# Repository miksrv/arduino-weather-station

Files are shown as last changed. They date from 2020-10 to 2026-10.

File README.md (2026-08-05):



<!-- PROJECT TITLE -->
Arduino Weather Station is a complete DIY weather-monitoring project powered by Arduino or ESP32. It collects real environmental data and provides a full backend API (PHP + MySQL + CodeIgniter) and a modern web interface (Next.js + Redux RTK) for real-time and historical weather analysis.
You can use this repository to build your own fully-featured weather station - and if you like it, please give the project a star :)

<div align="center">
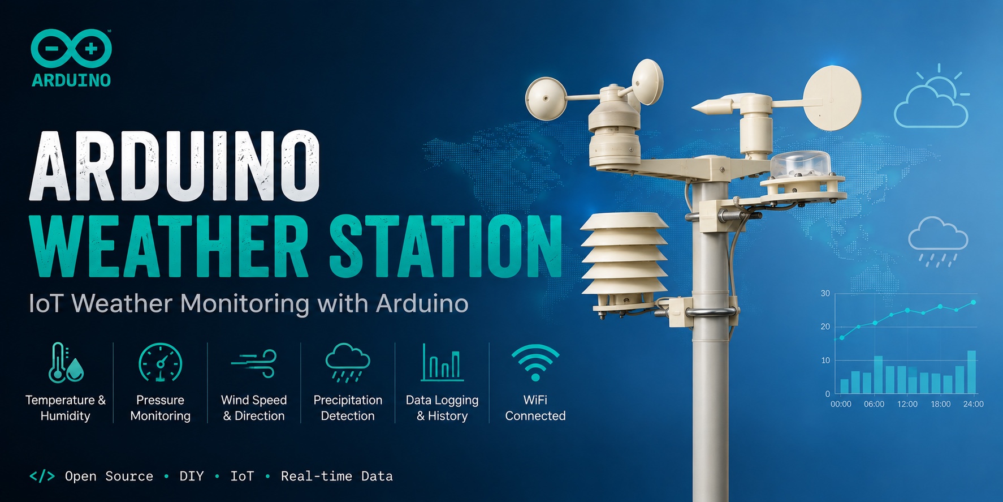
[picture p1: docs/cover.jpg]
  

<h3>Arduino Weather Station</h3>

<a href="https://meteo.miksoft.pro" target="_blank">Demo</a>
·
<a href="https://github.com/miksrv/arduino-weather-station/issues/new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">Report Bug</a>
·
<a href="https://github.com/miksrv/arduino-weather-station/issues/new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">Request Feature</a>
·
<a href="#contact">Contact</a>
</div>

<br />

<!-- PROJECT BADGES -->
<div align="center">

[][contributors-url]
[][forks-url]
[][stars-url]
[][issues-url]
[][license-url]







</div>

---

<!-- TABLE OF CONTENTS -->
### Table of Contents

- [About of Project](#about-of-project)
    - [Key Features](#key-features)
    - [Measured Parameters](#measured-parameters)
    - [Built With](#built-with)
- [Build Guide](#build-guide)
- [Installation](#installation)
- [Usage](#usage)
- [Screenshots and Demos](#screenshots-and-demos)
- [Contributing](#contributing)
- [License](#license)
- [Acknowledgments](#acknowledgments)
- [Contact](#contact)

## Documentation

Detailed documentation lives in the [`/docs`](./docs) directory:

- [Architecture](./docs/architecture.md) — system design, data flow, external services
- [Backend](./docs/backend.md) — PHP/CodeIgniter API reference and setup
- [Frontend](./docs/frontend.md) — Next.js app structure and development
- [Development Guide](./docs/development.md) — local setup, commands, conventions
- [Testing Guide](./docs/testing.md) — running tests, coverage, CI pipeline
- [Anomaly Monitor](./docs/anomaly-monitor.md) — meteorological anomaly detection, flood risk scoring, and visualization
- [Precipitation Calendar](./docs/precipitation-calendar.md) — annual rainfall calendar, daily totals, wet/dry streaks, and monthly breakdown

<!-- ABOUT OF PROJECT -->
## About of Project

Arduino Weather Station is a modular DIY platform for collecting and analyzing weather data. It supports Arduino or ESP32, works with a wide range of sensors, and sends real-time measurements to a backend server. Data is processed, stored, and exposed through a clean REST API and a modern Next.js dashboard.

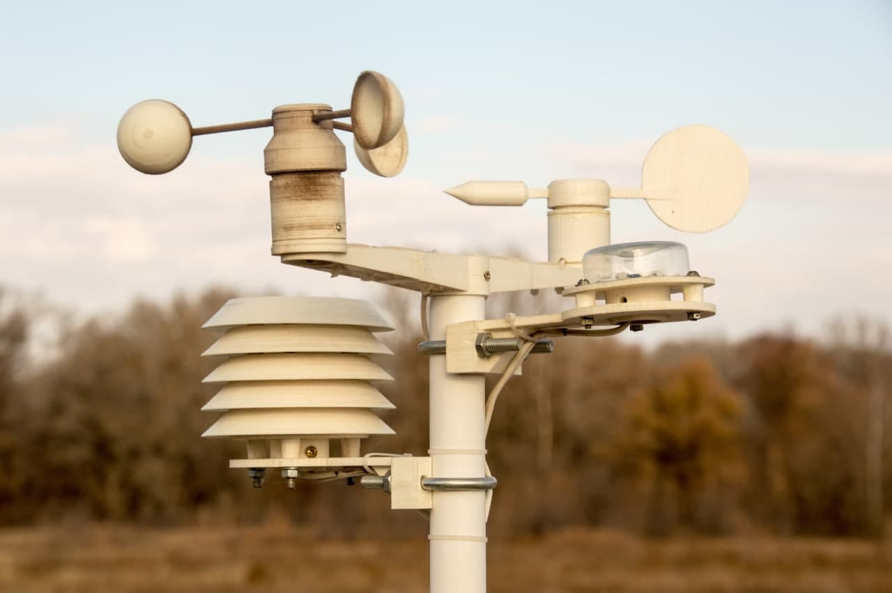
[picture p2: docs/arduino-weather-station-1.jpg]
Arduino Weather Station


### Key Features:
- **Live data**: continuous sensor monitoring.
- **Historical logging**: long-term storage in MySQL with detailed analytics.
- **Web dashboard**: access your station from anywhere — charts, stats, trends.
- **REST API**: integrate weather data into external apps or services.
- **Modular design**: easily add new sensors or expand the system.

### Measured Parameters:
- Temperature
- Feels like temperature
- Humidity
- Dew point
- UV intensity
- Solar energy
- Solar radiation
- Wind speed and direction
- Atmospheric pressure
- Precipitation levels
- Cloud cover

The system is highly customizable - from a small indoor sensor hub to a full outdoor weather station with complete data logging and visualization.

<p align="right">
  (<a href="#top">Back to top</a>)
</p>

### Built With

The Arduino Weather Station project leverages a wide range of technologies across various layers of the system:

- [][c++-url] Programming language used for the Arduino firmware.
- [][php-url] Server-side scripting language for the backend API.
- [][mysql-url] Database system for storing weather data.
- [][js-url] Core languages used in frontend development.
- [][ts-url] TypeScript extends JavaScript by adding types to the language.
- [][nextjs-url] React-based frontend framework for building the user interface.
- [][redux-url] State management for the frontend, providing predictable and centralized state.
- [][nodejs-url] JavaScript runtime used for frontend development and package management.
- [][sass-url] Styling the user interface.
- [][githubactions-url] Continuous integration and deployment pipeline for automating tests and deployment processes.
- [][sonarcloud-url] Code quality and security analysis.

This project also includes custom-designed components for measuring airflow, voltage, and light, making use of 3D printing for hardware integration.

<p align="right">
  (<a href="#top">Back to top</a>)
</p>

<!-- BUILD GUIDE -->
## Build Guide
This project is fairly extensive and includes hardware, firmware, backend, and frontend components. You can choose to build the entire weather station from start to finish, or you can use only the parts you need - whether it's the Arduino/ESP32 firmware, the server API, the 3D-printed enclosure, or the web dashboard.

The guide below walks you through each stage step by step: printing the enclosure, assembling the hardware, setting up the server, and configuring the client application.

### 3D Printing the Enclosure
All 3D-printable parts for the weather station are located in the [models](https://github.com/miksrv/arduino-weather-station/tree/main/models)
directory, which includes a detailed guide on recommended print settings, assembly notes, and an overview of each component.

The enclosure is fully modular and allows you to print only the parts needed for your specific sensor configuration. Most models are optimized for FDM 3D printers and require no supports unless otherwise noted.

Before printing, review the [Models README](./models/README.md) to choose the correct components and verify recommended materials and orientation.

<!-- INSTALLATION -->
## Installation

Follow these steps to install and run the Arduino Weather Station project on your local machine.

### Prerequisites

Make sure you have the following installed on your system:
- **Node.js** (v20 or higher)
- **NPM** or **Yarn** (for frontend dependencies)
- **PHP** (v8.2 or higher)
- **Composer** (for backend dependencies)
- **MySQL** (or any compatible database) — or **Docker** to run the bundled local database (see step 2 below)
- **Arduino IDE** (for programming the Arduino microcontroller)

### 1. Clone the repository

```bash
git clone https://github.com/miksrv/arduino-weather-station.git
cd arduino-weather-station
```

### 2. Backend Setup (PHP + CodeIgniter)

1. Navigate to the `server` folder:

   ```bash
   cd server
   ```

2. Install PHP dependencies using Composer:

   ```bash
   composer install
   ```

3. Start the local MySQL database using Docker (skip this if you already have a MySQL-compatible database running):

   ```bash
   docker-compose -f ../config/docker-compose.yml up -d
   ```

4. Create a `.env` file and configure your environment variables, such as database connection settings:

   ```bash
   cp env .env
   ```

    The default `database.development.*` values already match the docker-compose database from step 3, so no changes are needed if you used Docker. Don't forget to set the parameter `app.arduino.token` = '' in the .env file. This token will be used for proper authentication of the Arduino weather station when transmitting data to the server. The same token will need to be set in the Arduino sketch, which will be described in step 4.

5. Migrate the database:

   ```bash
   php spark migrate
   ```

6. Start the backend server (built-in PHP server or any web server of your choice):

   ```bash
   php spark serve
   ```

### 3. Frontend Setup (Next.js + Redux)

1. Navigate to the `client` folder:

   ```bash
   cd ../client
   ```
   
2. Copy file `env` to `.env.local` and set the following environment variables:

   ```bash
   cp env .env.local
   ```
   
    ```bash
    NEXT_PUBLIC_API_HOST = 'http://localhost:8080/'
    NEXT_PUBLIC_SITE_LINK = 'http://localhost:3000/'
    NEXT_PUBLIC_STORAGE_KEY = 'meteo'
    ```

3. Install frontend dependencies:

   ```bash
   yarn install
   ```

4. Run the frontend in development mode:

   ```bash
   yarn run dev
   ```

5. To build the project for production:

   ```bash
   yarn run build
   ```

6. Optionally, start the production build:

   ```bash
   yarn start
   ```

### 4. Arduino Setup

1. Open the [Arduino Readme](./arduino/README.md) — it includes the full wiring diagram (which pin/wire connects to which component).
2. Open the Arduino sketch from the `arduino/main` folder in the Arduino IDE.
3. Configure the following parameters in the `main.ino` file for Arduino:
   - `API_SERVER` - the server address for sending data from the weather station.
   - `API_METHOD` - the correct method (if you haven't changed anything in the server settings in this repository, you don't need to change it).
   - `API_SECRET` - your secret for server authentication, the same secret key set in step 2 during server setup.
   - Make sure the Arduino sensors are connected to the correct pins, or simply reassign them: `PIN_ANEMOMETR`, `PIN_DHT22`, `PIN_UV_OUT`, `PIN_UV_REF`
3. Before compiling, make sure to install the required libraries:
    - Extract the **BMP085_Library.zip** and **PCF8574_Library.zip** archives from the `/arduino` directory into the `libraries` folder of your Arduino IDE.
4. Connect your Arduino microcontroller and upload the sketch.
5. Ensure the Arduino is correctly wired with the sensors for proper functionality.

#### Arduino Components:

- **BMP085**: Barometric pressure sensor
- **BH1750**: Light sensor
- **DHT22**: Temperature and humidity sensor
- **PCF8574**: I2C expander for wind direction
- **GUML8511**: UV sensor
- **Anemometer**: Measures wind speed
- **Wind Vane**: Measures wind direction

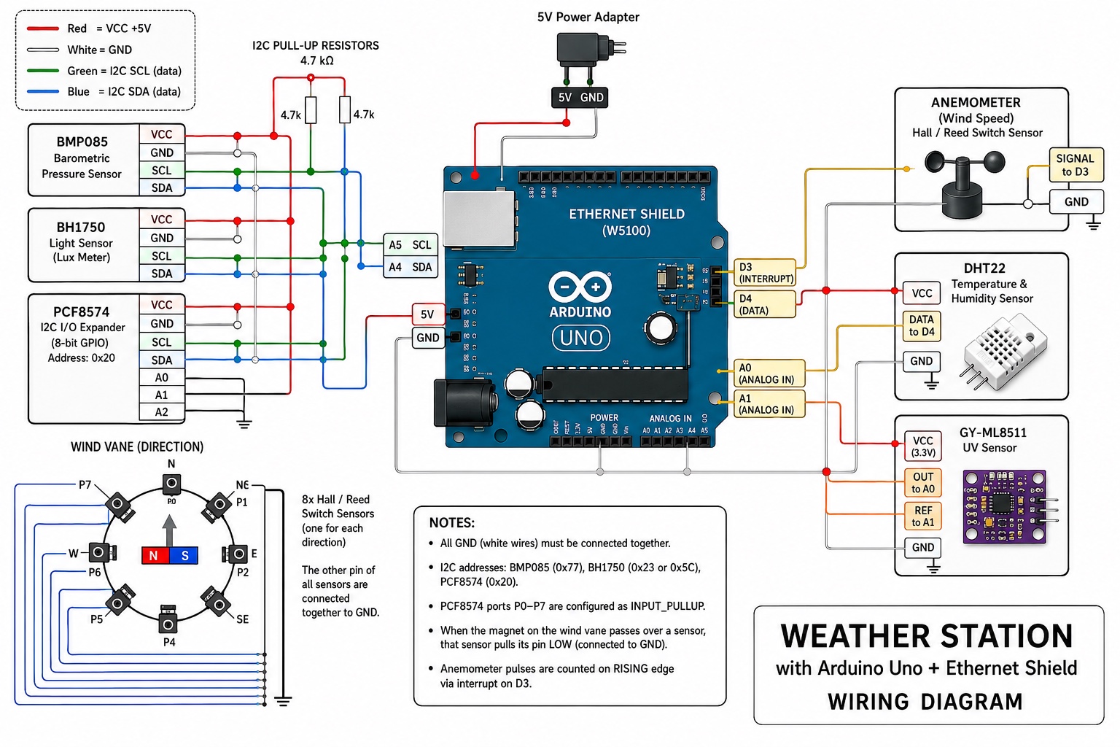
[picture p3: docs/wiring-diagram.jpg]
Weather Station Wiring Diagram


All models for 3D printing can be found in the `models` directory.

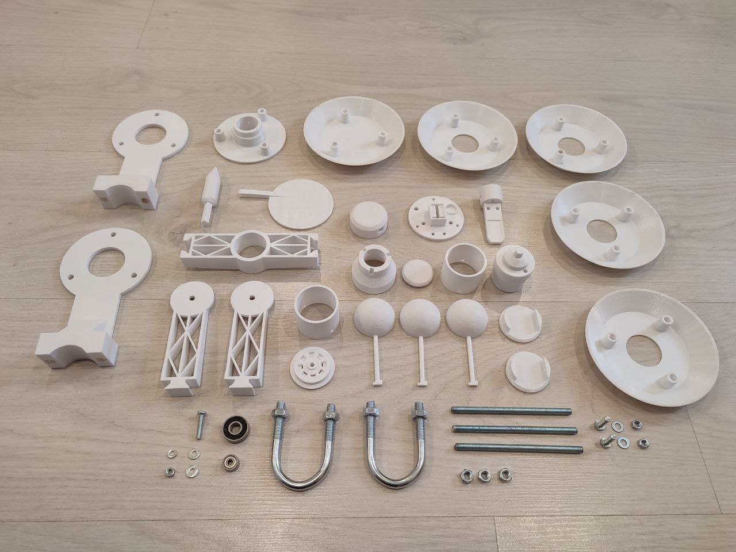
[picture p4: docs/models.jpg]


**Which filament / print settings should I use?** Don't overthink it - any
filament with default slicer settings works fine, and none of the parts need
supports. My own enclosure has been printed in plain **ABS** with default
settings, and it's been mounted outdoors since 2021, through everything from
+44°C summer sun to -37°C winter frost - nothing has cracked, warped, or
fallen apart.

### 5. Accessing the Application

Once the backend and frontend servers are running, access the weather station UI by visiting:

```
http://localhost:3000
```

You can now monitor real-time and historical weather data from the Arduino Weather Station!

<p align="right">
  (<a href="#top">Back to top</a>)
</p>

<!-- USAGE -->
## Usage

After successfully installing and setting up the Arduino Weather Station project, follow these steps to start using the application and monitor weather data.

### 1. Access the Web Interface

- Open your browser and navigate to the frontend running at `http://localhost:3000` (or the production URL if deployed).
- You will see a dashboard displaying current weather conditions as well as the option to view historical data.

### 2. Real-Time Weather Data

- The dashboard updates weather data in real-time, pulling data from the Arduino sensors connected to your weather station.
- Key metrics displayed include:
    - **Temperature**
    - **Humidity**
    - **Dew Point**
    - **UV Index**
    - **Wind Speed & Direction**
    - **Pressure**
    - **Precipitation**
    - **Solar Radiation**

### 3. Historical Data

- Navigate to the **History** page from the main menu.
- Choose a date range to view weather trends and archived data, including charts for various metrics like temperature, wind, and humidity.

<div align="center">

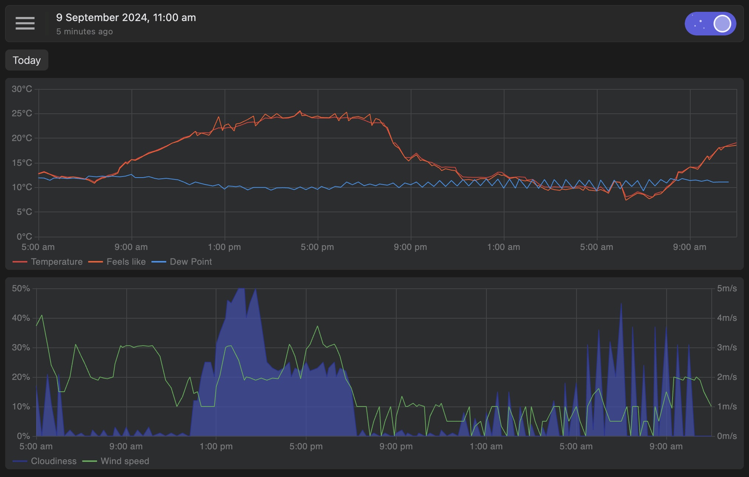
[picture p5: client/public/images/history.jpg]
Weather Station User Interface - History Page
    

</div>

### 4. Customize Data Display

- You can customize the data display to show or hide specific sensors on the dashboard.
- For example, toggle between temperature readings, feels-like temperature, and dew point, or switch between solar energy and solar radiation.

### 5. Arduino Sensor Calibration

- For accurate readings, you may need to calibrate some sensors depending on your specific environment. Refer to the Arduino sketch in the `arduino/` folder to adjust the calibration values for sensors such as temperature or pressure.

### 6. Data Export

- Weather data can be exported from the **History** page in various formats (e.g., CSV) to analyze trends further.

### 7. System Maintenance

- The backend server running on PHP + CodeIgniter is responsible for handling incoming data from the Arduino sensors and storing it in a MySQL database. Ensure the backend is running to avoid data loss.
- The frontend is built with Next.js and provides a smooth interface to view, interact with, and analyze weather data.

### 8. Arduino Weather Station Features

- **Real-time Monitoring**: Monitor real-time weather conditions using connected sensors.
- **Historical Data**: Review weather history with customizable date ranges.
- **Graphical Visualizations**: View weather trends and patterns using interactive charts.
- **Sensor Readings**: Monitor multiple environmental factors, such as UV Index, wind speed, and solar radiation.

## CLI Commands & Cron Jobs

The backend exposes several `php spark` commands for pulling external weather data, computing aggregates, and maintaining the anomaly log. These are intended to be scheduled via cron on the server running the PHP backend.

### Available Commands

| Command | Description |
|---|---|
| `php spark system:getCurrentWeather` | Fetches current weather observations from all configured external APIs (VisualCrossing, WeatherAPI, OpenWeatherMap, Open-Meteo), saves new records to `raw_weather_data`, and recalculates hourly and daily averages. |
| `php spark system:getForecastWeather` | Fetches forecast data from all configured external APIs and bulk-upserts records into `forecast_weather_data`. |
| `php spark system:sendNarodmonData` | Retrieves the latest sensor reading from the database and pushes it to the [narodmon.ru](https://narodmon.ru) monitoring service. |
| `php spark system:detectAnomalies` | Runs all meteorological anomaly checks against today's daily and hourly data and updates the `anomaly_log` table. Must run after daily averages are available. |
| `php spark system:backfillAnomalyLog` | Iterates all historical daily records and populates `anomaly_log` from scratch. Intended for initial bootstrapping. Accepts `--force` to bypass the non-empty table guard. |

### Recommended Schedule

| Command | Frequency | Rationale |
|---|---|---|
| `system:getCurrentWeather` | Every hour | Keeps raw observations and hourly/daily averages up to date. |
| `system:getForecastWeather` | Every 3–6 hours | Forecast data changes slowly; 4-hour intervals balance freshness against API quota. |
| `system:sendNarodmonData` | Every 15 minutes | Near-real-time push to the public monitoring network. |
| `system:detectAnomalies` | Once daily (e.g. 01:30) | Runs after midnight when the previous day's daily averages are fully computed. |
| `system:backfillAnomalyLog` | One-time / manual | Run once on a fresh deployment to seed historical anomaly records. |

### Example Crontab

Add the entries below to your server's crontab (`crontab -e`). Adjust `/var/www/project/server` to match your actual deployment path.

```cron
# Fetch current weather from external APIs and recalculate averages — every hour
0 * * * * cd /var/www/project/server && php spark system:getCurrentWeather >> /var/log/weather.log 2>&1

# Fetch forecast data — every 4 hours
0 */4 * * * cd /var/www/project/server && php spark system:getForecastWeather >> /var/log/weather.log 2>&1

# Push latest reading to narodmon.ru — every 15 minutes
*/15 * * * * cd /var/www/project/server && php spark system:sendNarodmonData >> /var/log/weather.log 2>&1

# Run anomaly detection — daily at 01:30 (after daily averages are ready)
30 1 * * * cd /var/www/project/server && php spark system:detectAnomalies >> /var/log/weather.log 2>&1
```

> **Note:** `system:backfillAnomalyLog` is a one-time maintenance command and should not be added to cron. Run it manually once after a fresh deployment:
> ```bash
> cd /var/www/project/server && php spark system:backfillAnomalyLog
> ```

<p align="right">
  (<a href="#top">Back to top</a>)
</p>

## Screenshots and Demos

#### 1. **Current Weather Overview**

The **Current** section provides real-time data on the current weather conditions, including temperature, humidity, UV index, and more. Users can quickly view all key environmental metrics at a glance.

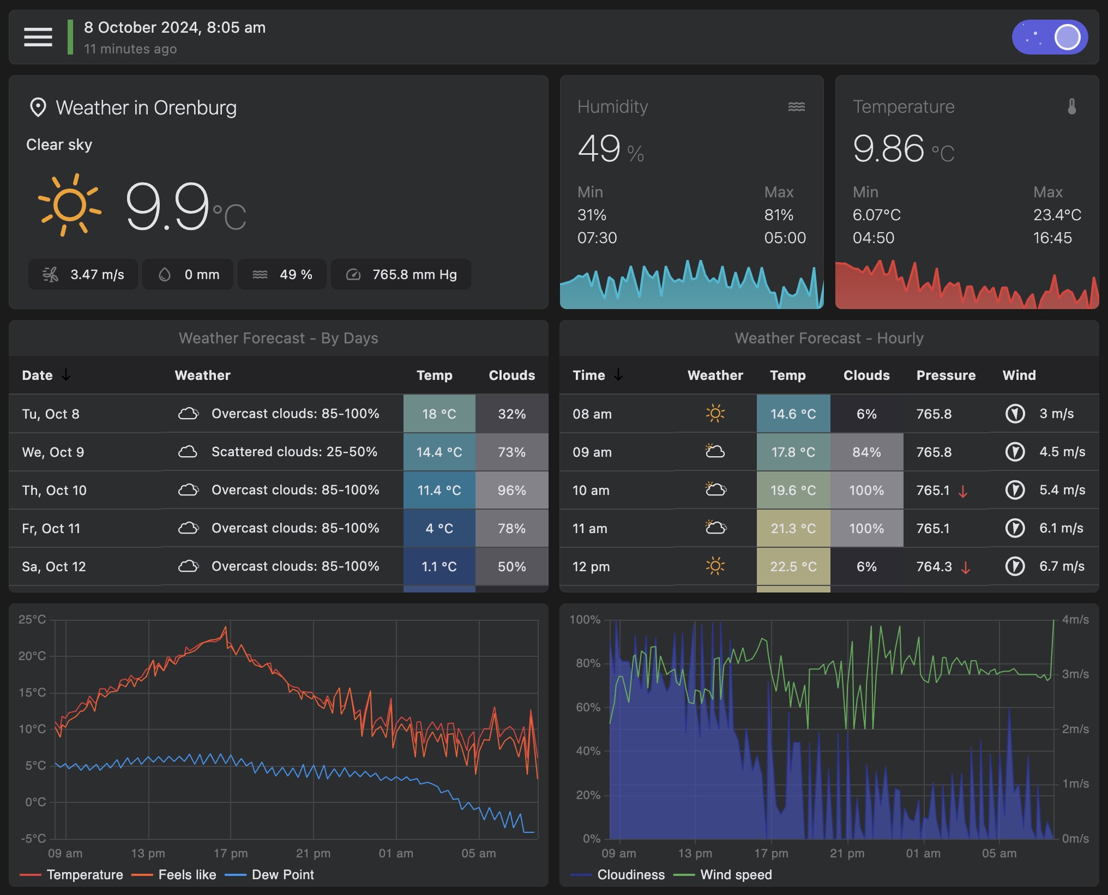
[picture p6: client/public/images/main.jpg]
Current Weather Interface


#### 2. **Sensors Dashboard**

The **Sensors** section displays a list of all connected weather sensors, including temperature, pressure, wind speed, and solar radiation. This section gives users an in-depth view of each sensor's status and real-time readings.

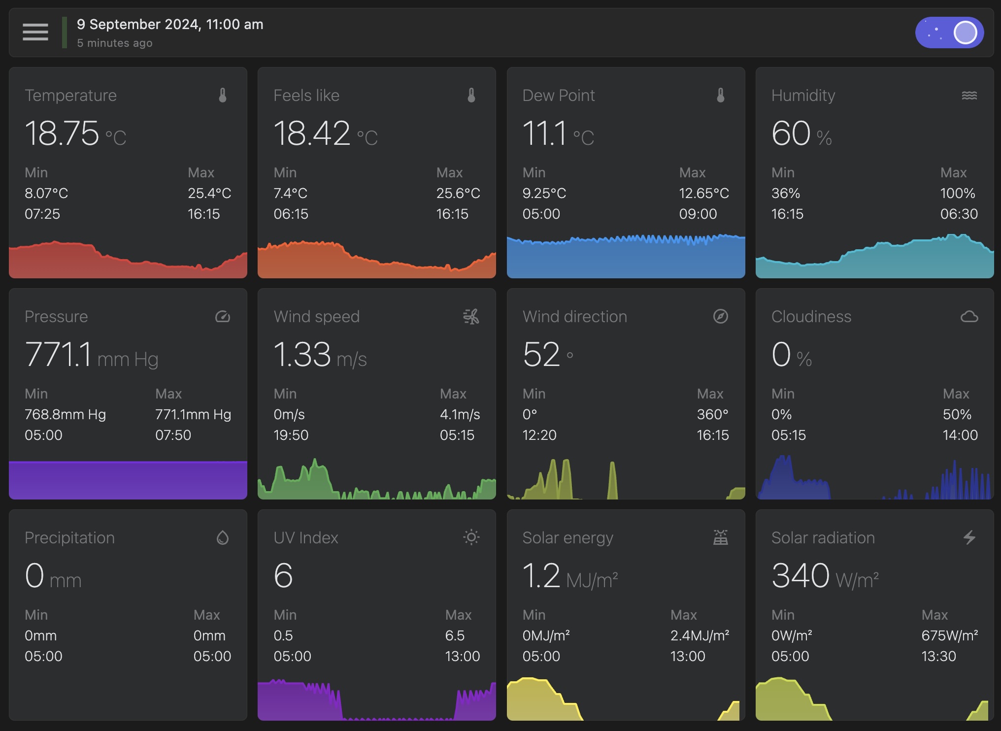
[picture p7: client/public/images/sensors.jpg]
Sensors Dashboard


#### 3. **Weather History and Trends**

The **History** section allows users to explore weather data over a specified time period. Interactive charts provide insights into trends for various weather metrics like temperature, wind speed, and humidity.

History Interface

#### 4. **Forecast**

The **Forecast** section offers a comprehensive weather outlook for the next five days, accompanied by a detailed breakdown for the current day. Users can access forecasts for temperature, precipitation, wind speed, humidity, and more, presented in an intuitive interface. This section is designed to help users plan their activities with precision by providing accurate, easy-to-read weather data for both short-term and extended periods.

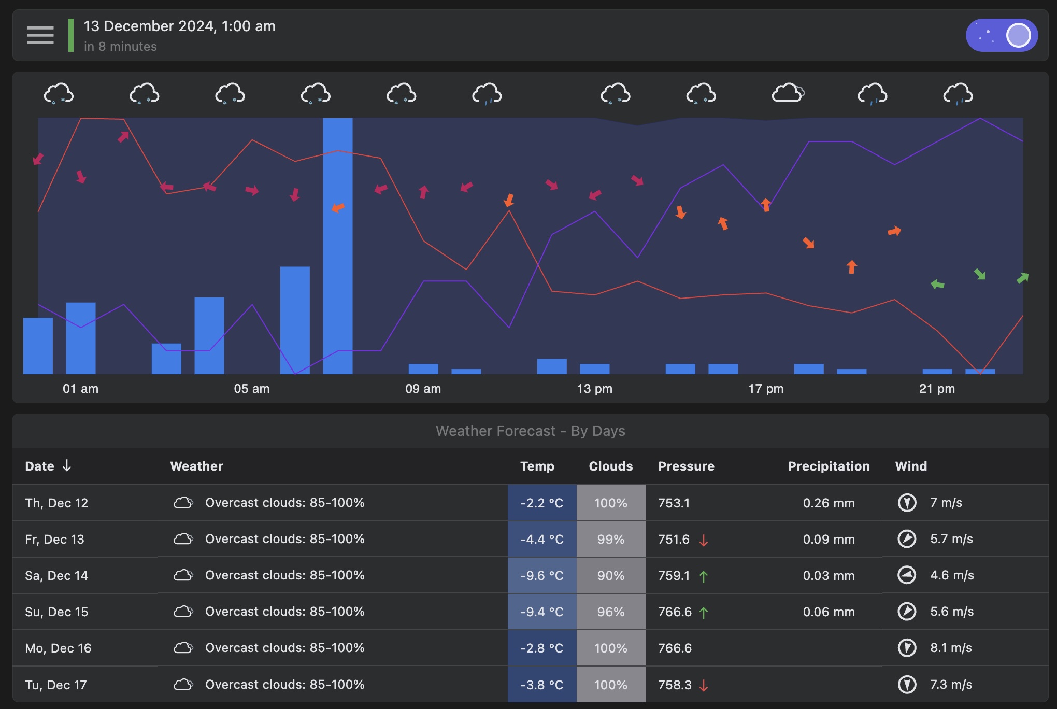
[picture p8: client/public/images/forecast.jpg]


#### 5. **Heatmap**

The **Heatmap** section provides a detailed visualization of weather metrics, including temperature, pressure, humidity, precipitation, and cloud coverage, displayed as a heatmap. Users can select any time period to view trends and patterns across multiple environmental factors at once. This powerful tool allows for quick comparison and in-depth analysis of weather conditions over time.

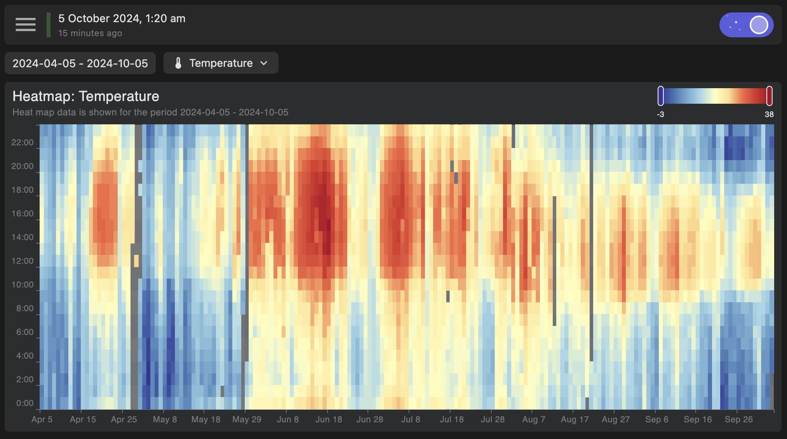
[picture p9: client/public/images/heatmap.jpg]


#### 6. **Climate Dashboard**

The **Climate** page is a multi-widget climate science dashboard that surfaces long-term environmental trends from the station's full historical record. Five visualizations make warming and precipitation shifts immediately legible:

| Widget | Description |
|---|---|
| **Warming Stripes** | One color-coded stripe per year — deep blue (cold years) through white (baseline) to deep red (warm years). Inspired by Ed Hawkins' iconic "Show Your Stripes" graphic. |
| **Temperature Anomaly** | Bar chart of annual deviation from the long-term mean. Red bars = warmer than average, blue = cooler. A linear trend line is overlaid automatically. |
| **Monthly Climate Normals** | Band chart showing the all-time min/max envelope and historical mean per calendar month, with the current year's actual values overlaid. |
| **Annual Precipitation** | Yearly total rainfall bars (blue = above average, amber = below average) plus a linear trend line and a plain-language trend label. |
| **Extreme Event Days** | Grouped bars counting frost days (< 0 °C), hot days (≥ 30 °C), and heavy-rain days (≥ 10 mm) per year. |

All five widgets are powered by the new `GET /climate` endpoint, which returns pre-aggregated statistics computed server-side from `daily_averages`. The response is cached indefinitely (TTL = 0) because the underlying data changes at most once per year.

#### Live Demo

Explore the fully functioning weather station web application at:  
🌐 [Live Demo](https://meteo.miksoft.pro/en)

<p align="right">
  (<a href="#top">Back to top</a>)
</p>

<!-- CONTRIBUTING -->
## Contributing

Contributions are what make the open-source community an incredible environment for learning, inspiration, and innovation. Your contributions are highly valued and greatly appreciated, whether it’s reporting bugs, suggesting improvements, or creating new features.

**To contribute:**

1. Fork the project by clicking the "Fork" button at the top of this page.
2. Clone your fork locally:
   ```bash
   git clone https://github.com/miksrv/arduino-weather-station.git
   ```
3. Create a new feature branch:
   ```bash
   git checkout -b feature/AmazingFeature
   ```
4. Make your changes, then commit them:
   ```bash
   git commit -m "Add AmazingFeature"
   ```
5. Push your changes to your forked repository:
   ```bash
   git push origin feature/AmazingFeature
   ```
6. Open a pull request from your feature branch to the main repository.

We encourage contributions of all kinds, whether big or small. Your efforts help improve the project for everyone!

## License

<!-- LICENSE -->
Distributed under the MIT License. See [LICENSE](LICENSE) for more information.

<p align="right">
  (<a href="#top">Back to top</a>)
</p>

<!-- ACKNOWLEDGEMENTS -->
## Acknowledgments

This section is dedicated to recognizing the resources and individuals that have been invaluable to this project. I’d like to highlight a few key tools and contributions that made a significant impact on its development. Feel free to explore them as they may be useful for your own projects!

1. [CodeIgniter](https://codeigniter.com/user_guide/helpers/date_helper.html)
2. [Simple React UI](https://github.com/miksrv/simple-react-ui-kit)
3. [Weather Icons](https://erikflowers.github.io/weather-icons/)
4. [Meteocons](https://bas.dev/work/meteocons)

<p align="right">
  (<a href="#top">Back to top</a>)
</p>

## Contact

Misha - [miksoft.pro](https://miksoft.pro)

<p align="right">
  (<a href="#top">Back to top</a>)
</p>

<!-- MARKDOWN VARIABLES (LINKS, IMAGES) -->
[contributors-badge]: https://img.shields.io/github/contributors/miksrv/arduino-weather-station.svg?style=for-the-badge
[contributors-url]: https://github.com/miksrv/arduino-weather-station/graphs/contributors
[forks-badge]: https://img.shields.io/github/forks/miksrv/arduino-weather-station.svg?style=for-the-badge
[forks-url]: https://github.com/miksrv/arduino-weather-station/network/members
[stars-badge]: https://img.shields.io/github/stars/miksrv/arduino-weather-station.svg?style=for-the-badge
[stars-url]: https://github.com/miksrv/arduino-weather-station/stargazers
[issues-badge]: https://img.shields.io/github/issues/miksrv/arduino-weather-station.svg?style=for-the-badge
[issues-url]: https://github.com/miksrv/arduino-weather-station/issues
[license-badge]: https://img.shields.io/github/license/miksrv/arduino-weather-station.svg?style=for-the-badge
[license-url]: https://github.com/miksrv/arduino-weather-station/blob/master/LICENSE.txt

<!-- Other ready-made icons can be seen for example here: https://github.com/inttter/md-badges -->
[js-badge]: https://img.shields.io/badge/JavaScript-F7DF1E?logo=javascript&logoColor=000
[js-url]: https://www.javascript.com/
[ts-badge]: https://img.shields.io/badge/TypeScript-3178C6?logo=typescript&logoColor=fff
[ts-url]: https://www.typescriptlang.org/
[nextjs-badge]: https://img.shields.io/badge/Next.js-black?logo=next.js&logoColor=white
[nextjs-url]: https://nextjs.org/
[nodejs-badge]: https://img.shields.io/badge/Node.js-6DA55F?logo=node.js&logoColor=white
[nodejs-url]: https://nodejs.org/
[redux-badge]: https://img.shields.io/badge/Redux-764ABC?logo=redux&logoColor=fff
[redux-url]: https://redux.js.org/
[sass-badge]: https://img.shields.io/badge/Sass-C69?logo=sass&logoColor=fff
[sass-url]: https://sass-lang.com/
[c++-badge]: https://img.shields.io/badge/C++-%2300599C.svg?logo=c%2B%2B&logoColor=white
[c++-url]: https://cplusplus.com/
[php-badge]: https://img.shields.io/badge/php-%23777BB4.svg?&logo=php&logoColor=white
[php-url]: https://www.php.net/
[mysql-badge]: https://img.shields.io/badge/MySQL-4479A1?logo=mysql&logoColor=fff
[mysql-url]: https://www.mysql.com/
[sonarcloud-badge]: https://img.shields.io/badge/SonarCloud-F3702A?logo=sonarcloud&logoColor=fff
[sonarcloud-url]: https://sonarcloud.io/
[githubactions-badge]: https://img.shields.io/badge/GitHub_Actions-2088FF?logo=github-actions&logoColor=white
[githubactions-url]: https://docs.github.com/en/actions

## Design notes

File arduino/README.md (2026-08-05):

# Weather Station

## Table of Contents

- [Overview](#overview)
- [Components](#components)
- [Wiring Diagram](#wiring-diagram)
- [Files](#files)
  - [`main.ino`](#mainino)
  - [`get_sensor_dht22.ino`](#get_sensor_dht22ino)
  - [`get_sensor_wind_direction.ino`](#get_sensor_wind_directionino)
  - [`get_sensor_luxmeter.ino`](#get_sensor_luxmeterino)
  - [`get_sensor_pressure.ino`](#get_sensor_pressureino)
  - [`get_sensor_uvindex.ino`](#get_sensor_uvindexino)
  - [`webclient_send_data.ino`](#webclient_send_dataino)
- [Setup](#setup)
- [Usage](#usage)
  - [Debugging](#debugging)
  - [`i2c_scanner.ino`](#i2c_scannerino)
  - [`test_gyml8511.ino`](#test_gyml8511ino)
  - [`test_interput.ino`](#test_interputino)
  - [`test_pcf8574.ino`](#test_pcf8574ino)
- [Notes](#notes)

## Overview

This project is a weather station built with an Arduino that collects and sends various environmental data, including temperature, humidity, wind speed, wind direction, barometric pressure, UV index, and light levels. The data is sent to a web server for remote monitoring.

Before running and compiling the code, ensure that the required libraries are installed in your Arduino IDE:

1. **Install BMP085_Library.zip and PCF8574_Library.zip**  
   Place the library archives in the `libraries` folder of your Arduino IDE and extract them. Alternatively, you can use the Arduino Library Manager to include these libraries if they are available.

2. **Optionally, use the latest version of the Adafruit BMP085 library**  
   If you prefer to use the updated Adafruit BMP085 library for the pressure sensor, install it via the Arduino Library Manager. Note that using the updated library may require slight modifications to the sketch `get_sensor_pressure.ino` to align with the updated library's API.

This ensures that all dependencies are correctly set up for the successful compilation and functionality of your weather station.

## Components

- **BMP085**: Barometric pressure sensor
- **BH1750**: Light sensor
- **DHT22**: Temperature and humidity sensor
- **PCF8574**: I2C expander for wind direction
- **GUML8511**: UV sensor
- **Anemometer**: Measures wind speed
- **Wind Vane**: Measures wind direction

## Wiring Diagram

Weather Station Wiring Diagram

Wire colors used throughout this section:

- **Red** — VCC (+5V, or +3.3V where noted)
- **White** — GND
- **Green** — Data / I2C SCL
- **Blue** — Data / I2C SDA

Sensors are connected to the Arduino as follows:

| Sensor | Power | Data / Signal |
|---|---|---|
| BMP085 | VCC -> 5V, GND -> GND | I2C (SCL, SDA) |
| BH1750 | VCC -> 5V, GND -> GND | I2C (SCL, SDA) |
| PCF8574 (Wind Vane expander) | VCC -> 5V, GND -> GND | I2C (SCL, SDA) |
| Anemometer | — (2-wire reed switch) | Digital PIN 3 (interrupt), other lead -> GND |
| DHT22 | VCC -> 5V, GND -> GND | Digital PIN 4 |
| UV Sensor (GY-ML8511) | VCC -> 3.3V, GND -> GND | Analog PIN A0 (UV OUT), Analog PIN A1 (UV REF) |

BMP085, BH1750, and the PCF8574 all share the same I2C bus (SDA/SCL), wired in
parallel (daisy-chained), with pull-up resistors on SDA and SCL if your
breakout boards don't already provide them.

### Wind Vane (via PCF8574)

The wind vane itself is not read directly by the Arduino — it goes through the
**PCF8574**, an 8-bit I2C I/O expander (address `0x20` in `main.ino`, set via
its `A0`/`A1`/`A2` address pins tied to GND). This is **not** a shift register;
it's a general-purpose I2C port expander used here to multiplex 8 digital
inputs onto the shared I2C bus.

- PCF8574 `VCC` -> 5V, `GND` -> GND, `SCL`/`SDA` -> shared I2C bus
- PCF8574 address pins `A0`, `A1`, `A2` -> GND (address `0x20`)
- The vane has **8 reed/hall-effect switches**, one per compass direction (N,
  NE, E, SE, S, SW, W, NW). Each switch is wired between one PCF8574 port
  (`P0`...`P7`) and a common GND
- Every port `P0`-`P7` is configured in firmware as `INPUT_PULLUP`, so a port
  reads `HIGH` when idle and is pulled `LOW` only when its switch closes
- As the vane rotates, its magnet passes over one sensor at a time, pulling
  the matching port `LOW`; `get_sensor_wind_direction()` scans all 8 ports and
  reports the index of the active one as the current wind direction

## Files

### `main.ino`

The main file that initializes the sensors, manages the main loop, and sends data to the web server. It includes:

- Initialization of sensors and network settings
- Main loop to periodically read sensor data and send it to the server

### `get_sensor_dht22.ino`

Contains functions to read data from the DHT22 temperature and humidity sensor. It includes:

- `get_sensor_dht22()`: Reads temperature and humidity values
- Data conversion and debugging output

### `get_sensor_wind_direction.ino`

Handles reading the wind direction using an I2C expander. It includes:

- `get_sensor_wind_direction()`: Reads wind direction from the wind vane
- Data processing and debugging output

### `get_sensor_luxmeter.ino`

Reads light levels from the BH1750 light sensor. It includes:

- `get_sensor_luxmeter()`: Reads and processes light level data
- Data conversion and debugging output

### `get_sensor_pressure.ino`

Manages data collection from the BMP085 barometric pressure sensor. It includes:

- `get_sensor_pressure()`: Reads and processes atmospheric pressure
- Data conversion and debugging output

### `get_sensor_uvindex.ino`

Handles UV index readings from the GUML8511 UV sensor. It includes:

- `get_sensor_uvindex()`: Reads and calculates UV index
- Data conversion and debugging output

### `webclient_send_data.ino`

Handles sending collected sensor data to the web server. It includes:

- `webclient_send_data()`: Formats and sends data to the specified API endpoint
- Network connection and data transmission

## Setup

1. **Hardware Connections**: Follow the wiring diagram to connect sensors to the Arduino.
2. **Libraries**: Ensure you have the following libraries installed:
   - `Wire.h`
   - `BMP085.h`
   - `TroykaDHT.h`
   - `BH1750.h`
   - `PCF8574.h`
   - `SPI.h`
   - `Ethernet.h`
3. **API Configuration**: Update `API_SERVER`, `API_METHOD`, and `API_SECRET` in `main.ino` with your API server address and credentials.
4. **Upload Code**: Upload all `.ino` files to your Arduino. The Arduino IDE will automatically handle file organization.

## Usage

The weather station will periodically collect data from all sensors and send it to the specified web server. The data is sent every 60 seconds, as defined by `SEND_DATA_INTERVAL` in `main.ino`.

## Debugging

- **Serial Monitor**: Enable the debug messages by uncommenting the `#define DEBUG` line in `main.ino`. This will print sensor readings and status messages to the Serial Monitor.

In additional directories you can find auxiliary files for debugging and testing electronic components:

### 1. `i2c_scanner.ino`

**Purpose:**  
This sketch scans the I2C bus for connected devices and prints their addresses to the Serial Monitor. It helps in identifying the addresses of I2C devices connected to the Arduino.

**Usage:**
1. Upload the sketch to your Arduino board.
2. Open the Serial Monitor (set to 9600 baud).
3. The sketch will start scanning and display the addresses of any detected I2C devices.
4. If no devices are found, it will indicate that no I2C devices are connected.

**Code Explanation:**
- `Wire.begin()`: Initializes the I2C bus.
- `Wire.beginTransmission(address)` and `Wire.endTransmission()`: Test each address for an I2C device.
- Addresses from `0x01` to `0x7F` are scanned.

### 2. `test_gyml8511.ino`

**Purpose:**  
This sketch reads data from an MP8511 UV sensor and calculates UV intensity. It prints the sensor's output voltage and UV intensity to the Serial Monitor.

**Usage:**
1. Connect the MP8511 sensor to the Arduino.
2. Upload the sketch to your Arduino board.
3. Open the Serial Monitor (set to 9600 baud).
4. The sketch will display the sensor's output and UV intensity in real-time.

**Code Explanation:**
- `averageAnalogRead(pinToRead)`: Averages multiple analog readings to improve accuracy.
- `mapfloat(x, in_min, in_max, out_min, out_max)`: Maps a float value from one range to another.
- UV intensity is calculated based on the sensor's output voltage.

### 3. `test_interput.ino`

**Purpose:**  
This sketch measures RPM (Revolutions Per Minute) using a Hall effect sensor and an interrupt. It prints the time elapsed and RPM to the Serial Monitor.

**Usage:**
1. Connect a Hall effect sensor to the interrupt pin (pin 2 on the Arduino UNO).
2. Upload the sketch to your Arduino board.
3. Open the Serial Monitor (set to 9600 baud).
4. The sketch will print the time elapsed and RPM values based on the number of sensor pulses.

**Code Explanation:**
- `attachInterrupt(digitalPinToInterrupt(sensorPin), addValue, RISING)`: Attaches an interrupt to count sensor pulses.
- `addValue()`: Increment the pulse count.
- RPM is calculated based on the time elapsed and number of pulses.

### 4. `test_pcf8574.ino`

**Purpose:**  
This sketch reads inputs from a PCF8574 I/O expander and displays the wind direction based on the digital input values.

**Usage:**
1. Connect the PCF8574 I/O expander to the Arduino via I2C.
2. Upload the sketch to your Arduino board.
3. Open the Serial Monitor (set to 9600 baud).
4. The sketch will display the wind direction as detected by the PCF8574 expander.

**Code Explanation:**
- `expander.pinMode(i, INPUT_PULLUP)`: Configures all pins of the PCF8574 as inputs with pull-up resistors.
- `expander.digitalRead(i)`: Reads the state of each pin.
- The wind direction is derived from the digital input values.

## Notes

- Ensure the correct board and port are selected in the Arduino IDE before uploading the sketches.
- Adjust pin numbers and I2C addresses in the sketches as needed for your specific hardware configuration.

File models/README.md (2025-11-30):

# **3D Models for the DIY Weather Station**

This directory contains all 3D-printable components used in the DIY Arduino/ESP32 Weather Station.  
Each model is designed to be simple, robust, and suitable for budget-level 3D printers.

All models were originally printed on a very basic **Anet A6** (one of the simplest consumer-grade printers) using **ABS filament**.  
Despite the low-end hardware, the enclosure has survived **4+ years outdoors** without deformation or degradation.

For best durability, it is recommended to print using:

- **PETG** (preferred for UV resistance and outdoor conditions)
- or **ABS** (tested and proven to work long-term)

Print the parts in **white filament only** - this significantly improves reflectivity, reduces solar heating, and minimizes UV exposure.

---

# **Contents**

1. [Radiation Shield](#radiation-shield)
2. [DHT22 + BMP085 Mount](#dht22--bmp085-mount)
3. [Anemometer](#anemometer)
4. [Sensors Holder](#sensors-holder)
5. [Wind Direction Sensor](#wind-direction-sensor)

---

## Radiation Shield
Weather station radiation shield for accurate air temperature and humidity measurement. Designed to protect sensors from direct sunlight, rain, and reflected heat while allowing free airflow. 

This directory also includes adapters for mounting different temperature and humidity sensors.

### **rad_shd.stl** - shield plate
One of the main plate elements of the radiation shield. Forms the layered structure that blocks direct sunlight.

**Quantity:** 4 pcs (minimum required to fit the sensor adapter).

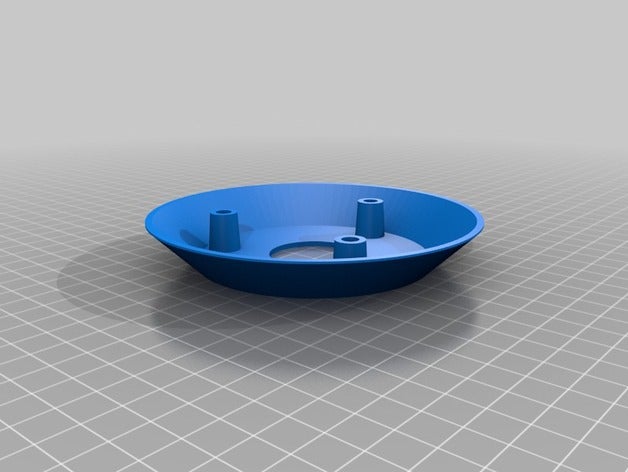
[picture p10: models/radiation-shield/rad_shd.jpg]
rad_shd


### **rad_shd_base.stl** - bottom base
The bottom foundation of the shield assembly. The first layer onto which the plates are stacked.

**Quantity:** 1 pc.

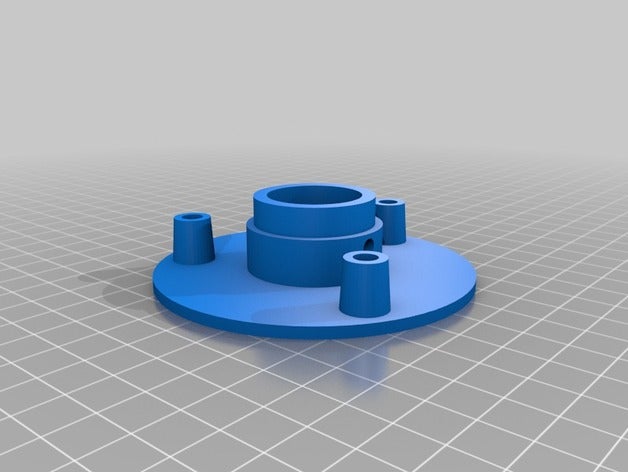
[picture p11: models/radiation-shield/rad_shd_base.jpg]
rad_shd_base


### **rad_shd_top.stl** - top cover
The uppermost element that closes the radiation shield. Protects from precipitation and locks the structure together.

**Quantity:** 1 pc.

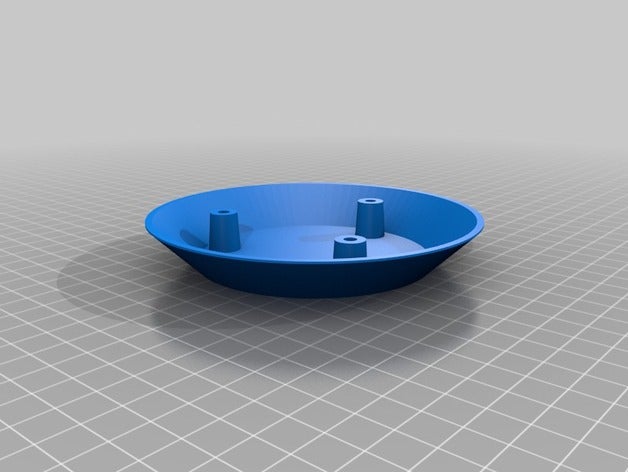
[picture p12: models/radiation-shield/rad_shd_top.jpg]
rad_shd_top


### **rad_shd_vert_mount.stl** - vertical mount
Mounting bracket for attaching the radiation shield to a pipe or vertical pole.

**Quantity:** 1 pc.

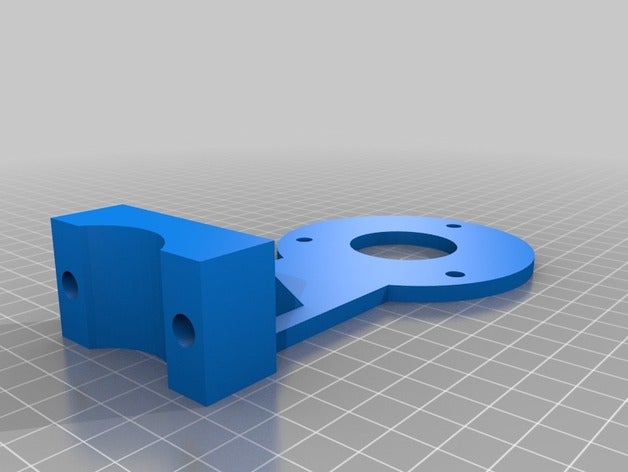
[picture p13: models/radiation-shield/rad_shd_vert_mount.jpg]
rad_shd_vert_mount


---

## DHT22 + BMP085 Mount
This is a combined sensor mount designed to hold both the **DHT22** (temperature and humidity) and **BMP085** (barometric pressure) sensors.  
The mount is sized to fit directly inside the **Radiation Shield**, ensuring proper airflow and protection from direct sunlight.

**Quantity:** 1 pc.

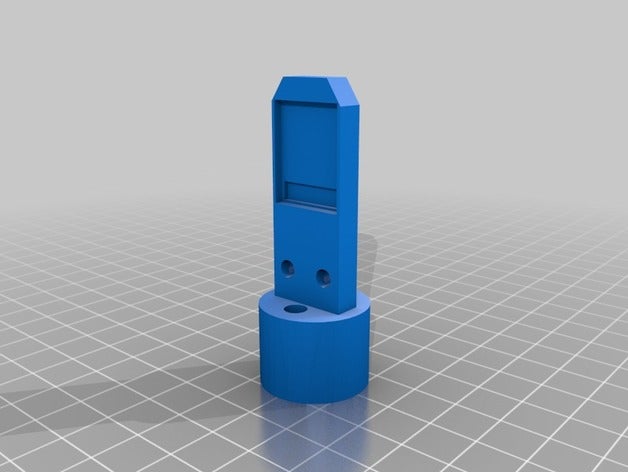
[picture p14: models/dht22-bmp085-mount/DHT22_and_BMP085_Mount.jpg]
DHT22_and_BMP085_Mount


---

## **Anemometer**

A rain-resistant, 3D-printed anemometer designed for measuring wind speed using an **A1120 Hall sensor** and two **2×2 mm neodymium magnets**.  

The perimeter of the rotating assembly is **50 cm**, meaning the anemometer completes **2 full rotations at a wind speed of 1 m/s**.

The design requires **no print supports** and uses a standard **608ZZ bearing** for smooth rotation. After installing the Hall sensor, it must be waterproofed (e.g., with epoxy resin or similar).

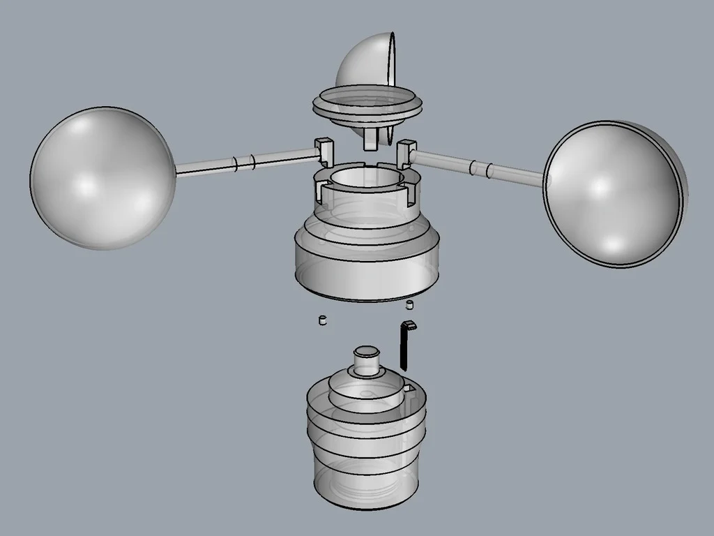
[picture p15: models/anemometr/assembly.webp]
anemometr-sep1


**Required materials:**
- 1× **608ZZ bearing**
- 2× **Neodymium magnets 2×2 mm**
- 1× **A1120 Hall sensor** (must be bent 90° as shown in the preview)
- Waterproofing compound (epoxy or similar)

#### **anemometr-sep1.stl - Upper rotating hub**

Holds the three blades and rotates around the 608ZZ bearing.  

**Quantity:** 1 pc.

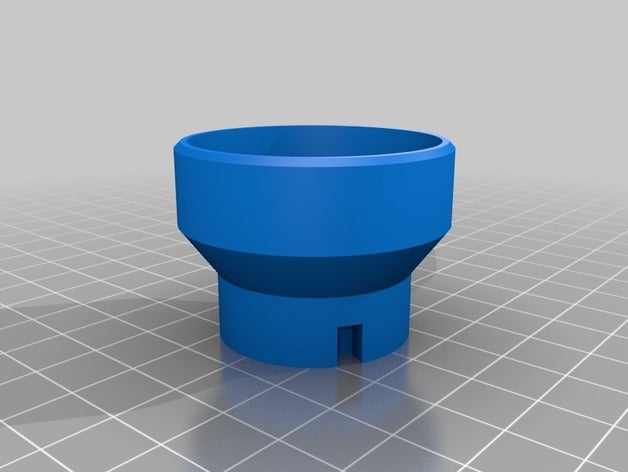
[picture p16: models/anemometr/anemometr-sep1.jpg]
anemometr-sep1


#### **anemometr-sep2.stl - Base mount**
The stationary lower part. Holds the 608ZZ bearing; the rotating hub is mounted on top of it.  

**Quantity:** 1 pc.

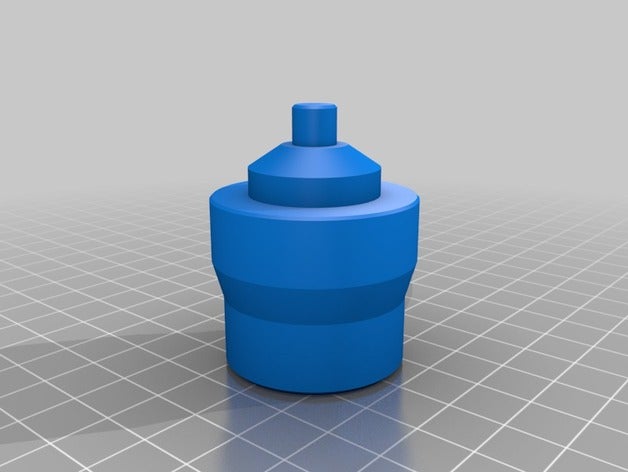
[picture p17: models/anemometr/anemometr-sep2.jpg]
anemometr-sep2


#### **anemometr-sep3.stl - Top cover**
Covers the rotating hub after the blades are inserted. Provides protection for the bearing against rain and snow.  

**Quantity:** 1 pc.

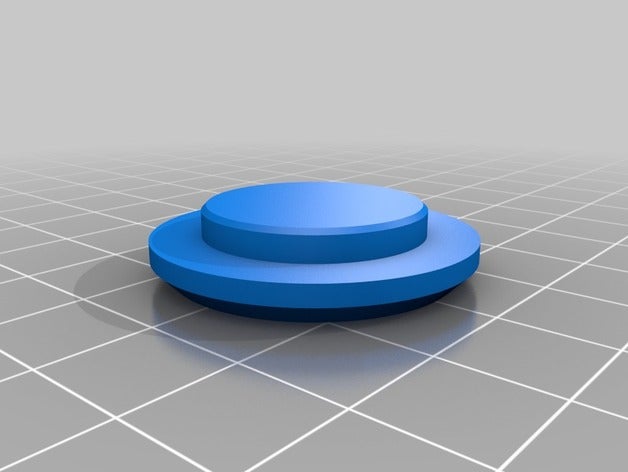
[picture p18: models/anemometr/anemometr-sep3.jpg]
anemometr-sep3


#### **anemometr-sep4.stl - Blade**

Aerodynamic blade for the spinning assembly. Three blades are required for stable and accurate rotation.  

**Quantity:** 3 pcs.

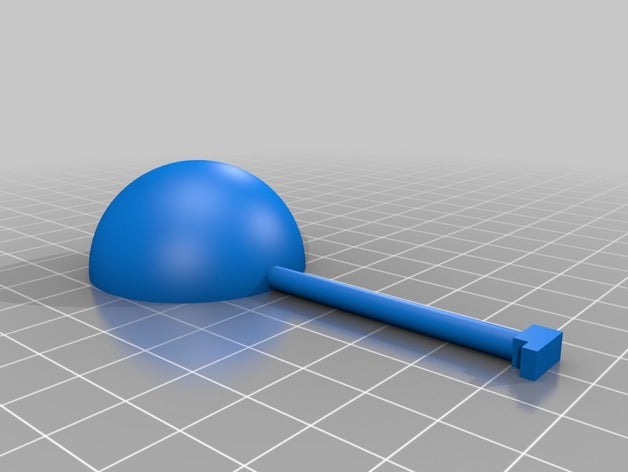
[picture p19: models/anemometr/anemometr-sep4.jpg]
anemometr-sep4


---

## Sensors Holder

A simple **sensor holder arm** used to mount both the **anemometer** and **wind direction vane** onto a vertical pole. This assembly provides a stable support structure and keeps both instruments aligned and properly spaced.

**Files to print:**
- **sensors_holder_arm_X2.stl** - 2 pcs
- **sensors_holder_center.stl** - 1 pc

**Quantity summary:** 3 printed parts total.

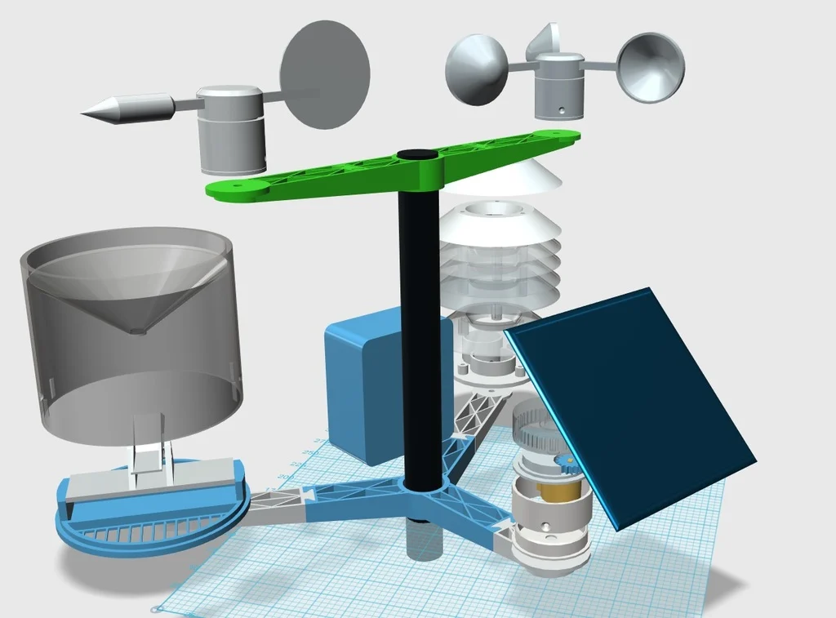
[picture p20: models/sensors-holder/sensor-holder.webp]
sensors_holder_preview


---

## Wind Direction Sensor

**Weather station wind direction sensor** - a 3D-printed wind vane capable of detecting **16 positions** using **8 magnetic sensors**. This component is part of the 3D-printed weather station project and provides accurate wind direction measurement when paired with a **PCF8574** I²C port expander.

The vane uses a **5×3 mm round magnet** mounted in the rotating part and eight Hall sensors placed around the base to detect the magnet’s position.

### Electronics Required
- **8× Hall sensors** (digital, e.g., A3144 or similar)
- **1× 5×3 mm round neodymium magnet**
- **1× PCF8574 port expander**

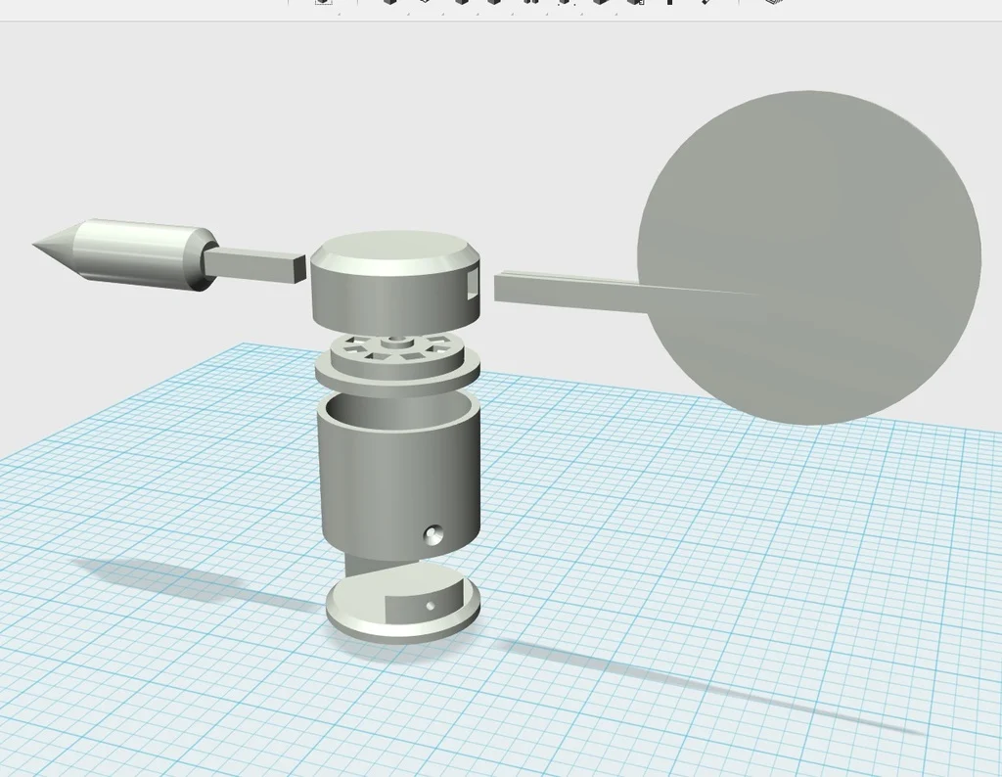
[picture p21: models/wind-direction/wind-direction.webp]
wind_direction_preview


---

# **Notes**

- All models are designed for easy printing even on low-cost printers.
- PETG provides the best balance of strength and UV resistance.
- ABS also works well - prototypes have survived **4+ years outdoors** with zero damage.
- Always print in white for thermal stability and UV protection.

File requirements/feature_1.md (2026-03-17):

# Feature 1: Weather Records & All-Time Extremes

## Overview

A dedicated **Records** page that surfaces all-time and monthly record values across every measured parameter. The station has been collecting data since 2022; this feature turns that history into a living trophy board — showing what the most extreme conditions ever recorded were, when they happened, and how close today's readings are to breaking those records.

This is a compelling "first stop" for visitors who want to understand the range and character of the local climate at a glance.

---

## Motivation

- The station accumulates years of high-resolution data that is currently accessible only through the History or Climate pages, which require the user to manually search.
- Record values (coldest night, highest wind gust, driest month, etc.) are inherently interesting and give context to current readings.
- "Records almost broken today" is a natural hook that encourages users to visit during notable weather events.

---

## Scope

### New API Endpoint

**`GET /records`**

Returns all-time and per-month records for each sensor parameter.

#### Query Parameters

| Parameter | Type | Default | Description |
|---|---|---|---|
| `period` | `all` \| `month` \| `year` | `all` | Scope of record lookup |
| `month` | integer (1–12) | current month | Used when `period=month` |
| `year` | integer | current year | Used when `period=year` |

#### Response Shape

```json
{
  "temperature": {
    "max": { "value": 41.3, "date": "2023-07-28T15:20:00Z" },
    "min": { "value": -31.7, "date": "2024-01-14T05:00:00Z" }
  },
  "pressure": {
    "max": { "value": 775, "date": "2022-12-03T09:00:00Z" },
    "min": { "value": 726, "date": "2023-03-15T18:30:00Z" }
  },
  "humidity": {
    "max": { "value": 100, "date": "2023-09-12T06:00:00Z" },
    "min": { "value": 8,   "date": "2024-06-20T14:00:00Z" }
  },
  "wind_speed": {
    "max": { "value": 22.5, "date": "2023-11-02T21:10:00Z" }
  },
  "wind_gust": {
    "max": { "value": 31.0, "date": "2023-11-02T21:10:00Z" }
  },
  "precipitation": {
    "max_daily":   { "value": 38.4, "date": "2023-05-19" },
    "max_monthly": { "value": 94.1, "month": "2023-05" }
  },
  "uv_index": {
    "max": { "value": 9, "date": "2024-07-04T12:00:00Z" }
  },
  "sol_radiation": {
    "max": { "value": 1140.2, "date": "2024-06-21T13:00:00Z" }
  },
  "dew_point": {
    "max": { "value": 24.1, "date": "2023-07-30T09:00:00Z" },
    "min": { "value": -38.0, "date": "2024-01-14T05:00:00Z" }
  }
}
```

---

## Backend Requirements

### Controller: `Records` (`server/app/Controllers/Records.php`)

- Extends `ResourceController`.
- Method `index()` — handles `GET /records`.
- Accepts and validates `period`, `month`, `year` query parameters.
- Delegates all DB work to `RecordsModel`.
- Returns JSON via `$this->respond()`.

### Model: `RecordsModel` (`server/app/Models/RecordsModel.php`)

Queries **`daily_averages`** for most parameters (fast, pre-aggregated).
For `precipitation.max_daily` use `daily_averages`; for `precipitation.max_monthly` group by month.
For temperature precision (e.g., absolute minimum) optionally fall back to `hourly_averages`.

Methods:
- `getAllTimeRecords(): array` — runs `SELECT MAX / MIN` over the entire table for each parameter.
- `getMonthlyRecords(int $month): array` — same but filtered by `MONTH(date) = ?`.
- `getYearlyRecords(int $year): array` — filtered by `YEAR(date) = ?`.

Each record row must include the `date` of occurrence via a correlated sub-query or `JOIN`.

### Route

Add to `server/app/Config/Routes.php`:

```php
$routes->get('records', 'Records::index');
```

### PHPUnit Tests (`server/tests/unit/RecordsModelTest.php`)

- Test that all-time records return the correct extreme values against fixture data.
- Test month filtering.
- Test that the response includes a `date` alongside every record value.

---

## Frontend Requirements

### New Page: `/records` (`client/pages/records.tsx`)

Layout and structure:

```
[Page Header: "Weather Records"]
[Period Selector: All Time | This Month | This Year | Custom Month]

[Grid of Record Cards — grouped by category]

Category: Temperature
  ┌─────────────────┐  ┌─────────────────┐
  │  ▲ Max ever     │  │  ▼ Min ever     │
  │  41.3 °C        │  │  −31.7 °C       │
  │  28 Jul 2023    │  │  14 Jan 2024    │
  └─────────────────┘  └─────────────────┘

Category: Wind
  ┌─────────────────┐  ┌─────────────────┐
  │  ▲ Max speed    │  │  ▲ Max gust     │
  │  22.5 m/s       │  │  31.0 m/s       │
  │  02 Nov 2023    │  │  02 Nov 2023    │
  └─────────────────┘  └─────────────────┘

... (Pressure, Humidity, Precipitation, UV, Solar)

[Footer note: "Records computed from data since January 2022"]
```

### New RTK Query Endpoint (`client/api/endpoints/Records.ts`)

```typescript
interface RecordValue {
  value: number
  date: string
}

interface Records {
  temperature: { max: RecordValue; min: RecordValue }
  pressure:    { max: RecordValue; min: RecordValue }
  humidity:    { max: RecordValue; min: RecordValue }
  windSpeed:   { max: RecordValue }
  windGust:    { max: RecordValue }
  uvIndex:     { max: RecordValue }
  solRadiation:{ max: RecordValue }
  dewPoint:    { max: RecordValue; min: RecordValue }
  precipitation: {
    maxDaily:   RecordValue
    maxMonthly: { value: number; month: string }
  }
}

// Query params
interface RecordsRequest {
  period?: 'all' | 'month' | 'year'
  month?: number
  year?: number
}
```

### New Component: `WidgetRecord` (`client/components/widget-record/`)

Props:
- `label: string` — translated label (e.g., "Maximum temperature")
- `value: number`
- `unit: string`
- `date: string`
- `type: 'max' | 'min'` — controls arrow icon color (red for max, blue for min)

Displays:
- Icon (▲ red or ▼ blue)
- Value + unit (large, bold)
- Date (small, formatted per locale)

### Navigation

Add "Records" to the main navigation menu (`client/components/app-bar/` and locale files).

---

## i18n Requirements

Add to both `client/public/locales/en/common.json` and `client/public/locales/ru/common.json`:

```json
"records": "Records",
"weather-records": "Weather Records",
"all-time-records": "All-time Records",
"records-since": "Records compiled from data since {{year}}",
"record-max-temperature": "Maximum temperature",
"record-min-temperature": "Minimum temperature",
"record-max-pressure": "Maximum pressure",
"record-min-pressure": "Minimum pressure",
"record-max-humidity": "Maximum humidity",
"record-min-humidity": "Minimum humidity",
"record-max-wind-speed": "Maximum wind speed",
"record-max-wind-gust": "Maximum wind gust",
"record-max-uv": "Maximum UV index",
"record-max-solar": "Maximum solar radiation",
"record-max-dew-point": "Maximum dew point",
"record-min-dew-point": "Minimum dew point",
"record-max-daily-precip": "Maximum daily precipitation",
"record-max-monthly-precip": "Maximum monthly precipitation",
"period-all-time": "All time",
"period-this-month": "This month",
"period-this-year": "This year",
"records-page-description": "All-time weather records for {{location}} — extremes in temperature, wind, precipitation, and more"
```

---

## Acceptance Criteria

1. The `/records` page loads and displays all-time records for all parameters.
2. Switching period to "This Month" narrows records to the current calendar month.
3. Each record card shows the value, unit, and the exact date it was recorded.
4. All strings are translated in both `en` and `ru` locales.
5. The new RTK Query endpoint is covered by at least one integration test.
6. The `RecordsModel` has PHPUnit tests for correctness of extreme-value queries.

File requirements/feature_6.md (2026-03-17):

# Feature 6: Weather Streaks & "Today in History"

## Overview

Two complementary features on a single **Statistics** page:

1. **Live Streaks Dashboard** — a set of counters showing the current run of any notable condition: consecutive days without rain, consecutive days of frost, consecutive hot days (≥30°C), consecutive windy days, etc. Each counter ticks up in real time as the station's daily data comes in.

2. **Today in History** — a sidebar panel that, for today's calendar date, shows what the weather was on this exact day in every previous year the station has been running. Users can see at a glance "was today historically dry? hot? normal?" without navigating the History page.

Together they transform raw archives into an engaging, daily-visit reason that is genuinely different every day.

---

## Motivation

- Streaks are the single most relatable weather statistic for non-meteorologists ("it's been 27 days without rain — is that a record?").
- "Today in history" is a universally engaging daily feature used by major weather services and newspapers.
- Neither feature requires any new sensor data; both are 100% computable from the existing `daily_averages` table.
- The streak counters also double as anomaly detection: a "28 days without rain" banner signals a drought even to a casual visitor.

---

## Streak Definitions

| Streak ID | Condition | Unit |
|---|---|---|
| `no_rain` | `precipitation < 0.1 mm` | consecutive days |
| `rainy` | `precipitation >= 0.1 mm` | consecutive days |
| `frost` | `temperature_min < 0°C` (approx. `temperature < 2°C` from daily avg) | consecutive days |
| `hot` | `temperature_max >= 30°C` (approx. `temperature >= 28°C`) | consecutive days |
| `windy` | `wind_speed >= 7 m/s` | consecutive days |
| `overcast` | `clouds >= 80%` | consecutive days |
| `clear` | `clouds <= 20%` | consecutive days |

Streaks are computed backward from today (or the last available data date). A streak of 0 means the condition is not currently active.

---

## Scope

### New API Endpoint

**`GET /statistics`**

Returns current streaks, streak records (all-time), and today-in-history data.

#### Query Parameters

None required. The endpoint always uses today's date as the reference point.

#### Response Shape

```json
{
  "streaks": {
    "current": {
      "no_rain":   { "days": 27, "since": "2026-02-17" },
      "rainy":     { "days": 0,  "since": null },
      "frost":     { "days": 0,  "since": null },
      "hot":       { "days": 0,  "since": null },
      "windy":     { "days": 3,  "since": "2026-03-13" },
      "overcast":  { "days": 0,  "since": null },
      "clear":     { "days": 2,  "since": "2026-03-14" }
    },
    "records": {
      "no_rain":   { "days": 41, "start": "2024-07-01", "end": "2024-08-10" },
      "rainy":     { "days": 9,  "start": "2023-09-04", "end": "2023-09-12" },
      "frost":     { "days": 68, "start": "2024-11-20", "end": "2025-01-26" },
      "hot":       { "days": 14, "start": "2023-07-15", "end": "2023-07-28" },
      "windy":     { "days": 5,  "start": "2023-11-01", "end": "2023-11-05" },
      "overcast":  { "days": 11, "start": "2022-11-10", "end": "2022-11-20" },
      "clear":     { "days": 18, "start": "2024-07-04", "end": "2024-07-21" }
    }
  },
  "todayInHistory": [
    {
      "year": 2022,
      "date": "2022-03-16",
      "temperature": 3.4,
      "precipitation": 0.0,
      "clouds": 45,
      "windSpeed": 4.2,
      "weatherId": 801
    },
    {
      "year": 2023,
      "date": "2023-03-16",
      "temperature": 7.1,
      "precipitation": 2.3,
      "clouds": 88,
      "windSpeed": 6.8,
      "weatherId": 500
    },
    {
      "year": 2024,
      "date": "2024-03-16",
      "temperature": 1.2,
      "precipitation": 0.0,
      "clouds": 12,
      "windSpeed": 2.1,
      "weatherId": 800
    }
  ],
  "todayHistoricalAvg": {
    "temperature": 3.9,
    "precipitation": 0.77,
    "clouds": 48.3,
    "windSpeed": 4.4
  }
}
```

---

## Backend Requirements

### Controller: `Statistics` (`server/app/Controllers/Statistics.php`)

- Extends `ResourceController`.
- `index()` → `GET /statistics`.
- Delegates to `StatisticsModel`.

### Model: `StatisticsModel` (`server/app/Models/StatisticsModel.php`)

All queries run against `daily_averages`.

**Current streak computation:**

```php
private function _computeCurrentStreak(string $condition): array {
    // Fetch rows ordered DESC from today
    // Walk rows while condition holds, count days
    // Return ['days' => N, 'since' => date_string | null]
}
```

Fetches only as many rows as needed (stop at first miss, max 365 rows).

**Record streak computation:**

```php
private function _computeRecordStreak(string $condition): array {
    // Fetch all rows ORDER BY date ASC
    // Walk entire history, track max run and its start/end dates
}
```

**Today in history:**

```sql
SELECT DATE(date) as day, temperature, precipitation, clouds, wind_speed, weather_id
FROM daily_averages
WHERE MONTH(date) = MONTH(NOW()) AND DAY(date) = DAY(NOW()) AND YEAR(date) < YEAR(NOW())
ORDER BY date ASC;
```

**Historical average for today's calendar date:**

```sql
SELECT AVG(temperature), AVG(precipitation), AVG(clouds), AVG(wind_speed)
FROM daily_averages
WHERE MONTH(date) = MONTH(NOW()) AND DAY(date) = DAY(NOW());
```

Methods:
- `getCurrentStreaks(): array`
- `getRecordStreaks(): array`
- `getTodayInHistory(): array`
- `getTodayHistoricalAvg(): array`

### Route

```php
$routes->get('statistics', 'Statistics::index');
```

### PHPUnit Tests (`server/tests/unit/StatisticsModelTest.php`)

- Streak of 0 when today's reading does not meet the condition.
- Streak count across month boundary (e.g., 27 days spanning Feb–Mar).
- Record streak finds the correct historical maximum.
- Today-in-history returns only past years, not the current year.

---

## Frontend Requirements

### New Page: `/statistics` (`client/pages/statistics.tsx`)

Layout:

```
[Page Header: "Weather Statistics"]

[Section: Current Streaks]

  Active streaks (days > 0):
  ┌─────────────────────────────────────────────────────┐
  │  ☀️ 27 days without rain · since 17 Feb 2026        │
  │     All-time record: 41 days (Jul–Aug 2024)         │
  ├─────────────────────────────────────────────────────┤
  │  💨 3 consecutive windy days · since 13 Mar 2026    │
  │     All-time record: 5 days (Nov 2023)              │
  └─────────────────────────────────────────────────────┘

  Inactive (all other streak types shown as grey/dormant):
  ┌──────────────────┐  ┌──────────────────┐  ┌──────────────────┐
  │ 🌧 Rainy         │  │ 🌡 Frost         │  │ 🔥 Hot days      │
  │ 0 days           │  │ 0 days           │  │ 0 days           │
  │ Record: 9 days   │  │ Record: 68 days  │  │ Record: 14 days  │
  └──────────────────┘  └──────────────────┘  └──────────────────┘

[Section: Today in History — March 16]

  ┌────────────┬────────────┬────────────┐
  │ 2022       │ 2023       │ 2024       │
  │ +3.4 °C   │ +7.1 °C   │ +1.2 °C   │
  │ 0 mm rain  │ 2.3 mm    │ 0 mm rain  │
  │ ⛅ 45%    │ 🌧 88%    │ ☀️ 12%    │
  │ 4.2 m/s   │ 6.8 m/s   │ 2.1 m/s   │
  └────────────┴────────────┴────────────┘

  Historical average for March 16: +3.9 °C · 0.77 mm · 48% clouds
```

### New Component: `WidgetStreak` (`client/components/widget-streak/`)

Props:
- `streakId: string` — used to look up label and icon
- `current: { days: number; since: string | null }`
- `record: { days: number; start: string; end: string }`
- `active: boolean`

Displays:
- Emoji/icon for the streak type
- Current counter (large, bold if `active`)
- "Since" date when active
- Record days in a smaller, subdued style
- Inactive state: greyed out with record shown

### New Component: `WidgetTodayInHistory` (`client/components/widget-today-in-history/`)

- Card grid — one card per historical year.
- Each card: temperature (large), precipitation, clouds (with WeatherIcon), wind speed.
- Footer row: "Historical average for this day".

### New RTK Query Endpoint (`client/api/endpoints/Statistics.ts`)

```typescript
interface StreakEntry {
  days: number
  since: string | null
}

interface RecordEntry {
  days: number
  start: string
  end: string
}

interface HistoryDayEntry {
  year: number
  date: string
  temperature: number
  precipitation: number
  clouds: number
  windSpeed: number
  weatherId: number
}

interface StatisticsResponse {
  streaks: {
    current: Record<string, StreakEntry>
    records: Record<string, RecordEntry>
  }
  todayInHistory: HistoryDayEntry[]
  todayHistoricalAvg: {
    temperature: number
    precipitation: number
    clouds: number
    windSpeed: number
  }
}
```

Polling interval: `600_000` ms (10 minutes — daily data changes infrequently).

### Navigation

Add "Statistics" to the main navigation menu.

---

## i18n Requirements

```json
"statistics": "Statistics",
"weather-statistics": "Weather Statistics",
"current-streaks": "Current Streaks",
"streak-no-rain": "Days without rain",
"streak-rainy": "Consecutive rainy days",
"streak-frost": "Consecutive frost days",
"streak-hot": "Consecutive hot days",
"streak-windy": "Consecutive windy days",
"streak-overcast": "Consecutive overcast days",
"streak-clear": "Consecutive clear days",
"streak-since": "Since {{date}}",
"streak-record": "Record: {{days}} days",
"streak-record-period": "Record: {{days}} days ({{start}} – {{end}})",
"no-active-streak": "Not active",
"today-in-history": "Today in History",
"today-in-history-date": "{{month}} {{day}} in previous years",
"historical-average": "Historical average for this day",
"statistics-page-description": "Weather streaks and historical comparison for {{location}} — current dry/wet/frost runs and past years on this date"
```

---

## Acceptance Criteria

1. Active streaks (days > 0) are visually prominent; inactive ones are subdued.
2. Each streak correctly reflects the current calendar day's data.
3. Record streaks are computed from all available years of history.
4. "Today in history" shows one card per available past year.
5. The historical average reflects only past years (not the current year).
6. PHPUnit tests cover streak boundary conditions (month crossings, year crossings).
7. Both `en` and `ru` translations present.
8. The page polls every 10 minutes.

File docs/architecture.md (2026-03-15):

# Architecture

## High-Level System Overview

```
┌─────────────────────────────────────────────────────────────────┐
│                        ARDUINO HARDWARE                         │
│  BMP085 · BH1750 · DHT22 · PCF8574 · GY-ML8511 · Anemometer   │
└──────────────────────────────┬──────────────────────────────────┘
                               │  HTTP POST /sensors (every 60 s)
                               ▼
┌─────────────────────────────────────────────────────────────────┐
│                      PHP / CODEIGNITER API                      │
│  server/  ·  PHP 8.2  ·  CodeIgniter 4.6  ·  MySQL             │
│                                                                 │
│  ┌──────────────┐  ┌──────────────┐  ┌──────────────────────┐  │
│  │  Controllers │  │    Models    │  │      Libraries       │  │
│  │  Current     │  │  RawWeather  │  │  OpenWeatherMap      │  │
│  │  Forecast    │  │  Forecast    │  │  WeatherAPI          │  │
│  │  History     │  │  Hourly      │  │  VisualCrossing      │  │
│  │  Heatmap     │  │  Daily       │  │  NarodMon (push)     │  │
│  │  Sensors     │  └──────────────┘  └──────────────────────┘  │
│  │  System      │                                               │
│  └──────────────┘                                               │
└────────┬────────────────────────────────────┬───────────────────┘
         │  REST JSON                         │  CLI cron jobs
         ▼                                    ▼
┌──────────────────────┐         ┌────────────────────────────────┐
│   NEXT.JS DASHBOARD  │         │       EXTERNAL SERVICES        │
│  client/             │         │  OpenWeatherMap  (forecast)    │
│  Next.js 16 · React  │         │  WeatherAPI.com  (forecast)    │
│  RTK Query · ECharts │         │  VisualCrossing  (forecast)    │
│  i18next (ru / en)   │         │  NarodMon        (data push)   │
└──────────────────────┘         └────────────────────────────────┘
```

## Three-Layer Architecture

### Layer 1 — Firmware (arduino/)

The Arduino firmware (C++) runs on an Arduino or ESP32 microcontroller. It reads sensor values every 60 seconds and sends a single HTTP POST request to `POST /sensors` on the backend API. Authentication uses a shared secret token (`API_SECRET`) configured in both the sketch and the server environment.

Sensors managed by the firmware:

| Sensor | Interface | Measurement |
|---|---|---|
| BMP085 | I2C | Atmospheric pressure |
| BH1750 | I2C | Ambient light / solar energy  |
| PCF8574 | I2C expander | Wind vane (direction) |
| DHT22 | Digital pin 4 | Temperature, humidity |
| Anemometer | Interrupt pin 3 | Wind speed |
| GY-ML8511  | Analog A0 / A1 | UV intensity |

### Layer 2 — Backend API (server/)

The PHP/CodeIgniter application exposes a REST API consumed by the frontend and receives POST data from the Arduino. It also runs scheduled CLI commands (via `php spark`) to pull forecast data from third-party weather services and push local readings to NarodMon.

Raw measurements are stored in `raw_weather_data`. Background cron jobs aggregate data into `hourly_averages` and `daily_averages`, and populate `forecast_weather_data` from external APIs.

### Layer 3 — Frontend Dashboard (client/)

A Next.js 16 application (Pages Router) fetches all data through RTK Query endpoints backed by the backend API. It presents real-time readings, historical charts (ECharts), a heatmap, and a multi-day forecast. The UI supports Russian and English (next-i18next) with light and dark themes (next-themes).

## Data Flow

```
Arduino sensors
    │
    │  POST /sensors  (every 60 s, bearer token auth)
    ▼
raw_weather_data table
    │
    ├─► hourly_averages  (aggregated by System controller / cron)
    └─► daily_averages   (aggregated by System controller / cron)

External APIs (OpenWeatherMap, WeatherAPI.com, VisualCrossing)
    │
    │  php spark system:forecast  (scheduled cron)
    ▼
forecast_weather_data table

NarodMon
    ▲
    │  php spark system:narodmon  (scheduled cron, outbound push)
    │
raw_weather_data table

Frontend (RTK Query)
    │  GET /current, /forecast/daily, /forecast/hourly,
    │      /history, /heatmap, /current/text
    ▼
ECharts visualisations, summary cards, forecast table
```

## External Services

| Service | Direction | Purpose |
|---|---|---|
| OpenWeatherMap | Inbound | Fetches forecast data on a schedule via `system:forecast`  |
| WeatherAPI.com | Inbound | Alternative forecast source, same cron command |
| VisualCrossing | Inbound | Additional forecast provider, same cron command |
| NarodMon | Outbound  | Receives local sensor readings pushed via `system:narodmon`|

Credentials and API keys for all four services are stored in the server `.env` file and accessed through CodeIgniter's environment-variable helpers.

## Database Tables

| Table | Purpose |
|---|---|
| `raw_weather_data` | Every individual reading posted by the Arduino (60-second cadence) |
| `hourly_averages` | Pre-aggregated averages per clock hour, computed from raw data  |
| `daily_averages` | Pre-aggregated averages per calendar day, computed from raw data|
| `forecast_weather_data`| Forecast records fetched from external APIs |

Migrations live in `server/app/Database/Migrations/`. Existing migration files must never be modified; new schema changes always go into new migration files.

## CI/CD Pipelines

All pipelines are defined in `.github/workflows/`.

| Workflow file | Trigger | What it does |
|---|---|---|
| `ui-checks.yml` | PR to main | Runs ESLint, Prettier, Jest, and `next build` on the client |
| `ui-deploy.yml` | Push to main | Builds the Next.js app and deploys via FTP to production |
| `api-deploy.yml` | Push to main | Deploys the PHP server files via FTP to production |
| `sonarcloud.yml` | Push / PR | Uploads LCOV coverage to SonarCloud quality gate |
| `arduino-code-check.yml`| Push / PR | Compiles the Arduino sketch to verify it builds without errors  |

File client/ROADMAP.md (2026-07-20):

# Frontend Roadmap — Arduino Weather Station Client

Generated: 2026-03-14
Updated: 2026-04-05
Scope: `/client` directory (Next.js 16, React 19, TypeScript 5.9, RTK Query, ECharts, i18next)

---

## Legend

| Priority | Meaning |
| --- | --- |
| **High** | Bug or convention violation that affects correctness, SEO, or user experience now |
| **Medium** | Quality issue, missing coverage, or UX gap with clear value |
| **Low** | Nice-to-have improvement or cleanup with low urgency |

---

## 1. Code Quality

### QC-03 · `showOverlay` state in Redux slice is never dispatched [Medium]

**File:** `api/applicationSlice.ts` — the `showOverlay?: boolean` field exists in `ApplicationStateProps` but there is no `setShowOverlay` action and nothing dispatches it. Either add the missing action or remove the dead field.

---

### QC-11 · `encodeQueryData` uses `for...in` loop which iterates inherited properties [Low]

**File:** `tools/helpers.ts` — lines 15–19

```ts
for (const key in data) {
```

`for...in` iterates all enumerable properties, including prototype-inherited ones. For plain objects this is safe, but it is an anti-pattern. Replace with `Object.keys(data)` or `Object.entries(data)`.

---

### QC-13 · Switch `case` order in `colors.ts` — `undefined` case appears after `default` [Medium]

**File:** `tools/colors.ts` — lines 68–72

```ts
default:
    return 'grey'
case undefined: {
    throw new Error('Not implemented yet: undefined case')
}
```

The `undefined` case is unreachable because `default` matches first. Either move `case undefined` above `default`, or handle it with a runtime guard before the switch.

---

## 2. Performance

### PERF-03 · `currentDate` and `yesterdayDate` are module-level constants evaluated once at import time [Medium]

**File:** `tools/date.ts` — lines 10–12

```ts
export const currentDate = dayjs().utc(false).tz(TIME_ZONE)
export const yesterdayDate = currentDate.subtract(1, 'day').toDate()
```

These are computed when the module is first imported and never update. On long-running sessions or after midnight, the dates become stale. Query args using these values do not change, so no re-fetch occurs after midnight.

Fix: convert to functions (`getCurrentDate()`, `getYesterdayDate()`) and call them at query-arg computation time, or store a derived value that includes the current date in component state so it refreshes.

---

### PERF-06 · No RTK Query `keepUnusedDataFor` tuning [Low]

**File:** `api/api.ts`

The default RTK Query `keepUnusedDataFor` is 60 seconds. For a weather station where data changes every 10 minutes, cached data can be served stale for longer. Consider setting `keepUnusedDataFor: 600` (10 minutes) on the endpoints to match the polling interval and avoid unnecessary refetches when navigating between pages.

---

## 3. Testing

### TEST-05 · `encodeQueryData` edge case: falsy non-null values (`0`, `false`) [Low]

**File:** `tools/helpers.test.ts`

The current test suite does not cover numeric `0` or boolean `false` values. Both are valid query parameters and are currently included (correctly) — however there is no regression test to guard against accidentally changing the check to a truthiness test. Add tests like:

```ts
it('includes numeric 0 as valid value', () => {
    expect(encodeQueryData({ count: 0 })).toBe('?count=0')
})

it('includes boolean false as valid value', () => {
    expect(encodeQueryData({ active: false })).toBe('?active=false')
})
```

---

## 4. Features / Enhancements

### FEAT-02 · History page has no chart for humidity, wind, or UV index [Low]

**File:** `pages/history.tsx`

Only `temperature`, `clouds`, and `pressure` charts are shown. The `WidgetChart` component supports only these three types (`ChartTypes = 'temperature' | 'clouds' | 'pressure'`). Extending `ChartTypes` and adding chart configs for `humidity` and `windSpeed` would make the history page more useful.

---

### FEAT-03 · No error state handling for any RTK Query endpoint [High]

**Files:** All pages using `API.useGetCurrentQuery`, `useGetHistoryQuery`, `useGetForecastQuery`, `useGetHeatmapQuery`

None of the pages or widgets check `isError` from RTK Query. If the API is unreachable, the component silently shows the loading skeleton forever. Add an error UI (e.g. a banner or empty state with retry) for at least the main page and history page.

---

### FEAT-06 · `heatmap.tsx` `isMobile` uses synchronous `window.innerWidth` without resize listener [Medium]

**File:** `components/widget-heatmap/Heatmap.tsx` — line 33

```ts
const isMobile = isClient && !!(window?.innerWidth && window?.innerWidth < 500)
```

`isMobile` is computed once when `isClient` becomes `true` and never updates on window resize. The heatmap title visibility (`show: !isMobile`) therefore becomes stale after orientation changes. Add a resize listener or use a CSS media query approach.

---

## 5. Security

> All items below were identified during a security audit. Severity levels: **CRITICAL** · **HIGH** · **MEDIUM** · **LOW**

---

### SEC-01 · Missing HTTP security headers — no CSP, X-Frame-Options, HSTS, or X-Content-Type-Options [HIGH]

**File:** `next.config.js`

The `next.config.js` exports no `headers()` function, so every page is served without any protective HTTP headers:

- **Content-Security-Policy** — no restriction on which scripts, styles, or frames may load.
- **X-Frame-Options / CSP `frame-ancestors`** — the application can be embedded in a third-party `<iframe>`, enabling clickjacking attacks.
- **X-Content-Type-Options: nosniff** — browsers may sniff response MIME types.
- **Strict-Transport-Security** — no HSTS; downgrade attacks are possible.
- **Referrer-Policy** — referrer data leaks to third-party domains.
- **Permissions-Policy** — no restrictions on camera, microphone, or geolocation access.

Add a `headers()` export to `next.config.js` setting at minimum `X-Frame-Options: SAMEORIGIN`, `X-Content-Type-Options: nosniff`, `Referrer-Policy: strict-origin-when-cross-origin`, and a restrictive `Content-Security-Policy`.

---

### SEC-03 · ECharts tooltip formatters render unescaped API data as raw HTML [MEDIUM]

**Files:** `components/widget-chart/Chart.tsx`, `components/widget-heatmap/Heatmap.tsx`, `components/widget-meteogram/Meteogram.tsx`, `components/widget-precip-chart/WidgetPrecipChart.tsx`, `components/widget-climate/Chart.tsx`

All chart tooltip formatters build HTML strings by concatenating values received directly from the API, then pass the resulting string to ECharts which renders it as `innerHTML` without escaping. If the backend were to return a malicious string, it would execute as JavaScript.

Sanitize or numeric-coerce all values before inserting them into formatter strings (e.g., `Number(value).toFixed(1)` for numeric fields).

---

### SEC-05 · `NEXT_LOCALE` cookie set without `Secure` or `SameSite` flags [LOW]

**File:** `components/language-switcher/LanguageSwitcher.tsx`, line 31

```ts
void setCookie('NEXT_LOCALE', locale)
```

The `setCookie` call passes no options, so the cookie is written without `Secure`, without `SameSite`, and without `HttpOnly`. Pass `{ secure: true, sameSite: 'lax' }` to all `setCookie` calls.

---

### SEC-06 · Application version number exposed in the footer [LOW]

**File:** `components/footer/Footer.tsx`, lines 31–32

The exact `package.json` version string is rendered on every page. This gives any visitor instant visibility into the precise software version. Consider removing the version from the rendered HTML or showing it only in dev mode.

---

### SEC-07 · `ecosystem.config.js` exposes production hostname and internal service port [LOW]

**File:** `client/ecosystem.config.js`

The PM2 deployment config commits the production service name (`meteo.miksoft.pro`) and internal port (`3007`) to the repository. Move deployment-specific config out of the repository or into a secrets-management system.

---

### SEC-08 · `sessionStorage` and `localStorage` data deserialised without runtime schema validation [LOW]

**Files:** `pages/climate.tsx`, `hooks/useLocalStorage.ts`

Both files parse JSON from browser storage and immediately cast the result to a typed interface with no runtime field validation. Add a lightweight runtime validator (e.g., a shape-check function) before casting.

---

## 6. Summary by Priority

### High (fix first)

| ID | Summary |
| --- | --- |
| SEC-01  | Missing HTTP security headers (CSP, X-Frame-Options, HSTS) |
| FEAT-03 | No error state handling for any RTK Query endpoint |

### Medium (address in regular sprints)

| ID | Summary |
| --- | --- |
| SEC-03  | ECharts tooltip renders unescaped API data as HTML |
| QC-03 | `showOverlay` redux field is never dispatched |
| QC-13 | `undefined` case after `default` in switch is unreachable |
| PERF-03 | `currentDate` / `yesterdayDate` never refresh |
| FEAT-06 | Heatmap `isMobile` stale after window resize |

### Low (backlog)

| ID | Summary |
| --- | --- |
| SEC-05  | `NEXT_LOCALE` cookie missing `Secure`/`SameSite` |
| SEC-06  | App version number exposed in footer |
| SEC-07  | `ecosystem.config.js` exposes production port |
| SEC-08  | Storage deserialisation without schema validation |
| QC-11 | `for...in` in `encodeQueryData` — use `Object.keys` |
| PERF-06 | No `keepUnusedDataFor` tuning on RTK Query |
| TEST-05 | `encodeQueryData` missing falsy-value edge case |
| FEAT-02 | History page missing humidity / wind charts |

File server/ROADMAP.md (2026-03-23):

# Backend Roadmap — Arduino Weather Station Server

Generated: 2026-03-22
Scope: `/server` directory (PHP 8.2+, CodeIgniter 4.6, MySQL)

---

## Legend

| Priority | Meaning |
| --- | --- |
| **Critical** | Active exploit risk; requires immediate remediation |
| **High** | Significant security weakness; address in the next sprint |
| **Medium** | Defence-in-depth gap; address in regular sprints |
| **Low** | Hardening improvement or low-probability risk; backlog |

---

## 1. Security

> All items below were identified during a security audit on 2026-03-22.

### SEC-03 · Wildcard CORS — `Access-Control-Allow-Origin: *` on all endpoints [HIGH]

**File:** `server/app/Filters/CorsFilter.php`, line 24

```php
header("Access-Control-Allow-Origin: *");
```

The CORS filter is registered as a global `before` filter and allows any origin to issue cross-origin requests with any HTTP method (`GET, POST, OPTIONS, PATCH, PUT, DELETE`). Any malicious web page visited by a user can silently call `POST /sensors` or `GET /history/export` using the user's browser. It also nullifies any future cookie-based or token-based access control at the browser layer.

Restrict `Access-Control-Allow-Origin` to the known frontend origin(s) (e.g., `https://meteo.miksoft.pro`). Use an allowlist for multiple origins if needed.

---

### SEC-05 · Arduino authentication token transmitted as a URL query string parameter [HIGH]

**File:** `server/app/Controllers/Sensors.php`, line 39

```php
$token = $this->request->getGet('token', FILTER_SANITIZE_SPECIAL_CHARS);
```

The token is passed as `?token=TOKEN` in the URL. Query strings are written to web server access logs, reverse-proxy logs, CDN logs, and browser history. Any party with access to any of these log sources can silently extract the token without any indication of compromise.

Move the token to an HTTP header (e.g., `Authorization: Bearer <token>`) and update the Arduino firmware to send it as a request header instead of a query parameter.

---

### SEC-13 · HTTPS not enforced at the application level [MEDIUM]

**File:** `server/app/Config/App.php`, line 136

```php
public bool $forceGlobalSecureRequests = false;
```

The application does not enforce HTTPS internally. If a reverse proxy misconfiguration causes HTTP requests to reach the application, the Arduino token (SEC-05) and sensor payloads are transmitted in cleartext. Enforcement should be layered: both at the reverse proxy and at the application level.

Set `$forceGlobalSecureRequests = true` in production.

---

### SEC-18 · Physical station GPS coordinates committed to a public repository [LOW]

**File:** `server/.env.production`

```
app.lat = 51.70952
app.lon = 55.26690
```

The exact GPS coordinates of the physical hardware are committed to the public repository. While publicly exposing a weather station's location may be intentional, it should be a documented decision, not an accidental disclosure via a committed secrets file. Remove from `.env.production` (see SEC-01) and store in the runtime environment instead.

---

### SEC-19 · `CorsFilter` uses `die()` for OPTIONS preflight, bypassing the response pipeline [LOW]

**File:** `server/app/Filters/CorsFilter.php`, lines 28–31

```php
if ($method === "OPTIONS") {
    die();
}
```

Using `die()` exits PHP immediately, bypassing all CodeIgniter `after` filters. Any future after-filters (security headers, audit logging) will never execute for OPTIONS preflight requests. Additionally, `$_SERVER['REQUEST_METHOD']` is accessed directly instead of `$request->getMethod()`, bypassing framework abstraction.

Replace with a proper `$response->setStatusCode(204)->send(); exit;` pattern, or return a response object from the filter method and let the framework terminate the request cleanly.

---

### SEC-20 · No sensitive data redaction in debug traces [LOW]

**File:** `server/app/Config/Exceptions.php`, line 52

No keys are registered for redaction in debug stack traces. If an API key, database password, or Arduino token is passed as a function argument and an exception is thrown during that call, the value appears in the trace output. Register all sensitive key names (e.g., `password`, `token`, `api_key`, `key`, `mac`) in `$sensitiveDataInTrace`.

---

### SEC-21 · Log files use `.log` extension without a PHP guard [LOW]

**File:** `server/app/Config/Logger.php`, line 104

```php
'fileExtension' => '',
```

The `fileExtension` defaults to `.log`. The CodeIgniter documentation notes that using a `.php` extension allows protecting log files via a PHP guard when stored under a publicly accessible directory. If `writable/logs/` were ever accidentally served by the web server, `.log` files would be delivered as plain text, potentially exposing application internals. Keep `writable/logs/` outside the web root and consider setting `'fileExtension' => 'php'` as an additional safeguard.

---

## 2. Summary by Severity

### High

| ID | Summary | File |
| --- | --- | ---- |
| SEC-03 | Wildcard CORS `*` allows any origin to call all endpoints  | `Filters/CorsFilter.php:24` |
| SEC-05 | Arduino token sent as a URL query parameter (logged) | `Controllers/Sensors.php:39` |

### Medium

| ID | Summary | File |
| --- | --- | ---- |
| SEC-13 | HTTPS not enforced at application level | `Config/App.php:136` |

### Low

| ID | Summary | File |
| --- | --- | ---- |
| SEC-18 | Physical GPS coordinates in a public repository | `server/.env.production` |
| SEC-19 | `die()` in CorsFilter bypasses the response pipeline | `Filters/CorsFilter.php:30` |
| SEC-20 | No sensitive data redaction in debug stack traces | `Config/Exceptions.php:52` |
| SEC-21 | Log files use `.log` extension without PHP guard | `Config/Logger.php:104` |

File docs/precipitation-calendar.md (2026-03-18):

# Precipitation Calendar

## Overview

The **Precipitation Calendar** (`/precipitation`) is a full-year rainfall visualisation page. It displays daily precipitation totals in a compact GitHub-style contribution grid — one cell per day, coloured by rainfall intensity — so you can see seasonal patterns, dry spells, and wet periods at a glance across any recorded year.

The page also surfaces three key statistics and a monthly bar chart, giving a complete picture of the year's precipitation without any need to hunt through raw data tables.

---

## Navigating the Page

### Year Selector

At the top of the page, a row of buttons shows every year for which the station has data. Click any year to reload the calendar and all statistics for that year. The current year is selected by default.

### Calendar Grid

```
      1  2  3  4  5  6  7  8 … 31
Jan  [■][■][□][□][░][■][■][□]…
Feb  [□][□][□][□][□][□][░][□]…
…
Dec  [■][▒][▒][□][□][□][□][□]…
```

- **Rows** — one per month (January at the top, December at the bottom).
- **Columns** — one per calendar day (1–31). Days that don't exist in a given month (e.g. 30 and 31 in February) are shown as empty placeholders.
- **Day-of-month numbers** are displayed as column headers on desktop; they are hidden on mobile to save space.

#### Cell Colour Scale

| Colour | Meaning |
|---|---|
| Grey (neutral) | No data recorded for this day |
| Lightest blue | Trace — more than 0 mm and up to 1 mm |
| Light blue | Light rain — more than 1 mm and up to 5 mm |
| Medium blue | Moderate rain — more than 5 mm and up to 20 mm |
| Dark blue | Heavy rain — more than 20 mm |

A **legend** below the grid labels each colour level.

#### Tooltip

Hover over any cell to see the exact date and the daily total in millimetres.

---

## Statistics Cards

Three summary cards appear below the calendar.

| Card | What it shows |
|---|---|
| **Total precipitation** | Accumulated rainfall for the selected year in mm |
| **Rainy days** | Number of days with more than 0.1 mm of rain, plus the percentage of the year |
| **Longest dry stretch** | The longest unbroken sequence of days with no measurable rain — shown with the start and end dates |

> **Note:** A "rainy day" is defined as any day with a recorded total **greater than 0.1 mm**. Days with trace amounts of 0.1 mm or less count as dry for reporting purposes but do break the dry streak (see below).

---

## Monthly Totals Chart

A vertical bar chart at the bottom of the page shows precipitation totals for each of the 12 calendar months. Month labels automatically follow the active display language (English or Russian). Hovering a bar shows the month name and the total in mm.

---

## How Streaks Are Calculated

Both the wet streak and the dry streak scan every calendar day of the selected year — including days with no station data, which are treated as 0 mm.

- **Wet streak** — the longest consecutive run of days where the daily total is **greater than 0 mm** (any measurable precipitation).
- **Dry streak** — the longest consecutive run of days where the daily total is **exactly 0 mm**. Even a trace of 0.1 mm resets the dry streak counter.

Streaks cross month boundaries naturally. The station reports only the longest streak found; shorter streaks during the year are not listed separately.

> For the current year, only days up to and including today are considered — future dates are not counted as dry days.

---

## Interpreting the Data

**Seasonal patterns are immediately visible.** In the Orenburg region, winters typically show sparse blue cells (frozen precipitation is not always captured by the rain gauge), spring brings a cluster of moderate rainfall, and summer is characterised by alternating wet and dry periods.

**Long dry stretches in summer** (July–August) are normal for the continental climate of the southern Urals and typically span 3–5 weeks. Stretches exceeding 40 days are historically unusual and may indicate drought conditions.

**Heavy rainfall events** (dark blue cells, > 20 mm) are most common in May–June when convective thunderstorms are most frequent.

---

## Frequently Asked Questions

**Why does the total precipitation differ from official meteorological reports?**

The station's rain gauge measures precipitation at the installation point only, while official totals are station-averaged over a wider area. Micro-topographic effects, wind, and evaporation from the gauge funnel can all introduce differences of 10–20 % compared with regional averages.

**Why are some winter days shown as grey (no data)?**

Snow and ice can block the rain gauge funnel. The station records 0 mm during blockage periods, which are omitted from the grid to distinguish "no data" from "confirmed dry day." Snow water equivalent is tracked separately on the [Anomaly Monitor](./anomaly-monitor.md) page using a temperature-index model.

**Why does the calendar show fewer rainy days than I remember?**

Only days with a recorded total **above 0.1 mm** count as rainy. Very light drizzle or dew condensation may register below this threshold.

---

---

## Developer Reference

### API Endpoint

**`GET /precipitation`**

| Parameter | Type | Default | Constraint |
|---|---|---|---|
| `year` | integer | current year | 2020 – current year |

#### Response shape

```json
{
  "year": 2025,
  "days": [
    { "date": "2025-01-01", "total": 0.0 },
    { "date": "2025-01-14", "total": 3.2 }
  ],
  "stats": {
    "totalYear": 312.4,
    "rainyDays": 74,
    "dryDays": 291,
    "maxDailyTotal": { "value": 22.1, "date": "2025-05-18" },
    "longestWetStreak":  { "days": 7,  "start": "2025-04-03", "end": "2025-04-09" },
    "longestDryStreak":  { "days": 38, "start": "2025-07-04", "end": "2025-08-10" },
    "monthlyTotals": [
      { "month": 1, "total": 14.2 },
      { "month": 2, "total": 8.7 }
    ]
  },
  "availableYears": [2022, 2023, 2024, 2025]
}
```

`days` contains **only days with recorded precipitation** (`total > 0`). Days absent from the array had no measurable rain. The frontend fills in the full calendar grid by treating absent dates as 0 mm.

`stats` is computed entirely in PHP from the `days` array — no extra database queries are made.

### Precipitation Aggregation

Daily totals are computed from `raw_weather_data` using a two-level query to avoid inflating values when multiple external API sources report data for the same time period:

```sql
-- Step 1: average all source readings within each calendar hour
SELECT DATE(date) AS day,
       DATE_FORMAT(date, '%Y-%m-%d %H:00:00') AS hour_slot,
       AVG(precipitation) AS hour_avg
FROM raw_weather_data
WHERE YEAR(date) = ?
  AND precipitation IS NOT NULL AND precipitation > 0
GROUP BY day, hour_slot

-- Step 2: sum hourly averages to get the daily total
SELECT day, ROUND(SUM(hour_avg), 1) AS total
FROM ( … ) AS hourly
GROUP BY day ORDER BY day
```

The inner `AVG` collapses multiple sources (OpenWeatherMap, WeatherAPI, VisualCrossing, CustomStation) that each report the same physical rain event. The outer `SUM` then accumulates those hourly values into a correct daily total.

### Streak Algorithm

`PrecipitationModel::getStats()` expands the sparse `days` array into a **complete calendar** (every day from `{year}-01-01` to `min({year}-12-31, today)`) before running streak detection. Missing days are inserted with `total = 0.0`. This ensures that long dry periods with no recorded measurements are counted correctly.

`_computeStreaks()` then performs a single linear pass over the sorted calendar:
- **Wet threshold:** `total > 0.0` — any measurable precipitation.
- **Dry threshold:** `total === 0.0` — trace amounts (≤ 0.1 mm) also count as wet for streak purposes, so they break a dry streak.
- The `rainyDays` / `dryDays` counters in `getStats()` use the stricter `> 0.1 mm` threshold, matching the user-facing definition of a "rainy day."

### Frontend Components

| Component | Path | Purpose |
|---|---|---|
| `WidgetPrecipCalendar` | `client/components/widget-precip-calendar/` | 12 × 31 CSS Grid calendar with colour-coded cells and hover tooltip |
| `WidgetPrecipChart` | `client/components/widget-precip-chart/` | ECharts bar chart for 12 monthly totals; reads locale from `i18n.language` |
| `WidgetPrecipStatCard` | `client/components/widget-precip-stat-card/` | Generic stat display card (title + value + optional sub-label) |
| `WidgetStreakCard` | `client/components/widget-streak-card/` | Wet or dry streak card with icon, day count, and date range |

The page (`client/pages/precipitation.tsx`) fetches data via RTK Query (`API.useGetPrecipitationQuery({ year })`). All widgets receive a `loading` prop and render a `Skeleton` placeholder while the request is in flight, so the page layout never collapses during navigation.

Month labels in both the calendar grid and the bar chart are generated at runtime using `toLocaleString(i18n.language, { month: 'short' })`, so they automatically switch between English and Russian without any i18n key lookups.

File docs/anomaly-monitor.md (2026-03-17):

# Meteorological Anomaly Monitor

## Overview

The **Anomaly Monitor** (`/anomaly`) is a dedicated page that analyses historical weather data collected by the station and flags statistically unusual conditions in real time. It was designed in response to the April 2024 Ural River flood — the most severe on record in the Orenburg region — whose meteorological preconditions (exceptional snowpack, rapid spring warming, rain-on-snow events, frozen ground) were fully observable from the station's own sensor data weeks in advance.

The page provides four sections:

| Section | Purpose |
|---|---|
| Spring Flood Risk | Composite flood-risk score with snowpack chart and season comparison |
| Parameter Anomaly Dashboard | Z-score cards for all six key parameters |
| Active Anomalies | Live status of all 12 monitored anomaly types |
| Anomaly History | 12-month calendar heatmap and tabular log |

> **Important disclaimer:** This feature is a meteorological anomaly indicator, not a flood forecast. Reservoir and dam operations are not modelled and can account for a significant portion of actual flood magnitude.

The page polls the API every **5 minutes**.

---

## Detection Methods

### Z-Score (Statistical Anomaly Detection)

The primary method used for temperature, pressure, wind, humidity, UV index, and precipitation anomalies.

For any parameter `P` on calendar date `D`:

```
Z = (P_today − mean(P for date D ± 7 days across all historical years))
    / std(P for date D ± 7 days across all historical years)
```

A reading is flagged as anomalous when `|Z| > 2.0` (outside the 95th percentile of the historical distribution for that calendar period). Z-scores are computed with a minimum of 10 historical data points; the result is `null` when insufficient history exists.

### Snow Water Equivalent (SWE) — Temperature-Index Model

SWE is estimated from `daily_averages` using a simplified degree-day approach calibrated to the Ural River basin (Roshydromet standard DDF = 3.5 mm/°C/day).

**Accumulation rules (per day, Oct 1 → May 31):**

| Condition | Effect |
|---|---|
| Temperature < −1 °C | All precipitation added to snowpack |
| −1 °C ≤ Temperature < +2 °C | 50 % of precipitation added (mixed phase) |
| Temperature ≥ +2 °C | No accumulation |

**Melt rules (applied on the same day, after accumulation):**

| Condition | Effect |
|---|---|
| Temperature > 0 °C and SWE > 0 | Melt = DDF × (Temperature − 0) |
| Rain-on-snow event (precipitation > 1 mm while Temperature > 0 °C and SWE > 0) | Additional melt = precipitation × 0.8 |

SWE is clamped at 0 — it never goes negative.

### Composite Flood Risk Score

Five components are combined into a single 0–100 score:

| Component | Raw metric | Normalisation | Weight |
|---|---|---|---|
| Snowpack anomaly | SWE Z-score | clamp(Z / 4.0, 0, 1) | 35 % |
| Melt rate | Degree-days (last 14 days) | clamp(value / 30.0, 0, 1) | 25 % |
| Rain-on-snow events | Count (last 21 days) | clamp(count / 7.0, 0, 1) | 20 % |
| Precipitation anomaly | Rolling 30-day precipitation Z-score | clamp(Z / 3.0, 0, 1) | 10 % |
| Temperature trend | 14-day linear slope (°C/day) | clamp(slope / 3.0, 0, 1) | 10 % |

**Risk levels:**

| Score | Level | Colour |
|---|---|---|
| < 20 | Low | Green |
| 20–45 | Elevated | Yellow |
| 46–70 | High | Orange |
| > 70 | Critical | Red |

The score is set to 0 and level to "Low" during the off-season (June 1 – September 30).

### Standardised Precipitation Index (SPI)

Used for drought detection. The SPI-30 variant uses a rolling 30-day precipitation window:

```
SPI = (accumulated_precip − historical_mean) / historical_std
```

where `historical_mean` and `historical_std` are computed from the same 30-day windows in all past years. Drought is flagged when `SPI < −1.5`. Returns `null` when fewer than 3 years of historical data exist.

---

## Monitored Anomaly Types

| Anomaly | Detection trigger |
|---|---|
| Heat wave | Temperature Z-score > 2.0 for ≥ 3 consecutive days |
| Cold snap | Temperature Z-score < −2.0 for ≥ 3 consecutive days |
| Rapid pressure drop | Pressure falls ≥ 5 hPa in any 3-hour window (from hourly data) |
| Freezing rain | Precipitation > 0 and temperature between −5 °C and +1 °C |
| Fog conditions | (Temperature − dew point) ≤ 2 °C, wind speed < 1.5 m/s, cloud cover < 30 % |
| Drought (SPI-30) | SPI < −1.5 |
| Extreme UV | UV index Z-score > 2.0 and raw UV index ≥ 7 |
| Abnormal pressure high | Pressure Z-score > 2.5 |
| Strong wind event | Wind speed > 10 m/s and wind speed Z-score > 2.0 |
| Fire risk conditions | Humidity < 20 %, wind speed > 5 m/s, 7-day precipitation < 2 mm |
| Late spring frost | Temperature < −2 °C after ≥ 5 consecutive days with mean > +5 °C |
| Heat stress | Steadman apparent temperature (heat index) > 38 °C |

Anomaly state is persisted in the `anomaly_log` database table. A daily cron command (`php spark system:detectAnomalies`) opens new anomaly records and closes resolved ones.

---

## Visualization

### Section 1 — Spring Flood Risk

- **Risk badge:** large colour-coded label (green / yellow / orange / red) showing the current risk level and score out of 100.
- **Score gauge:** ECharts arc gauge, 0–100, fill colour driven by risk level.
- **Component breakdown:** one horizontal bar per component; fill width proportional to contribution; labels from i18n keys.
- **Disclaimer:** always visible, cannot be hidden — "This indicator reflects meteorological conditions only. Reservoir and dam operations are not modelled."
- **Off-season state** (June–September): the gauge is hidden and replaced by a neutral informational message.

Below the risk widget, a **Snowpack Chart** shows:
- Current-season SWE as a thick line coloured by risk level.
- Each previous season as a thin, faded reference line.
- The 2023–2024 flood season rendered in red at full opacity with a peak marker.
- A dashed horizontal line at the historical average SWE for the current date.

A **winter comparison table** beneath the chart lists each recorded season with its peak SWE and flood outcome.

### Section 2 — Parameter Anomaly Dashboard

Six cards in a responsive 3-column grid, one per parameter (temperature, pressure, precipitation, wind speed, humidity, UV index):

- **Z-score value** colour-coded: green (`|Z| < 1.5`), yellow (`1.5–2.0`), red (`> 2.0`).
- **Five-dot severity indicator:** filled dots scaled to `min(|Z| / 2, 1) × 5`.
- **Mini sparkline:** last 30 days of Z-score evolution (ECharts line, no axes).

### Section 3 — Active Anomalies

- Anomalies with `active = true` are rendered first as full-width banners with a red left border, showing the activation date and a description.
- All other anomaly types appear in a compact 3-column grid as grey "monitoring" cards showing the current Z-score or relevant metric and the last-triggered date if available.

### Section 4 — Anomaly History

- **12-month calendar heatmap** (GitHub-style 52 × 7 grid). Cell intensity is driven by the number of simultaneously active anomalies on each day: 0 = neutral, 1 = light, 2 = medium, ≥ 3 = full intensity. Hover tooltip shows the date and count.
- **History table** below the calendar: Type, Start date, End date (or "ongoing"), Duration (days), Peak value.

---

## Known Limitations

| Limitation | Impact |
|---|---|
| No snow depth sensor | SWE is estimated from precipitation + temperature; wind redistribution is not captured |
| Daily temperature averages only | Sub-zero overnight readings that arrest melt are invisible |
| No soil moisture or freeze-depth sensor | Soil absorption capacity cannot be directly measured |
| Reservoir discharge is unobservable | A significant fraction of flood magnitude lies outside the model |
| Single-point measurement | Upstream catchment conditions may differ from the station location |

Despite these constraints, the winter of 2023–2024 would have triggered "Critical" risk indicators 3–4 weeks before the April flood.

---

## Developer Reference

### API Endpoints

| Method | Route | Description |
|---|---|---|
| GET | `/anomaly` | Current anomaly monitor state (polls every 5 minutes from the UI) |
| GET | `/anomaly/history?season=YYYY-YYYY` | SWE series for a specific hydrological season (min year: 2022) |

### `GET /anomaly` — Response Shape

```json
{
  "floodRisk": {
    "score": 72,
    "level": "critical",
    "components": {
      "sweAnomaly":       { "value": 2.8,  "weight": 0.35, "contribution": 35 },
      "meltRate":         { "value": 18.4, "weight": 0.25, "contribution": 22 },
      "rainOnSnowDays":   { "value": 3,    "weight": 0.20, "contribution": 15 },
      "precipAnomaly":    { "value": 1.4,  "weight": 0.10, "contribution": 8  },
      "temperatureTrend": { "value": 1.2,  "weight": 0.10, "contribution": 7  }
    },
    "disclaimer": "This is a meteorological indicator only. Reservoir operations are not modelled.",
    "season": "active",
    "dataQuality": "good"
  },
  "snowpack": {
    "estimatedSWE": 184.3,
    "historicalAvgSWE": 98.2,
    "historicalStdSWE": 31.4,
    "sweZScore": 2.75,
    "series": [
      { "date": "2025-11-01", "swe": 0.0 },
      { "date": "2026-03-16", "swe": 184.3 }
    ],
    "comparisonYears": [
      { "year": "2022-2023", "maxSWE": 71.2,  "floodOccurred": false },
      { "year": "2023-2024", "maxSWE": 198.7, "floodOccurred": true  },
      { "year": "2024-2025", "maxSWE": 112.1, "floodOccurred": false },
      { "year": "2025-2026", "maxSWE": 184.3, "floodOccurred": null  }
    ]
  },
  "parameterZScores": {
    "temperature": 2.3,
    "pressure": -0.4,
    "precipitation": 1.8,
    "windSpeed": 0.7,
    "humidity": -1.2,
    "uvIndex": 0.3
  },
  "anomalies": [
    {
      "id": "freezing_rain",
      "active": true,
      "triggeredAt": "2026-03-14",
      "currentZScore": null
    },
    {
      "id": "cold_snap",
      "active": false,
      "lastTriggered": "2025-12-18",
      "currentZScore": -0.8
    }
  ],
  "anomalyHistory": [
    {
      "id": "uuid",
      "type": "freezing_rain",
      "startDate": "2026-03-14",
      "endDate": null,
      "peakValue": null,
      "description": "Precipitation during near-freezing temperatures"
    }
  ],
  "anomalyCalendar": [
    { "date": "2026-03-14", "activeCount": 1 },
    { "date": "2026-03-15", "activeCount": 1 }
  ]
}
```

**Error shape** (consistent with all other endpoints):
```json
{ "messages": { "error": "Descriptive error string" } }
```

### `GET /anomaly/history` — Response Shape

```json
{
  "season": "2023-2024",
  "series": [
    { "date": "2023-10-01", "swe": 0.0 },
    { "date": "2024-04-15", "swe": 198.7 }
  ]
}
```

### Backend Components

| Component | File | Role |
|---|---|---|
| `Anomaly` controller | `server/app/Controllers/Anomaly.php` | Handles `GET /anomaly` and `GET /anomaly/history`; assembles the full response from models and libraries |
| `SnowpackCalculator` library | `server/app/Libraries/SnowpackCalculator.php` | Temperature-index SWE accumulation and melt; melt rate and rain-on-snow counts |
| `AnomalyDetector` library | `server/app/Libraries/AnomalyDetector.php` | Z-score computation, SPI, and all individual anomaly condition checks |
| `AnomalyModel` | `server/app/Models/AnomalyModel.php` | Orchestrates flood risk score assembly, snowpack comparison, and parameter Z-scores |
| `AnomalyLogModel` | `server/app/Models/AnomalyLogModel.php` | CRUD on `anomaly_log`; calendar data aggregation |
| `DetectAnomalies` CLI command | `server/app/Commands/DetectAnomalies.php` | Daily cron job that opens/closes anomaly records in `anomaly_log` |

### Database Table: `anomaly_log`

| Column | Type | Notes |
|---|---|---|
| `id` | INT UNSIGNED | Primary key, auto-increment |
| `type` | VARCHAR(50) | Anomaly type key (e.g. `freezing_rain`) |
| `start_date` | DATE | Date the anomaly was first detected |
| `end_date` | DATE | Date the anomaly resolved; NULL if ongoing |
| `peak_value` | FLOAT | Peak Z-score or raw value during the event |
| `description` | TEXT | Human-readable summary |
| `created_at` | DATETIME | Row creation timestamp |
| `updated_at` | DATETIME | Last modification timestamp |

Migration file: `server/app/Database/Migrations/2026-03-17-000000_CreateAnomalyLogTable.php`

### Cron Schedule

Add alongside the existing daily average computation in the server crontab:

```
# Daily anomaly detection — runs after daily averages are calculated
0 6 * * *  cd /path/to/server && php spark system:calculateDailyAverages
5 6 * * *  cd /path/to/server && php spark system:detectAnomalies
```

### Frontend Components

| Component | Location | Purpose |
|---|---|---|
| `WidgetFloodRisk` | `client/components/widget-flood-risk/` | Risk gauge, component bars, disclaimer |
| `WidgetSnowpackChart` | `client/components/widget-snowpack-chart/` | Multi-season SWE line chart + comparison table |
| `WidgetParameterZScore` | `client/components/widget-parameter-z-score/` | Per-parameter Z-score card with sparkline |
| `WidgetAnomalyCard` | `client/components/widget-anomaly-card/` | Single anomaly status card (active / monitoring) |
| `WidgetAnomalyCalendar` | `client/components/widget-anomaly-calendar/` | 52-week contribution-calendar heatmap |

RTK Query endpoints: `useGetAnomalyQuery` and `useGetAnomalyHistoryQuery` (defined in `client/api/api.ts`).
TypeScript types: `client/api/types/anomaly.ts`, re-exported as `ApiType.Anomaly.*`.

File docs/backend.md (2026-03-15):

# Backend

## Stack

| Component | Version / Details |
|---|---|
| PHP | 8.2 |
| CodeIgniter | 4.6 |
| MySQL | Any version compatible with CI4 driver |
| GuzzleHTTP | 7 |
| firebase/php-jwt | JWT authentication for Arduino token |
| PHPUnit | 11.5 (testing) |
| Composer | Dependency management |

## Directory Structure

```
server/
├── app/
│   ├── Controllers/          # HTTP and CLI request handlers
│   ├── Models/               # Database query classes
│   ├── Entities/             # Data entity classes
│   ├── Libraries/            # External API integration clients
│   └── Database/
│       └── Migrations/       # Versioned schema migration files
├── tests/
│   ├── unit/                 # Unit tests (no DB)
│   └── database/             # Integration tests (DB required)
├── env                       # Environment template (copy to .env)
├── phpunit.xml.dist          # PHPUnit configuration
└── composer.json
```

## Controllers

| Controller  | Type | Purpose |
|---|---|---|
| `Current` | HTTP | Returns the latest sensor reading; also serves a plain-text summary via `/current/text`|
| `Forecast`  | HTTP | Returns daily and hourly forecast records from `forecast_weather_data` |
| `History` | HTTP | Queries `hourly_averages` / `daily_averages` for a date range; exports CSV |
| `Heatmap` | HTTP | Aggregates data for heatmap visualisation across a selected time period |
| `Sensors` | HTTP | Receives POST data from the Arduino, validates the token, writes to `raw_weather_data` |
| `System` | CLI  | Cron entry-points: fetch current aggregates, pull forecast data, push to NarodMon |

## Models

| Model | Table | Purpose |
|---|---|---|
| `RawWeatherDataModel` | `raw_weather_data` | Insert and query individual Arduino readings |
| `ForecastWeatherDataModel`| `forecast_weather_data`| Insert and query forecast records from external APIs |
| `HourlyAveragesModel` | `hourly_averages` | Query pre-aggregated hourly summaries |
| `DailyAveragesModel` | `daily_averages` | Query pre-aggregated daily summaries |

## External API Libraries

| Library | Role |
|---|---|
| `OpenWeatherMapAPILibrary` | Fetches forecast JSON from OpenWeatherMap and normalises it for storage |
| `WeatherAPILibrary` | Fetches forecast JSON from WeatherAPI.com and normalises it for storage |
| `VisualCrossingAPILibrary` | Fetches forecast JSON from VisualCrossing and normalises it for storage |
| `NarodMonAPILibrary` | Pushes current sensor readings outbound to the NarodMon monitoring network |

All libraries live in `server/app/Libraries/` and are injected into the `System` controller.

## API Route Table

| Method | Route | Controller action | Description |
|---|---|---|---|
| GET | `/current` | `Current::index` | Latest weather reading as JSON |
| GET | `/current/text` | `Current::text` | Latest weather reading as plain text |
| GET | `/forecast/daily` | `Forecast::daily` | Multi-day forecast records |
| GET | `/forecast/hourly`  | `Forecast::hourly` | Hourly forecast records |
| GET | `/history` | `History::index` | Historical averages for a date range |
| GET | `/history/export` | `History::export` | Download historical data as CSV |
| GET | `/heatmap` | `Heatmap::index` | Aggregated data for heatmap visualisation |
| POST | `/sensors` | `Sensors::create` | Receive and store an Arduino sensor reading |

## CLI Spark Commands

These commands are intended to be called by the server's cron daemon, not through HTTP.

```bash
# Aggregate raw sensor data into hourly/daily averages
php spark system:current

# Pull forecast data from all configured external APIs
php spark system:forecast

# Push the latest reading to NarodMon
php spark system:narodmon
```

Schedule example (run in `server/`):

```
*/5  * * * *  php spark system:current
0    */1 * * *  php spark system:forecast
*/10 * * * *  php spark system:narodmon
```

## Database Migrations

Migrations live in `server/app/Database/Migrations/`. The naming follows CodeIgniter's timestamp convention.

**Rules:**
- Never modify an existing migration file. Once a migration has been applied to any environment it is immutable.
- All new schema changes must be added as new migration files.
- Run migrations with `php spark migrate`.
- Roll back with `php spark migrate:rollback`.

## Validation Rules

The `Sensors` controller validates the incoming POST payload before writing to the database.

| Field | Rule | Notes |
|---|---|---|
| date | required, valid_date | Must be a parseable date string |
| source | required, in_list | Allowed values: `OpenWeatherMap`, `WeatherAPI`, `VisualCrossing`, `CustomStation`, `OtherSource` |
| All other sensor fields | permit_empty | Readings may be absent if a sensor is not connected or returns no value |

## Setup

```bash
# 1. Navigate to the server directory
cd server

# 2. Install PHP dependencies
composer install

# 3. Copy environment template and configure
cp env .env
# Edit .env — set database credentials, API keys, and app.arduino.token

# 4. Apply database migrations
php spark migrate

# 5. Start the built-in development server
php spark serve
# API available at http://localhost:8080
```

Key `.env` settings:

```ini
database.default.hostname = localhost
database.default.database = weather_station
database.default.username = your_db_user
database.default.password = your_db_password

app.arduino.token = your_secret_token

# External API keys
app.openWeatherMap.apiKey = ...
app.weatherApi.apiKey = ...
app.visualCrossing.apiKey = ...
app.narodmon.deviceId = ...
```

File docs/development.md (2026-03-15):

# Development Guide

## Prerequisites

| Tool | Minimum version | Purpose |
|---|---|---|
| Node.js | 20 | Frontend runtime and build tooling |
| Yarn | 4 | Frontend package manager |
| PHP | 8.2 | Backend runtime |
| Composer | Latest stable | PHP dependency manager |
| MySQL | Any CI4-compatible version | Backend database |
| Arduino IDE | 2.x recommended | Compile and upload the Arduino firmware |

## Complete Setup Walkthrough

### 1. Clone the Repository

```bash
git clone https://github.com/miksrv/arduino-weather-station.git
cd arduino-weather-station
```

### 2. Server Setup (PHP + CodeIgniter)

```bash
cd server

# Install PHP dependencies
composer install

# Copy environment template
cp env .env

# Edit .env — minimum required settings:
#   database.default.hostname
#   database.default.database
#   database.default.username
#   database.default.password
#   app.arduino.token          (shared secret with the Arduino sketch)
#   app.openWeatherMap.apiKey  (if using forecast)
#   app.weatherApi.apiKey      (if using forecast)
#   app.visualCrossing.apiKey  (if using forecast)
#   app.narodmon.deviceId      (if pushing to NarodMon)

# Apply database migrations
php spark migrate

# Start the development server
php spark serve
# API available at http://localhost:8080
```

### 3. Client Setup (Next.js)

```bash
cd client

# Install frontend dependencies
yarn install

# Copy environment template
cp env .env.local

# Edit .env.local:
#   NEXT_PUBLIC_API_HOST    = 'http://localhost:8080/'
#   NEXT_PUBLIC_SITE_LINK   = 'http://localhost:3000/'
#   NEXT_PUBLIC_STORAGE_KEY = 'meteo'

# Start the development server
yarn dev
# Dashboard available at http://localhost:3000
```

### 4. Arduino Setup

```bash
# Open the sketch in the Arduino IDE:
arduino/main/main.ino
```

Configure these constants inside `main.ino`:

| Constant | Description |
|---|---|
| `API_SERVER` | URL of your backend, e.g. `http://192.168.1.100:8080` |
| `API_METHOD` | Endpoint path — default `/sensors`, change only if modified  |
| `API_SECRET` | Must match `app.arduino.token` in the server `.env` |
| `PIN_ANEMOMETR` | Arduino pin connected to the anemometer (default: 3, interrupt) |
| `PIN_DHT22` | Arduino pin connected to the DHT22 (default: 4) |
| `PIN_UV_OUT` | Analog pin for GY-ML8511 output (default: A0) |
| `PIN_UV_REF` | Analog pin for GY-ML8511 reference (default: A1) |

Before compiling, extract the bundled libraries into the Arduino IDE `libraries/` folder:

- `arduino/BMP085_Library.zip`
- `arduino/PCF8574_Library.zip`

Then connect your Arduino and upload the sketch.

## Development Commands

### Client

```bash
# Start development server with hot reload
yarn dev

# Type-check and build for production
yarn build

# Serve the production build
yarn start

# Run all tests
yarn test

# Run tests with coverage
yarn test:coverage

# Lint source files
yarn lint

# Format source files
yarn format
```

### Server

```bash
# Start the built-in PHP development server
php spark serve

# Apply pending migrations
php spark migrate

# Roll back the last migration batch
php spark migrate:rollback

# Aggregate raw data into hourly/daily averages
php spark system:current

# Pull forecast from all configured external APIs
php spark system:forecast

# Push latest reading to NarodMon
php spark system:narodmon

# Run PHP unit tests
vendor/bin/phpunit
```

## PHP Code Conventions

| Convention | Rule |
|---|---|
| Namespaces | Follow PSR-4: `App\Controllers`, `App\Models`, `App\Libraries`, etc. |
| Type hints | Required on all method parameters and return types |
| DocBlocks | Required on all public methods; include `@param` and `@return` tags |
| Private methods | Prefix with underscore: `_myPrivateMethod()` |
| Constants | `UPPER_SNAKE_CASE` |
| SQL | No raw SQL strings in controllers — all queries go through Model methods |
| Environment values | Access via `env('key')` or `$this->request->env()`; never `$_ENV` directly |

## TypeScript Code Conventions

| Convention | Rule |
|---|---|
| Semicolons | No semicolons |
| Quotes | Single quotes |
| `any` type | Prohibited — use specific types or `unknown` |
| Import order | External packages first, then internal aliases, then relative paths |
| JSX nesting depth  | Maximum 4 levels — extract sub-components if deeper |
| `console.log` | Must not appear in committed code |
| Styling | CSS Modules only — no inline `style` props, no arbitrary class strings |
| API calls | RTK Query endpoints only — no raw `fetch` or Axios in components |
| State | Redux (RTK) for global state; `useState` only for component-local UI state |

## Branch and PR Workflow

1. Create a feature branch from `main`:
   ```bash
   git checkout -b feature/your-feature-name
   ```
2. Make changes and commit with a descriptive message.
3. Push and open a pull request targeting `main`.
4. The `ui-checks.yml` workflow runs automatically on every PR: ESLint, Prettier, Jest, and `next build` must all pass.
5. After review and approval, merge to `main`. The deploy workflows (`ui-deploy.yml`, `api-deploy.yml`) trigger on push to `main`.

## Environment Variable Reference

### Client (`client/.env.local`)

| Variable | Example value | Description |
|---|---|---|
| `NEXT_PUBLIC_API_HOST` | `http://localhost:8080/` | Backend API base URL |
| `NEXT_PUBLIC_SITE_LINK` | `http://localhost:3000/` | Public frontend URL (used for canonical links)  |
| `NEXT_PUBLIC_STORAGE_KEY` | `meteo` | localStorage key prefix |

### Server (`server/.env`)

| Variable | Description |
|---|---|
| `database.default.hostname` | MySQL host |
| `database.default.database` | Database name |
| `database.default.username` | Database user |
| `database.default.password` | Database password |
| `app.arduino.token` | Shared secret for Arduino authentication |
| `app.openWeatherMap.apiKey` | OpenWeatherMap API key |
| `app.openWeatherMap.latitude` | Station latitude for forecast requests |
| `app.openWeatherMap.longitude` | Station longitude for forecast requests |
| `app.weatherApi.apiKey` | WeatherAPI.com API key |
| `app.visualCrossing.apiKey` | VisualCrossing API key |
| `app.narodmon.deviceId` | NarodMon device identifier |

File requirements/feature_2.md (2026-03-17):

# Feature 2: Astronomical Observation Planner

## Overview

Since the weather station operates from a **DIY observatory**, this feature answers the most important question for any amateur astronomer: *"Is tonight good for observing?"*

The **Observation Planner** page combines the station's live sensor data with an astronomical index to produce a real-time and 48-hour outlook of sky conditions — clear sky percentage, atmospheric transparency, seeing estimate, and a composite "observability score." It also shows the current Moon phase (with age and illumination), and highlights the next predicted window of good observing conditions.

This feature is unique to this station's context and cannot be replicated from generic weather services.

---

## Motivation

- The station is physically located at an observatory — this is the single most relevant use case for its operator.
- Existing weather services provide cloud cover, but not an astronomer-friendly summary that integrates humidity, wind stability, and transparency into one actionable score.
- Moon phase data is a hard dependency for any observing plan — bright full moons wash out deep-sky targets.
- The station already collects all needed raw inputs: clouds, humidity, wind_speed, wind_gust, uv_index, sol_radiation, visibility.

---

## Astronomical Indices (Computed on Backend)

### 1. Transparency Index (0–5 scale)

Estimates how well light passes through the atmosphere. Derived from:
- `humidity` (lower = more transparent)
- `clouds` (%)
- `visibility` (km)
- `pressure` (stability proxy)

Formula (simplified example):
```
transparency = 5
  - (humidity / 100) * 1.5
  - (clouds / 100) * 2.5
  - max(0, (10 - visibility_km) / 10) * 1.0
```
Clamp to [0, 5].

### 2. Seeing Index (0–5 scale, Antoniadi scale analog)

Estimates atmospheric steadiness (important for planetary viewing). Derived from:
- `wind_speed` (lower = steadier)
- `wind_gust - wind_speed` differential (turbulence indicator)
- `temperature` stability (compare last 3 readings)

Formula (simplified):
```
seeing = 5
  - min(wind_speed / 5, 2.0)
  - min((wind_gust - wind_speed) / 5, 1.5)
  - temperature_variance_penalty (0–1.5 based on std dev of last 3 readings)
```
Clamp to [0, 5].

### 3. Observability Score (0–10 composite)

```
score = (transparency / 5) * 5 + (seeing / 5) * 3 + (clouds == 0 ? 2 : 0)
```
Labels:
- 0–2: Poor
- 3–4: Below Average
- 5–6: Average
- 7–8: Good
- 9–10: Excellent

### 4. Moon Phase

Calculated purely from the current date using the standard synodic cycle formula (no external API needed):

```
age_days = (julian_day - 2451550.1) mod 29.530588853
illumination = (1 - cos(2π * age_days / 29.53)) / 2 * 100  [%]
phase_name = new | waxing_crescent | first_quarter | waxing_gibbous |
             full | waning_gibbous | last_quarter | waning_crescent
```

---

## Backend Requirements

### Controller: `Astronomy` (`server/app/Controllers/Astronomy.php`)

- Extends `ResourceController`.
- `index()` → `GET /astronomy` — returns current conditions + 48-hour outlook.
- `moon()` → `GET /astronomy/moon` — returns moon phase for a given date (optional `date` query param, defaults to today).

### Library: `AstronomyCalculator` (`server/app/Libraries/AstronomyCalculator.php`)

Methods:
- `getMoonPhase(DateTime $date): array` — returns `age_days`, `illumination`, `phase_name`, `next_new_moon` (DateTime), `next_full_moon` (DateTime).
- `getTransparency(array $weatherData): float` — 0–5.
- `getSeeing(array $currentReading, array $recentReadings): float` — 0–5, uses last 3 raw readings for temperature variance.
- `getObservabilityScore(float $transparency, float $seeing, int $clouds): float` — 0–10.
- `getScoreLabel(float $score): string` — returns `'poor'|'below_average'|'average'|'good'|'excellent'`.

### Response Shape (`GET /astronomy`)

```json
{
  "current": {
    "transparency": 3.8,
    "seeing": 4.1,
    "score": 7.5,
    "scoreLabel": "good",
    "clouds": 12,
    "humidity": 45,
    "windSpeed": 2.3,
    "visibility": 18.0
  },
  "moon": {
    "ageDays": 5.3,
    "illumination": 28.4,
    "phaseName": "waxing_crescent",
    "nextNewMoon": "2026-04-01",
    "nextFullMoon": "2026-03-29"
  },
  "forecast": [
    {
      "time": "2026-03-16T21:00:00Z",
      "score": 7.5,
      "scoreLabel": "good",
      "clouds": 12,
      "transparency": 3.8,
      "seeing": 4.1
    },
    ...
  ],
  "bestWindowStart": "2026-03-16T22:00:00Z",
  "bestWindowEnd":   "2026-03-17T04:00:00Z"
}
```

The `forecast` array is derived by applying the index formulas to the existing `forecast_weather_data` rows for the next 48 hours. `bestWindow` is the longest contiguous stretch where `score >= 7`.

### Route

```php
$routes->get('astronomy',       'Astronomy::index');
$routes->get('astronomy/moon',  'Astronomy::moon');
```

### PHPUnit Tests (`server/tests/unit/AstronomyCalculatorTest.php`)

- Known moon phase test: verify illumination and phase name for a specific historical date.
- Transparency: verify score drops when humidity/clouds increase.
- Seeing: verify score drops when wind_gust significantly exceeds wind_speed.
- Score label thresholds.

---

## Frontend Requirements

### New Page: `/astronomy` (`client/pages/astronomy.tsx`)

Layout:

```
[Page Header: "Observation Planner"]
[Live refresh: every 5 minutes]

┌──────────────────────────────────────────────────────┐
│  TONIGHT'S FORECAST                                   │
│  Observability Score: 7.5 / 10   ★★★★☆  GOOD        │
│  Best window: 22:00 – 04:00                          │
└──────────────────────────────────────────────────────┘

┌──────────────────┐  ┌──────────────────┐
│  Transparency    │  │  Seeing          │
│  ████████░░ 3.8  │  │  ████████░░ 4.1  │
│  /5 Good         │  │  /5 Good         │
└──────────────────┘  └──────────────────┘

┌──────────────────────────────────────────────────────┐
│  MOON                                                 │
│  [Moon phase SVG diagram]                             │
│  Waxing Crescent · 5.3 days old · 28% illuminated    │
│  Next New Moon: 1 Apr 2026 · Next Full: 29 Mar 2026  │
└──────────────────┘

┌──────────────────────────────────────────────────────┐
│  48-HOUR OBSERVABILITY CHART                          │
│  [ECharts line chart: score over time, color bands]  │
│  [Color zones: red=poor, yellow=average, green=good] │
└──────────────────────────────────────────────────────┘

┌──────────────────────────────────────────────────────┐
│  CURRENT CONDITIONS (contributing factors)            │
│  Clouds: 12%  Humidity: 45%  Wind: 2.3 m/s  Vis: 18km│
└──────────────────────────────────────────────────────┘
```

### New Component: `WidgetObservabilityScore` (`client/components/widget-observability-score/`)

- Circular gauge (0–10) rendered in ECharts.
- Color: red (0–4), yellow (5–6), green (7–10).
- Shows score number and label ("Good", "Excellent", etc.).

### New Component: `WidgetMoonPhase` (`client/components/widget-moon-phase/`)

- Renders a CSS/SVG moon phase diagram based on `illumination` and `phaseName`.
- Shows age, illumination %, phase name.
- Shows next new moon and full moon dates.

### New Component: `WidgetObservabilityChart` (`client/components/widget-observability-chart/`)

- ECharts `line` chart of `score` over the 48-hour forecast array.
- Time axis with hour labels.
- Colored background bands (thresholds at 5 and 7).
- Tooltip shows all contributing values on hover.

### New RTK Query Endpoint (`client/api/endpoints/Astronomy.ts`)

```typescript
interface AstronomyForecastItem {
  time: string
  score: number
  scoreLabel: 'poor' | 'below_average' | 'average' | 'good' | 'excellent'
  clouds: number
  transparency: number
  seeing: number
}

interface MoonData {
  ageDays: number
  illumination: number
  phaseName: string
  nextNewMoon: string
  nextFullMoon: string
}

interface AstronomyResponse {
  current: {
    transparency: number
    seeing: number
    score: number
    scoreLabel: string
    clouds: number
    humidity: number
    windSpeed: number
    visibility: number
  }
  moon: MoonData
  forecast: AstronomyForecastItem[]
  bestWindowStart: string | null
  bestWindowEnd: string | null
}
```

Polling interval: `300_000` ms (5 minutes).

### Navigation

Add "Astronomy" (with a telescope icon) to the main navigation menu.

---

## i18n Requirements

```json
"astronomy": "Astronomy",
"observation-planner": "Observation Planner",
"observability-score": "Observability Score",
"transparency": "Transparency",
"seeing": "Seeing",
"moon-phase": "Moon Phase",
"moon-age": "Moon age",
"moon-illumination": "Illumination",
"next-new-moon": "Next new moon",
"next-full-moon": "Next full moon",
"best-observing-window": "Best observing window",
"no-good-window": "No good window forecast in next 48 hours",
"score-poor": "Poor",
"score-below-average": "Below average",
"score-average": "Average",
"score-good": "Good",
"score-excellent": "Excellent",
"48h-observability": "48-hour observability forecast",
"phase-new": "New Moon",
"phase-waxing_crescent": "Waxing Crescent",
"phase-first_quarter": "First Quarter",
"phase-waxing_gibbous": "Waxing Gibbous",
"phase-full": "Full Moon",
"phase-waning_gibbous": "Waning Gibbous",
"phase-last_quarter": "Last Quarter",
"phase-waning_crescent": "Waning Crescent",
"astronomy-page-description": "Real-time astronomical observing conditions from the station — sky transparency, atmospheric seeing, and moon phase"
```

---

## Acceptance Criteria

1. `/astronomy` page loads and displays current transparency, seeing, and composite score.
2. The moon phase widget correctly identifies phase and illumination for today's date.
3. The 48-hour chart renders with color-coded quality zones.
4. The "best window" banner shows the longest consecutive period with score ≥ 7, or a "no good window" message.
5. `AstronomyCalculator::getMoonPhase()` passes a known-date unit test.
6. Both `en` and `ru` translations are complete.
7. The page polls every 5 minutes for fresh data.

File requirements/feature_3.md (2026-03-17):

# Feature 3: Wind Rose & Wind Analysis

## Overview

A dedicated **Wind** page providing a full statistical breakdown of wind behavior at the station's location. The centrepiece is an interactive **wind rose diagram** — a polar chart showing the frequency and speed distribution of wind across 16 compass sectors. Alongside it, the page presents speed distribution histograms, calm-day statistics, and strongest recorded gusts — giving a complete picture of the local wind climate.

Wind data is one of the richest datasets the station records (`wind_speed`, `wind_deg`, `wind_gust`) and is currently under-represented: it only appears as a single value on the Sensors page.

---

## Motivation

- The station records wind direction and speed at every 10-minute interval, making multi-year directional analysis possible.
- Wind rose diagrams are standard in meteorology but absent from most DIY stations.
- Understanding prevailing wind direction is practically useful for the observatory (dome orientation, tube currents) and for local residents.
- Gust frequency analysis helps identify storm patterns.

---

## Scope

### New API Endpoint

**`GET /wind`**

Returns aggregated wind statistics for a configurable time range.

#### Query Parameters

| Parameter | Type | Default | Description |
|---|---|---|---|
| `start_date` | date string | 30 days ago | Range start (ISO date) |
| `end_date` | date string | today | Range end (ISO date) |
| `source` | `station` \| `all` | `all` | Filter by data source |
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

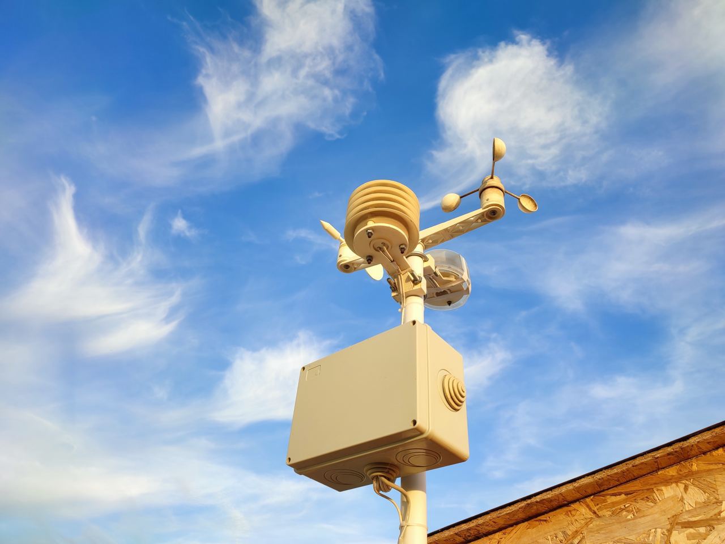
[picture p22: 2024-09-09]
docs/arduino-weather-station-2.jpg

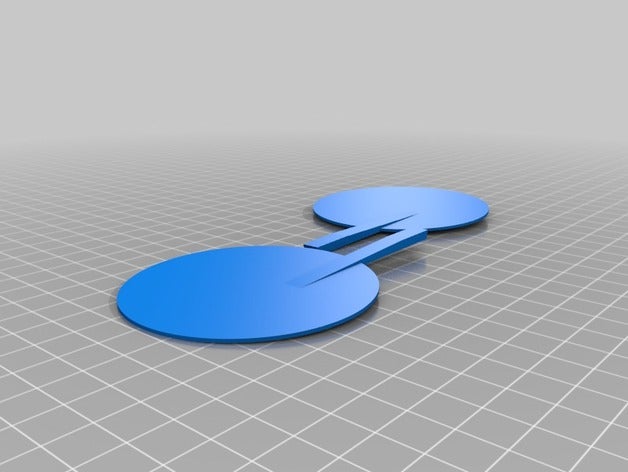
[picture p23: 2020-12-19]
models/wind-direction/tail.jpg

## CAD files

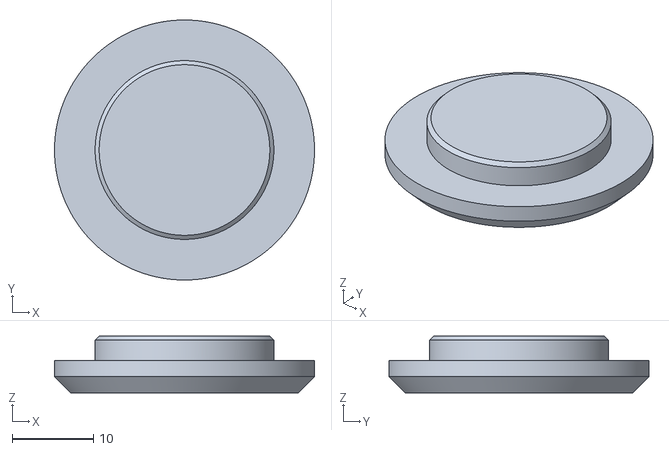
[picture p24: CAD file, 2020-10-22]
models/anemometr/anemometr-sep3.stl
32.0 x 32.0 x 7.00

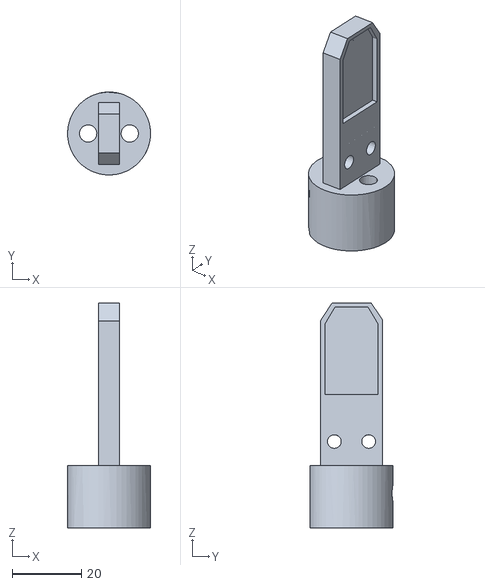
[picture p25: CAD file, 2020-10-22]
models/dht22-bmp085-mount/DHT22_and_BMP085_Mount.stl
24.0 x 24.0 x 65.0

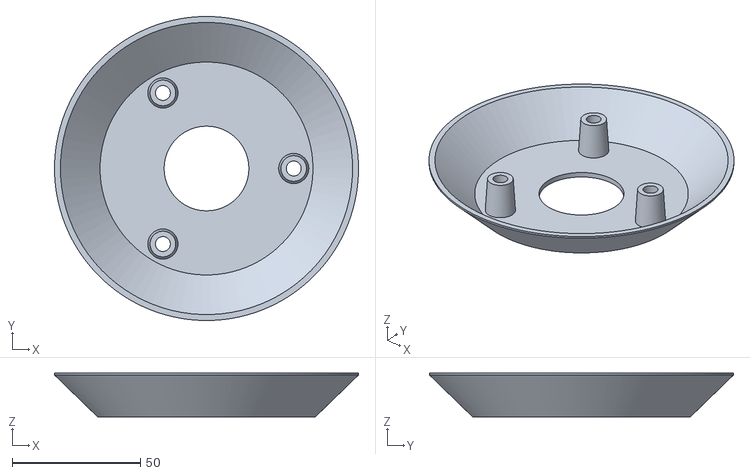
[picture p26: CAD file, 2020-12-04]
models/radiation-shield/rad_shd.stl
118.5 x 118.5 x 17.0

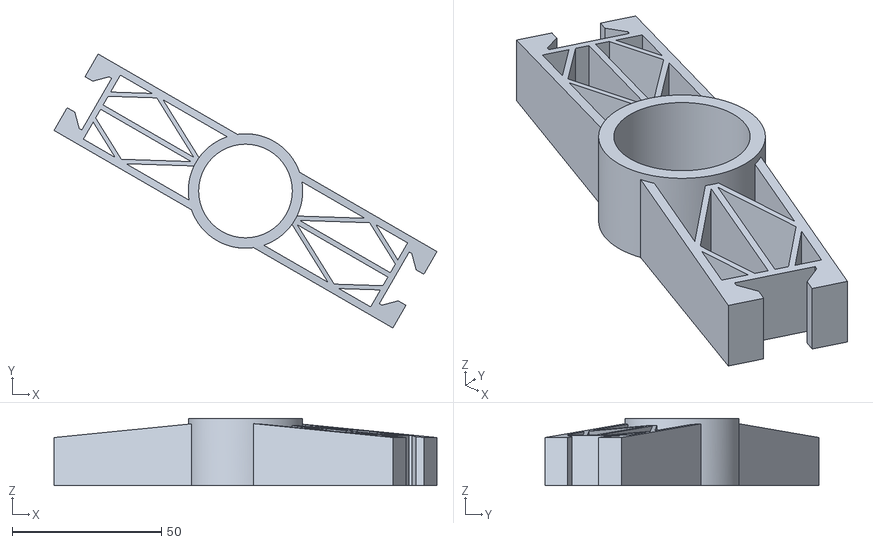
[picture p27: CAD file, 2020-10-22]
models/sensors-holder/sensors_holder_center.stl
128.5 x 91.9 x 22.5

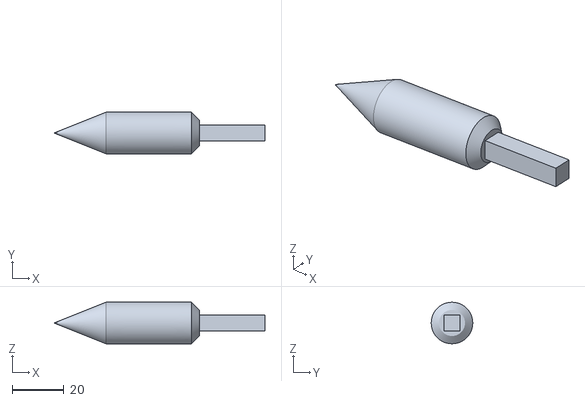
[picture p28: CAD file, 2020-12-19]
models/wind-direction/arrow.stl
81.3 x 16.0 x 16.0

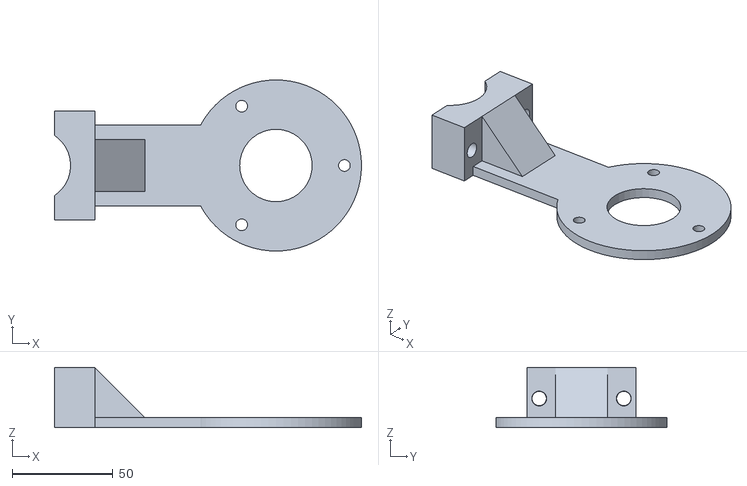
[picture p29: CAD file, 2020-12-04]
models/radiation-shield/rad_shd_vert_mount.stl
152.5 x 85.0 x 30.0

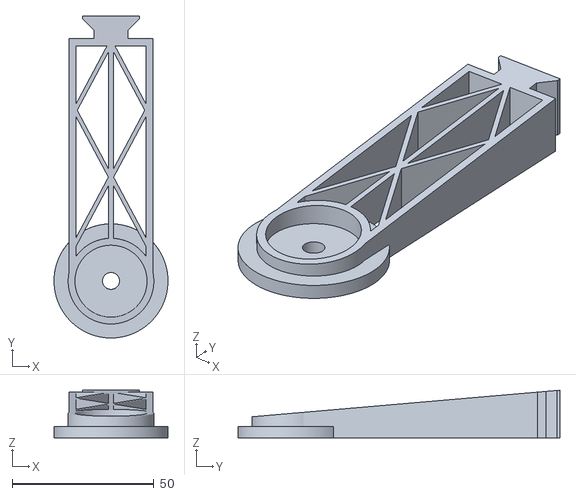
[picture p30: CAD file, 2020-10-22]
models/sensors-holder/sensors_holder_arm_X2.stl
40.2 x 113.5 x 16.8

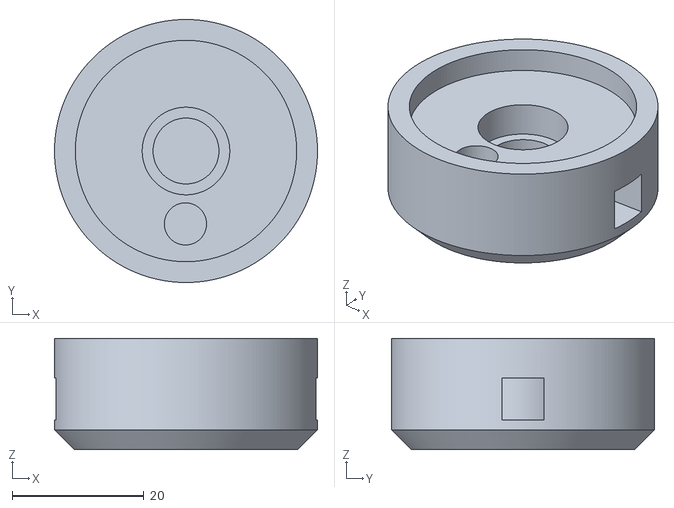
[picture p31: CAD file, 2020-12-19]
models/wind-direction/top.stl
39.9 x 39.9 x 16.9

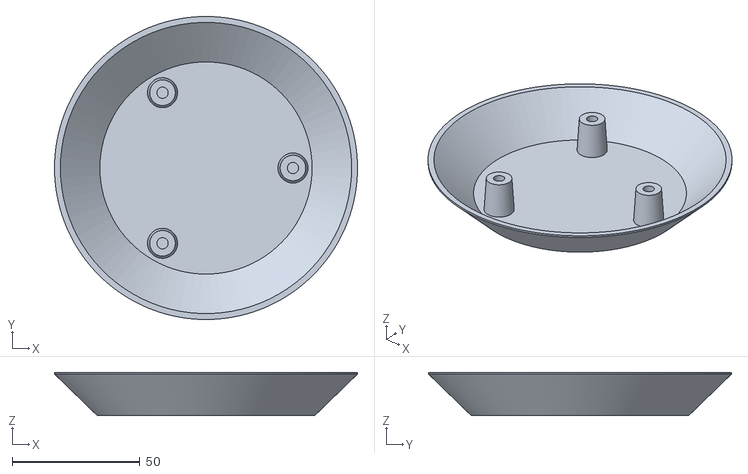
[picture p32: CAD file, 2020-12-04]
models/radiation-shield/rad_shd_top.stl
118.5 x 118.5 x 17.0

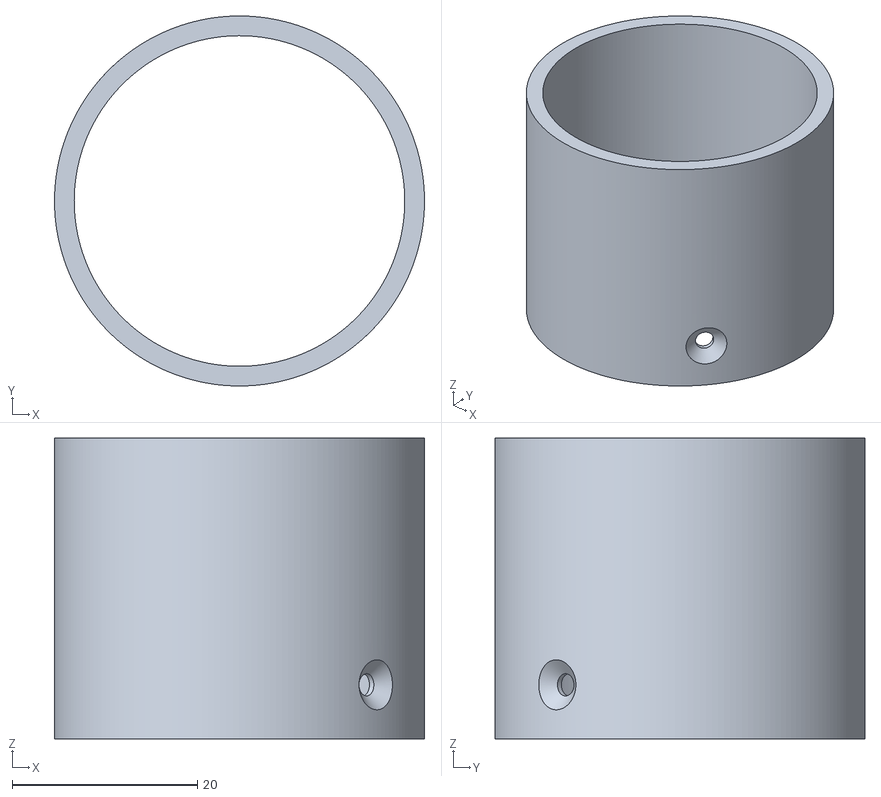
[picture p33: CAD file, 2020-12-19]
models/wind-direction/body.stl
40.0 x 40.0 x 32.5

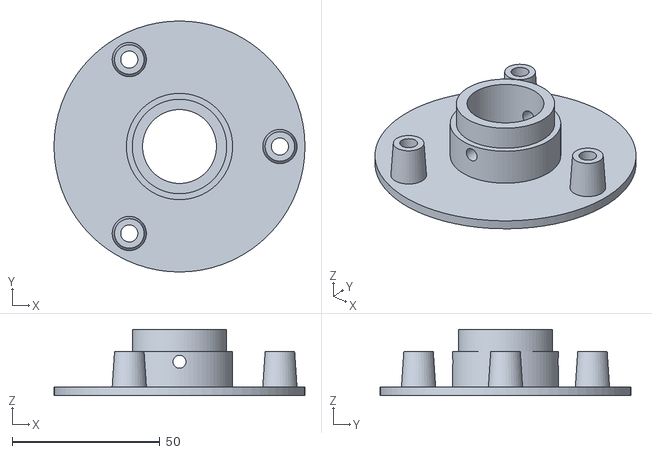
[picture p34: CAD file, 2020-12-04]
models/radiation-shield/rad_shd_base.stl
85.0 x 85.0 x 22.5

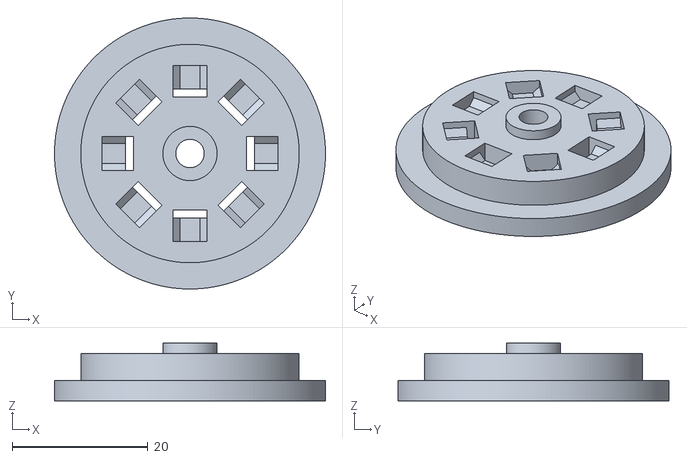
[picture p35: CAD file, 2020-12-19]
models/wind-direction/sensor_holder.stl
40.0 x 40.0 x 8.50

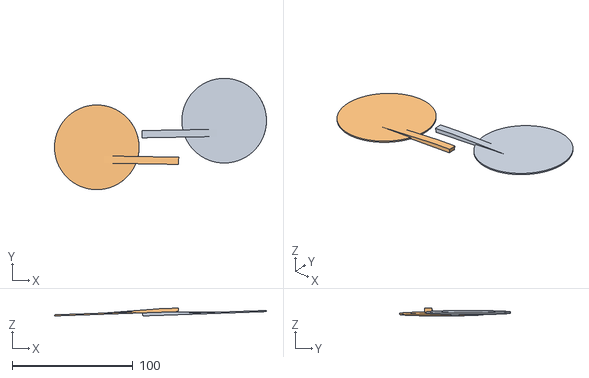
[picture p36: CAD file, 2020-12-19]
models/wind-direction/tail.stl
175.3 x 92.0 x 6.59

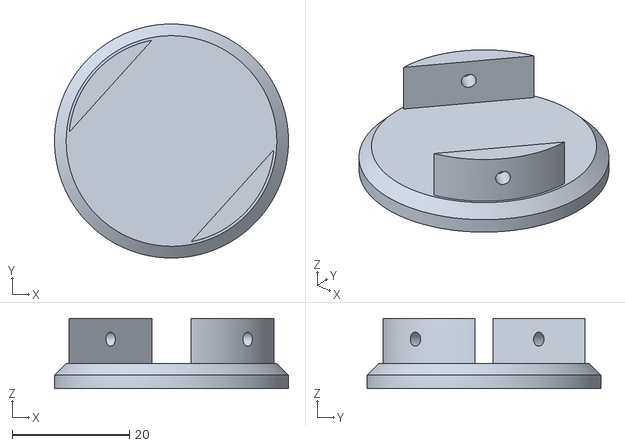
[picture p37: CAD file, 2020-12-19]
models/wind-direction/bottom.stl
40.0 x 40.0 x 12.0

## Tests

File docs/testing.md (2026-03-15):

# Testing Guide

## Server Testing (PHPUnit)

### Setup

| Item | Details |
|---|---|
| Framework | PHPUnit 11.5 |
| Configuration | `server/phpunit.xml.dist` |
| Test paths | `server/tests/unit/`, `server/tests/database/` |
| Bootstrap | CodeIgniter 4 framework bootstrap (configured in `phpunit.xml.dist`) |

### Test Categories

| Directory | Type | Description |
|---|---|---|
| `server/tests/unit/` | Unit tests | Test individual classes in isolation, no DB needed |
| `server/tests/database/`  | Integration tests | Test models and queries against a real database |

### Running Tests

```bash
cd server

# Run all tests
vendor/bin/phpunit

# Run only unit tests
vendor/bin/phpunit --testsuite unit

# Run only database tests
vendor/bin/phpunit --testsuite database

# Run with verbose output
vendor/bin/phpunit --testdox
```

### Coverage

Coverage is configured in `server/phpunit.xml.dist`:

- **Source:** `server/app/**/*.php`
- **Excluded:** view files, `Routes.php`
- **Output formats:** HTML report and Clover XML (`clover.xml`)

To generate a coverage report locally PHP must have Xdebug or PCOV installed:

```bash
vendor/bin/phpunit --coverage-html coverage/
```

---

## Client Testing (Jest)

### Setup

| Item | Details |
|---|---|
| Framework | Jest 30 |
| TypeScript runner | ts-jest |
| DOM environment | jsdom |
| React utilities | @testing-library/react |

### Test File Locations

Tests are co-located close to the code they cover:

| Location | What is tested |
|---|---|
| `client/tools/*.test.ts` | Pure utility / helper functions |
| Next to component files | Component render and interaction tests |

### Running Tests

```bash
cd client

# Run all tests (watch mode in interactive terminal)
yarn test

# Run all tests once (CI mode)
yarn test --ci

# Run with coverage
yarn test:coverage
```

### Coverage

- **Included:** all `.ts` and `.tsx` files
- **Excluded:** test files themselves (`*.test.ts`, `*.test.tsx`), index barrel files (`index.ts`), Next.js page files (covered by E2E, not unit tests)

---

## CI Pipelines

### `ui-checks.yml` — Pull Request Quality Gate

Runs on every PR targeting `main`. Steps:

1. Install dependencies (`yarn install`)
2. Run ESLint
3. Run Prettier check
4. Run Jest (`yarn test --ci`)
5. Run `yarn build` (type-check + Next.js compilation)

All steps must pass before a PR can be merged.

### `sonarcloud.yml` — Code Quality Analysis

Runs on push and PR events. Steps:

1. Run Jest with LCOV coverage output
2. Upload LCOV report to SonarCloud
3. SonarCloud evaluates the quality gate

| SonarCloud setting | Value |
|---|---|
| Project key | `miksrv_arduino-weather-station` |
| Organisation | `miksoft` |

### `arduino-code-check.yml` — Firmware Compilation

Compiles the Arduino sketch to verify it builds without errors on every push and PR. No upload to hardware occurs in CI.

---

## Testing Conventions

### General

- `test.only` and `test.skip` must not appear in committed code — use them locally only.
- Tests must be deterministic: avoid relying on the current system time; use Jest fake timers instead.
- Test descriptions should read as plain English sentences (`it('returns humidity as a number')`).

### React Component Tests (@testing-library)

- Use `render` and `screen` from `@testing-library/react`; do not query the DOM directly.
- Do not test implementation details (internal state, private methods). Test visible behaviour and rendered output.
- Prefer `getByRole`, `getByLabelText`, and `getByText` over `getByTestId` wherever possible.
- For async behaviour use `waitFor` or `findBy*` queries.

### Utility Function Tests

- Keep tests in `client/tools/*.test.ts` co-located with the utility file.
- One `describe` block per function, with distinct `it` cases for each significant input or edge case.
- Use Jest fake timers (`jest.useFakeTimers`) whenever a function depends on the current date or time.

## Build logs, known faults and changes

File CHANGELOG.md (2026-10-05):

# CHANGELOG

## 3.8.0

### Minor Changes

- Upgrade `simple-react-ui-kit` to 2.0 and switch to its `theme.css` design tokens; replace `light.css`/`dark.css` with a small project override file
- Use one flat 4px radius for all elements and kit radius tokens in widget styles
- Fix clipped borders on forecast cards and their loading skeletons
- Improve sidebar menu hover, active and focus states
- Update client and server dependencies

## 3.7.7

### Patch Changes

- Add a system events feed (`GET /events`, `EventFeedBuilder`) that surfaces significant sensor changes, wind gusts, precipitation runs, anomaly start/end entries, and a `system_status` freshness flag derived from the latest `raw_weather_data` row; expose it on `/sensors` via a new `widget-event-log` widget, with full PHPUnit and Jest coverage
- Fix `Current::getCurrentWeather` throwing an unhandled 500 when the latest sensor reading is older than 30 minutes (`array_merge()` receiving `null` from `RawWeatherDataModel::getRecentAverages()`); add `lastUpdated`/`isStale` fields to the `/current` response so the frontend can flag stale sensor data instead of silently rendering it as current
- Revamp the `/sensors` dashboard layout with new dedicated widgets — `widget-sensor-stat`, `widget-sensor-uv` (with UV scale), `widget-sensor-wind` (with compass), `widget-wind-rose`, `widget-precip`, and `widget-charts-panel` — built on new reusable building blocks (`WidgetCard`, `WidgetTile`, `StatBlock`, `SparklineChart`) and ECharts theme color utilities
- Add an Open-Meteo weather provider alongside OpenWeatherMap/WeatherAPI/VisualCrossing, including air quality fields (new migration plus entity/model support) and a shared `WeatherProviderInterface`/`AbstractWeatherAPILibrary` base now used uniformly by the `GetCurrentWeather`/`GetForecastWeather` commands
- Fix broken hook import paths after moving shared hooks (`useClientOnly`, `useLocalStorage`) from `client/tools` to `client/hooks`, affecting `AppBar` and `LanguageSwitcher`
- Fix null-safety issues in `widget-flood-risk`, `widget-heatmap`, and `WidgetSummary` utilities
- Bump frontend i18n/lint dependencies; rename server env template (`.env.production` → `env`) and update setup docs

## 3.7.6

### Patch Changes

- Handle history date params and locale redirect UX
- Update deps and harden API error handling

## 3.7.5

### Patch Changes

- Migrate all component `useTranslation` imports from `next-i18next` to `next-i18next/pages` following the next-i18next v16 breaking change; update all Jest mocks to the new module path across all affected components and tests
- Migrate SEO integration from `NextSeo`/`DefaultSeo` components to `generateNextSeo`/`generateDefaultSeo` functions from `next-seo/pages` wrapped in `<Head>` (next-seo v7 API) across all pages; preserve existing title, description, canonical, openGraph, and twitter metadata
- Replace `ColumnProps` with `TableColumnProps` after simple-react-ui-kit API rename in `WidgetAnomalyHistory`, `WidgetForecastTable`, and `ComparisonTable` components
- Set `rootDir` and `ignoreDeprecations: "6.0"` in Jest TypeScript config to fix source resolution and suppress TypeScript 6 deprecation diagnostics during test runs
- Refactor all backend controllers (Anomaly, Climate, Current, Forecast, Heatmap, History, Precipitation, Sensors) to use constructor dependency injection, explicit `$format = 'json'`, unified error handling and logging, consistent caching keys and TTL logic, and stricter input validation
- Standardize model definitions across all models (AnomalyLogModel, ClimateModel, DailyAveragesModel, ForecastWeatherDataModel, HourlyAveragesModel, PrecipitationModel, RawWeatherDataModel): add explicit model properties, timestamps config, validation rules/messages, stricter type hints, and remove legacy `$casts` arrays
- Refactor `WeatherData` into a read-only DTO with snake_case/camelCase key normalization; add nullable casts, `$dates` arrays, and `datamap` entries to `WeatherDataEntity` and `WeatherForecastEntity` for correct NULL handling and DB column mapping
- Add PHPUnit tests for `AnomalyController`, `ClimateController`, and `PrecipitationController` covering parameter validation, happy/exception paths, cache-hit behavior, and private helper coverage via reflection; expand `AnomalyLogModel` tests with additional edge cases for `closeAnomaly`, `getOpenByType`, `getHistory`, and `getCalendarData`
- Increase CI/CD API deploy job timeout to 25 minutes to prevent premature termination of long-running deployments
- Bump client dependencies: `next` 16.2.2 → 16.2.3, `react`/`react-dom` 19.2.4 → 19.2.5, `prettier` 3.8.1 → 3.8.2, `@typescript-eslint/*` 8.58.0 → 8.58.1, `eslint-plugin-jest` 29.15.1 → 29.15.2, `next-i18next` → v16, `next-seo` → v7; revert `simple-react-ui-kit` to previous version

## 3.7.4

### Patch Changes

- Fix `WeatherIcon` to return `/icons/unknown.svg` fallback when `weatherId` is `undefined`, `null`, or not present in the icon mapping; add `unknown.svg` placeholder asset
- Fix `WidgetSensor` min/max block to always render — show em-dash (`—`) for missing values instead of hiding the block; replace hardcoded `'??'` fallback with `t('no-data')` i18n key
- Fix `WidgetSummary` badges showing `undefined` when weather fields are absent; add `?? t('no-data')` fallback for wind, precipitation, humidity, and pressure
- Fix `findMinValue` / `findMaxValue` returning `Infinity` / `-Infinity` for empty or all-undefined arrays — now return `undefined` instead
- Replace `any` types in ECharts tooltip formatters with `TopLevelFormatterParams` and `CallbackDataParams` across 7 components (`widget-chart`, `widget-meteogram`, `widget-climate`, `widget-heatmap`, `widget-precip-chart`, `widget-anomaly-bars`, `widget-monthly-normals`); remove all `eslint-disable` suppression comments
- Add `isMinMaxEmpty()` helper to `tools/weather.ts` to detect empty `MinMaxResult` objects
- Add `no-data` translation key (`"—"`) to both `en/common.json` and `ru/common.json`
- Overhaul caching policy across `Heatmap`, `History`, and `Precipitation` controllers: introduce unified cache constants (`CACHE_TTL_RECENT`, `CACHE_TTL_HISTORICAL`, `CACHE_MIN_RANGE_HOURS`, `CACHE_RECENT_DAYS_THRESHOLD`); disable cache for ranges ≤ 48 h, use 1-hour TTL for recent data (≤ 7 days), and cache historical data indefinitely
- Add `GET /` root endpoint returning API version and status information
- Localize month labels in calendar widgets using `i18n.language` instead of hardcoded strings; remove obsolete `month-short` entries from `en` and `ru` locales
- Replace `dangerouslySetInnerHTML` Yandex.Metrika injection with `next/Script` using `strategy="afterInteractive"` for safer SSR-compatible analytics loading
- Switch `WidgetSensor` min/max history window from 12 h to 24 h; remove obsolete `fullWidth` layout wrappers from the anomaly page
- Fix locale initialisation race condition by using synchronous `getItem` and deferring i18n setup
- Improve DB error handling in CodeIgniter controllers; update CI4 lock file
- Bump client dependencies: `handlebars` 4.7.8 → 4.7.9, `picomatch` 2.3.1 → 2.3.2, `flatted` 3.3.3 → 3.4.2, `minimatch` 3.1.2 → 3.1.5, `tar` 7.4.3 → 7.5.7, `js-yaml` 3.14.1 → 3.14.2; general client dependency upgrade

## 3.7.3

### Patch Changes

- Add `GET /climate` REST endpoint with `Climate` controller and `ClimateModel`; computes annual temperature anomalies, per-year frost/hot-day counts, monthly normals, and baseline average temperature from `daily_averages` (from `START_YEAR = 2022`); response is cached for 24 hours
- Add `ClimateYearStat`, `ClimateMonthlyNormal`, and climate `Response` TypeScript interfaces; register `Climate` RTK Query tag and `useGetClimateQuery` endpoint in the API slice
- Refactor `climate` page to consume the new `GET /climate` endpoint for pre-aggregated stats; remove client-side `sessionStorage` caching, handle current-year end-date edge cases, and compute current-year monthly averages via `useMemo`
- Add `WidgetWarmingStripes` component visualising annual temperature anomalies as colour bands with hover tooltip, min/max/avg legend, and `lerpColor` / `tempToColor` / `getContrastColor` colour utilities
- Add `WidgetAnomalyBars` component rendering annual temperature anomaly bars with an ECharts trend-line overlay; add `linearRegression` least-squares utility (results rounded to 2 decimal places)
- Add `WidgetMonthlyNormals` component displaying the historical monthly temperature distribution (min/max/avg range) with a current-year overlay and i18n month labels
- Add PHPUnit tests for `ClimateModel` verifying frost/hot-day counts, anomaly sign, monthly-normals array length, and total-precipitation preservation
- Add unit tests for `WidgetWarmingStripes`, `WidgetAnomalyBars`, and `WidgetMonthlyNormals` components and their utility functions
- Expand frontend unit test suite with 26 new tests across 12 components covering dark/light theme branches, all heatmap sensor types, all `WidgetForecastTable` column presets, and loading skeleton states; fix 2 failing colour-constant assertions in `widget-warming-stripes`; statement coverage increases from 84.15% to 84.9%
- Update `README.md` with a Climate Dashboard feature section

## 3.7.2

### Patch Changes

- Add SEO patterns and update per-page `NextSeo` configuration across all pages
- Bump client dependencies
- Enable Content Security Policy with restrictive defaults (`default-src 'none'`, no inline scripts or styles) via `ContentSecurityPolicy` config
- Disable `DBDebug` in production database config to prevent SQL details from leaking in error responses
- Enable `secureheaders` after-filter to add `X-Content-Type-Options`, `X-Frame-Options`, `Strict-Transport-Security`, and `Referrer-Policy` headers to all API responses
- Add `ThrottleFilter` to rate-limit `POST /sensors` to one request per 30 seconds per IP; return HTTP 429 on excess requests
- Add `ALLOWED_INTERVALS` allowlist to `RawWeatherDataModel`, `HourlyAveragesModel`, and `DailyAveragesModel`; `getWeatherHistoryGrouped()` now throws `InvalidArgumentException` for unrecognised interval strings
- Add numeric range validation rules for sensor fields in `RawWeatherDataModel` (temperature, humidity, pressure, UV index, wind, precipitation, clouds, visibility, and more)
- Enforce a 366-day maximum date range on `GET /history` and `GET /heatmap`; return HTTP 422 when the range is exceeded
- Restore future end-date guard in `History` controller; allow dates up to end of tomorrow to account for timezone differences
- Replace raw exception messages in `Sensors` controller with a generic `Internal server error` response; log full exception details server-side only
- Register common sensitive key names (`password`, `token`, `api_key`, `key`, `mac`, etc.) in `Exceptions::$sensitiveDataInTrace` to prevent secrets from appearing in debug stack traces
- Remove unused `firebase/php-jwt` production dependency
- Update `server/.env.production` to use local database host (`127.0.0.1`) and remove obsolete `server/env` example file from the repository
- Add security audit roadmaps for server and client directories
- Add unit tests covering sensor throttling, sensor field range validation, group-interval allowlists, future end-date rejection, and 366-day range limits

## 3.7.1

### Patch Changes

- Add `WidgetForecastCards` component to the main page: horizontally scrollable daily and hourly forecast card rows with weather icons, temperature, clouds, wind, and precipitation; highlights today and the current hour
- Add reusable `Carousel` UI primitive (`ui/carousel/`) using Embla Carousel with optional auto-scroll and previous/next navigation controls
- Move `WidgetForecastTable` (hourly and daily) from the main page to the `/forecast` page
- Fix language switching: resolve router/i18n race condition by making `useLocalStorage` write synchronously and navigating via constructed URL instead of calling `i18n.changeLanguage`
- Fix `appWithTranslation` not receiving the i18n config, causing locale initialization failures in SSR
- Standardise `serverSideTranslations` calls across all pages to explicitly pass `['common']` namespace
- Add HTTP request timeouts (30 s) to OpenWeatherMap, WeatherAPI, and VisualCrossing API clients
- Add response caching to `Anomaly`, `Heatmap`, `History`, and `Precipitation` controllers with short/long TTL constants and cache-key logic
- Fix `GetForecastWeather` CLI command: use `->format('Y-m-d H:i:s')` for datetime and simplify insert/update arrays
- Replace manual `className` string concatenation with `cn()` from `simple-react-ui-kit` across `AppBar`, `LanguageSwitcher`, `WidgetAnomalyCalendar`, `WidgetAnomalyCard`, `WidgetFloodRisk`, and `WidgetParameterZScore`
- Remove unused Sass classes (`.noAnimation`, `.menubar`, `.historyTable`, `.chartLabel`, `.cardTempLow`) and unused translation key `max-daily-rain`
- Add unit tests for `WidgetForecastCards`, `Carousel`, `CarouselButtons`, `usePrevNextButtons`, `Heatmap` controller caching, and `History` controller caching

## 3.7.0

### Minor Changes

- Add Precipitation Calendar feature: full-stack implementation with PHP controller, two-level aggregation model, RTK Query endpoint, calendar grid, stat cards, streak cards, and monthly bar chart
- Add CLI weather commands (`system:getCurrentWeather`, `system:getForecastWeather`, `system:sendNarodmonData`); remove `System.php` controller
- Add skeleton loading states to anomaly page widgets
- Add active anomaly cards to homepage before forecast table, with full-width layout
- Localize month labels in `WidgetPrecipCalendar`, `WidgetAnomalyCalendar`, and `WidgetPrecipChart` using `i18n.language`
- Add precipitation calendar tooltip matching anomaly calendar pattern
- Fix daily precipitation totals computed from hourly averages to eliminate multi-source inflation
- Fix dry streak calculation by expanding sparse precipitation data into a full calendar before streak detection
- Add `forecast_time` column to forecast inserts; remove redundant type cast
- Rename generic `Props` interfaces to component-specific names across widgets
- Add widget unit tests for maximum frontend code coverage

## 3.6.0

### Minor Changes

- Implemented Meteorological Anomaly Feature, including API endpoint and UI components.
- Add PHPUnit test suite and API Checks CI workflow
- Fix PHPUnit CI failure and integrate PHP coverage into SonarCloud
- Fix PHPUnit warning: no code coverage driver in api-checks workflow
- Updated PHP Packages
- Add UI unit tests for maximum frontend code coverage
- Fixed UI Prettier issues
- Add WidgetAnomalyCalendar component and tests
- Add anomaly API, types and menu badge
- Add anomaly detection CLI, controller, migration
- Add anomaly detection, snowpack & logging
- Add unit tests for anomaly detection and models
- Add feature requirements and agent-memory docs
- Add Snowpack chart widget and tests
- Add WidgetParameterZScore component and tests
- Add flood-risk widget, utils, styles & tests
- Add WidgetAnomalyHistory component and tests
- Add WidgetAnomalyCard, utils, styles, tests
- Refactor widgets; add FloodRisk and rename files
- Add Anomaly Monitor docs and update README
- Extract anomaly i18n helper and memoize chart
- Add widget unit tests and testing notes
- I18n sync, AppBar aria i18n and test fixes

## 3.5.2

### Path Changes

- Added a shared `getEChartBaseConfig` function and refactored chart configuration for improved maintainability.
- Updated UI unit tests and introduced new summary images for 3D models.
- Created a README for the models section and integrated project documentation with Claude.AI.
- Fixed multiple bugs, including locale redirects, duplicate year entries, unmounted component updates, React ref dependencies, call-stack overflow in Heatmap, and canonical URL issues.
- Improved value filtering and min/max calculations in weather utilities, with additional unit tests for edge cases.
- Enhanced i18n support by adding missing keys and replacing hardcoded strings with translations.
- Optimized React performance by memoizing arrays and configs, moving `dayjs.extend` calls to module level, and stabilizing dependency arrays.
- Added and expanded unit test coverage for weather utilities and date formatting functions.
- Introduced a loading progress indicator and sessionStorage caching for the climate page, improving user experience during sequential data fetches.
- Cleaned up ROADMAP tracking entries and removed duplicate or obsolete code.

## 3.5.1

### Patch Changes

-   Updated UI Dependencies
-   Replaced DatePicker UI component from UI Kit
-   Migrate from node `20` to `22`
-   Improved WidgetSensor - added new prop `size`
-   Added new Sensor - `visibility`
-   Updated Sensors page - added link for the Sensor Widget

## 3.5.0

### Minor Changes
-   Added new UI Page - `climate`
-   Updated UI Dependencies
-   Implemented some UI Unit tests
-   Fixed ESLinter and Prettier
-   Fixed collect coverage method for UI Jest
-   Update sonar-project.properties
-   Upgraded NextJS from `15` to `16`
-   Updated UI locales

## 3.4.11

### Path Changes
-   Updated UI Dependencies

## 3.4.10

### Path Changes
-   Updated UI Libraries
-   Fixed `thunderstorm` weather icons
-   Improved UI `Popout` component
-   Created `PeriodSelector` UI component

## 3.4.9

### Path Changes
-   Upgraded yarn version from `4.8.1` to `4.9.1`
-   Updated ESLint and Prettier config
-   Removed unused UI functions and types
-   Implemented UI useLocalStorage hook
-   Updated UI `light` and `dark` themes
-   Updated UI libraries and SimpleUIKit version
-   Refactoring UI code-style, fixed code by Prettier and ESLint
-   Refactoring UI API, added new ENV variable -> `NEXT_PUBLIC_STORAGE_KEY`
-   Updated README.md

## 3.4.8

### Path Changes
-   Fixed Calendar UI Component type
-   Updated UI Libraries
-   Updated README.md
-   Updated yarn version from `4.5.0` to `4.8.1`
-   Improved UI themes and website manifest

## 3.4.7

### Path Changes

-   Implemented getForecastWeatherData method for VisualCrossingAPILibrary
-   Fixed CI/CD API Deploy
-   Updated UI Libraries

## 3.4.6

### Path Changes

-   Fixed API NarodMonLibrary
-   Updated UI Libraries
-   Improved CI/CD API Deploy GitHub Action
-   Fixed API Kint Config
-   Changed Arduino firmware send data method
-   Implemented API Sensors Controller
-   Upgraded and added new one API Route
-   Add visualCrossingApi for API get Weather tasks
-   Added PHPDoc for WeatherData Entity
-   Updated Readme, added new params for Server .env

## 3.4.5

### Path Changes

-   Updated UI Libraries
-   Upgraded API Libraries
-   Removed unused API dependencies
-   Fixed API Locale
-   Implemented new API Library for narodmon.ru
-   Improved API RawWeatherDataModel (new function `getCurrentActualWeatherData`)
-   Added new API Endpoint: `CLI system/narodmon`
-   Written documentation (PHPDoc) for the API Classes
-   Added new parameters (for NarodMonLibrary) to the .env file

## 3.4.4

### Path Changes

-   Updated UI Libraries
-   Redesigned footer, added links

## 3.4.3

### Path Changes

-   Implemented Not Found Page

## 3.4.2

### Path Changes

-   Added Arduino code check
-   Fixed Arduino code for testing GYML8511 UV sensor
-   README documentation has been improved
-   Added Arduino BMP085 and PCF8574 libraries to the repository

## 3.4.1

### Path Changes

-   Fixed Jest config
-   Fixed types for UI setItem function
-   Added some UI Unit tests
-   Added descriptions (TSDoc) for UI helpers functions

## 3.4.0

### Minor Changes

-   Implemented new Meteogram Widget
-   Created new Forecast page
-   Refactoring WeatherIcon, added getWeatherIconUrl function
-   Refactoring WidgetChart and WidgetForecastTable
-   Columns for WidgetForecastTable are moved to the component, a set of columns is created
-   Created getSampledData UI function
-   Updated README, CHANGELOG and fixed styles
-   Updated UI libraries

## 3.3.4

### Path Changes

-   Updated UI libraries
-   Improved CSS themes
-   Changed sensors min and max values to last 12 hours
-   Optimized UI filterRecentData function

## 3.3.3

### Path Changes

-   Updated UI libraries
-   Fixed height of base component
-   Added memoization data for UI WeatherChart
-   Changed UI Tests names
-   Added UI function for interpolation charts data (invertData)
-   Improved SonarCloud configuration file
-   Fixed issues in the UI WidgetSummary and WindDirectionIcon components
-   Improved and fixed client config files
-   Added UI Unit tests for Footer and WindDirectionIcon components
-   Migrate to new version of Next.js (15)
-   Updated GitHub CI/CD Actions
-   Fixed code-style

## 3.3.2

### Path Changes

-   Updated UI libraries
-   Updated API dependencies
-   Added new API Endpoint: 'GET /current/text'
-   Added new API Method: getCurrentTextWeather

## 3.3.1

### Path Changes

-   Added animated weather icons
-   Created SECURITY.md
-   Updated UI libraries
-   Removed unused UI Container component
-   Removed unused UI Badge Component
-   Updated locales
-   Improved UI styles and themes
-   Improved UI components styles
-   Removed UI convertWindDirection function
-   Changed main screen image
-   Upgrade index page
-   Updated UI WeatherIcon, Chart, WidgetSummary and WindDirection
-   Updated README.md

## 3.3.0

### Minor Changes

-   Implemented new API Endpoint - Heatmap
-   Connect UI to new API endpoint
-   Implemented new UI Widget Heatmap Component
-   Added new UI page - Heatmap
-   Improved UI locales
-   Optimized and improved UI styles
-   Improved UI tools and utilities functions
-   Improved WidgetChart UI Component
-   Optimized UI pages
-   Improved README, fixed ESLint config
-   Improved Widgets, AppBar and Layouts components
-   Removed unused UI components and install Simple React UI Kit library
-   Added new UI ComparisonIcon Component
-   Added CI/CD release action

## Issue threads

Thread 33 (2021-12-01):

Refact backend for fix SonarCube errors

miksrv, 2021-12-01:
SonarCube link: https://sonarcloud.io/summary/new_code?branch=master&id=miksrv_arduino-weather-station

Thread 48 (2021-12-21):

Backend method get_sensor has crashed if sensors not allowed

miksrv, 2021-12-21:

Closed 2022-01-18.

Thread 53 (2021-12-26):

Refact backend for fix SonarCube errors

miksrv, 2021-12-26:

Closed 2022-02-12.

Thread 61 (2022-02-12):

There are multiple requests in case of an error getting statistics

miksrv, 2022-02-12:

Closed 2024-08-29.

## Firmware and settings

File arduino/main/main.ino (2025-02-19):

// ******************************************** //
//  Name    : WEATHER STATION
//  Author  : Misha Topchilo <miksoft.tm@gmail.com>
//  Version : 1.3.2 (11 Feb 2025)
// ******************************************** //

// This is the wiring scheme between the sensors and the Arduino
// Sensors      Arduino
//  [R] Red   -> VCC +5V
//  [W] White -> GND
//  [G] Green -> Data / I2C: SCL
//  [B] Blue  -> Data / I2C: SDA
//
// Sensor connections:
// 1. BMP085 (Barometric pressure sensor) [G, B] -> I2C (SCL, SDA)
// 2. BH1750 (Light sensor) [G, B] -> I2C (SCL, SDA)
// 3. Wind vane (for wind direction) [G, B] -> I2C (SCL, SDA)
// 4. Anemometer (for wind speed) [G] -> Digital PIN 3 (interrupt)
// 5. DHT22 (Temperature and humidity sensor) [G] -> Digital PIN 4
// 6. GUML8511 (UV sensor) [G] -> Analog PIN A0 (UV OUT), [B] -> Analog PIN A1 (UV Reference)

// Include necessary libraries
#include "Wire.h"         // For I2C communication
#include "BMP085.h"       // For barometric pressure sensor BMP085
#include "TroykaDHT.h"    // For temperature and humidity sensor DHT22
#include "BH1750.h"       // For light sensor BH1750
#include "PCF8574.h"      // For I2C expansion (used for wind vane)
// Ethernet libraries for networking
#include "SPI.h"
#include "Ethernet.h"

// Uncomment to enable debug messages sent to the serial monitor
// #define DEBUG

const long SEND_DATA_INTERVAL = 60; // Interval (in seconds) to send data to the server
const char API_SERVER[] = "api.meteo.miksoft.pro"; // API server address
const char API_METHOD[] = "/sensors";  // API endpoint to send sensor data
const char API_SECRET[] = "";  // API token for authorization (must be provided)

// Pin assignments for different sensors
const int PIN_ANEMOMETR = 3; // Digital PIN for the anemometer (wind speed sensor)
const int PIN_DHT22 = 4;     // Digital PIN for the DHT22 sensor (temperature and humidity)
const int PIN_UV_OUT = A0;   // Analog PIN for UV sensor output
const int PIN_UV_REF = A1;   // Analog PIN for UV reference voltage

// MAC address for the Ethernet shield
byte MAC[] = { 0x38, 0x59, 0xF9, 0x6D, 0xD7, 0xFF };
// Static IP address for the weather station
IPAddress IP(10,10,1,70);

// Initialize Ethernet client
EthernetClient LAN;

// Sensor objects
DHT dht(PIN_DHT22, DHT22);   // Initialize the DHT22 sensor
PCF8574 expander(0x20);      // Initialize the I2C expander for wind vane
BMP085 dps = BMP085();       // Initialize the BMP085 pressure sensor
BH1750 lightmeter;           // Initialize the BH1750 light sensor

// Variables for storing sensor data and transmission
int rps_impulses = -1;       // Impulse count for anemometer (used to calculate wind speed)
unsigned long previousMillis; // Variable for tracking time between data transmissions
char webclient_data[120], temp[6], humd[6], mmHg[6], // Data buffers for various sensor readings
     lux[5], uvindex[5], wind_dir[5], wind_speed[5]; // Buffers for light, UV index, wind direction, and wind speed

void setup() {
  // Start the serial port for debug messages if DEBUG is enabled
  #ifdef DEBUG
    delay(1000);
    Serial.begin(9600);
    delay(2000);
    Serial.println("Arduino weather init...");
  #endif

  // Configure UV sensor pins as inputs
  pinMode(PIN_UV_OUT, INPUT);
  pinMode(PIN_UV_REF, INPUT);
  delay(200);

  #ifdef DEBUG
    Serial.println(" - OK: Digital PINs");
  #endif

  // Initialize the BH1750 light sensor
  lightmeter.begin();
  delay(1000);

  #ifdef DEBUG
    Serial.println(" - OK: BH1750");
  #endif

  // Initialize I2C communication
  Wire.begin();
  delay(1000);

  #ifdef DEBUG
    Serial.println(" - OK: Wire");
  #endif

  // Initialize the BMP085 pressure sensor
  dps.init();
  delay(1000);

  #ifdef DEBUG
    Serial.println(" - OK: BMP085");
  #endif

  // Initialize the DHT22 temperature and humidity sensor
  dht.begin();
  delay(1000);

  #ifdef DEBUG
    Serial.println(" - OK: DHT22");
  #endif

  // Initialize the I2C expander for the wind vane
  expander.begin();
  delay(100);
  for (int i=0; i<8; i++) {
    expander.pinMode(i, INPUT_PULLUP);  // Set each pin as input with pull-up resistor
    delay(100);
  }

  #ifdef DEBUG
    Serial.println(" - OK: PCF8574");
  #endif

  // Initialize the Ethernet connection using a static IP address
  Ethernet.begin(MAC, IP);

  #ifdef DEBUG
    Serial.print(" - OK: Web client (IP: ");
    Serial.print(Ethernet.localIP());
    Serial.println(")");
  #endif

  delay(1000);

  #ifdef DEBUG
    Serial.println("Initialization complete");
  #endif
}

// Main loop function
void loop() {
  unsigned long currentMillis = millis();  // Get the current time

  // Check if it's time to send data
  if (currentMillis - previousMillis >= SEND_DATA_INTERVAL * 1000) {
    previousMillis = currentMillis;  // Update the last send time

    #ifdef DEBUG
      Serial.println(" ");
      Serial.println("Start reading sensors:");
    #endif

    // Read data from each sensor
    get_sensor_anemometer();
    get_sensor_wind_direction();
    get_sensor_uvindex();
    get_sensor_pressure();
    get_sensor_dht22();
    get_sensor_luxmeter();

    // Send the data to the web server
    webclient_send_data();

    #ifdef DEBUG
      Serial.println(" ");
    #endif
  }
}

// Function to read wind speed from the anemometer
void get_sensor_anemometer() {
  rps_impulses = -1;  // Reset the impulse count

  attachInterrupt(digitalPinToInterrupt(PIN_ANEMOMETR), rps, RISING);  // Attach interrupt to count pulses
  delay(5000);  // Wait 5 seconds to accumulate data
  detachInterrupt(digitalPinToInterrupt(PIN_ANEMOMETR));  // Detach interrupt after measurement

  dtostrf(rps_impulses, 0, 0, wind_speed);  // Convert the impulse count to a string for transmission

  #ifdef DEBUG
    Serial.print(" - Wind speed: ");
    Serial.print(wind_speed);
    Serial.println(" RPS");  // Display the wind speed in Revolutions Per Second
  #endif

  delay(500);
}

// Interrupt service routine for counting wind speed pulses
void rps() {
  rps_impulses++;  // Increment the pulse count each time the anemometer triggers an interrupt
}

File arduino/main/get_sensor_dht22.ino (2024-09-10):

// Function to read and process data from the DHT22 sensor
void get_sensor_dht22() {
  // Read data from the DHT22 sensor
  dht.read();

  // Check if the sensor data is valid
  if (dht.getState() == DHT_OK) {
    // Convert the temperature in Celsius and humidity to strings for further use
    dtostrf(dht.getTemperatureC(), 0, 1, temp);
    dtostrf(dht.getHumidity(), 0, 1, humd);

    // Debugging block: Print the temperature and humidity to the Serial Monitor if DEBUG is enabled
    #ifdef DEBUG
      Serial.print(" - Temperature: ");
      Serial.print(temp);  // Output the temperature in Celsius
      Serial.println(" C");
      Serial.print(" - Humidity: ");
      Serial.print(humd);  // Output the humidity percentage
      Serial.println(" %");
    #endif
  } else {
    // Debugging block: Print an error message to the Serial Monitor if DEBUG is enabled
    #ifdef DEBUG
      Serial.println(" - [ERROR] DHT22 no data");
    #endif
  }

  // Wait for 500 milliseconds before the next sensor reading
  delay(500);
}

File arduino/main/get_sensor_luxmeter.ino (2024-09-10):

// Function to read and process the light level from the sensor
void get_sensor_luxmeter() {
  // Read the light level from the light meter sensor
  uint16_t lux_val = lightmeter.readLightLevel();

  // Convert the light level (lux) to a string for further use
  dtostrf(lux_val, 0, 0, lux);

  // Debugging block: Print the light level to the Serial Monitor if DEBUG is enabled
  #ifdef DEBUG
    Serial.print(" - Lightmeter: ");
    Serial.print(lux);  // Output the light level in lux
    Serial.println(" lux");
  #endif

  // Wait for 500 milliseconds before the next sensor reading
  delay(500);
}

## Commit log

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2020-04-12 Change actions URL, bug fixes
    [main.ino]
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2021-01-26 Fix firmware webclient ID
    [main.ino, webclient_send_data.ino]
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2021-08-23 feat: Updated components and styles
    Dynamic subheading for heatmap
    Selectable date range for heatmap
    Added a function to change the endings of words (declOfNum)
    Methods for updating heatmap state when selecting a range
    Fixed stupidity in the calendar
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2021-11-07 fix: #5 refract arduino firmware
    [get_sensor_dht22.ino, get_sensor_luxmeter.ino, get_sensor_pressure.ino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]
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2021-11-10 fix: #6 Add config descripition, refactoring code
    [main.ino, webclient_send_data.ino]
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2021-11-29 fix bug in time heatmap, counter of iteration in statistic mean cycle
2021-12-06 fix #36: Update endpoint API for export statistic data
    API endpoint in toolbar now taken in global variables (environment). In heatap feature toolbar config remove export button props
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2024-12-16 Added Libraries for Arduino
    Changed libraries
    Create PCF8574_Library.zip
    Libraries
    Replaced library
    Update BMP085_Library.zip
    Update test_gyml8511.ino
    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
    [test_gyml8511.ino]
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2026-03-15 fix(client): resolve BUG-01 through BUG-06 from ROADMAP
    - BUG-01: fix locale redirect in _app.tsx to use router.push with
    locale option instead of appending storageLocale as a query param;
    add missing deps to useEffect dependency array
    - BUG-02: guard against duplicate year entries in climate.tsx by
    checking prev.some(d => d.year === year) before appending
    - BUG-03: store setTimeout return value and return clearTimeout from
    useEffect cleanup to prevent updates on unmounted component
    - BUG-04: replace containerRef.current with [] in Meteogram useEffect
    dependency array — refs are not observable by React
    - BUG-05: replace Math.min/max spread with Array.reduce in Heatmap.tsx
    visua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
2026-03-16 fix(client): BUG-07 — getMinMaxValues skips undefined/null sensor values
    Pre-filter items whose target parameter is undefined or null before
    initialising minValue/maxValue, mirroring the pattern used by
    findMinValue. Previously, if the first item's sensor field was
    undefined the cast to number produced NaN, making all subsequent
    comparisons return false and leaving the result stuck at the first
    item regardless of the array contents. A second guard now returns {}
    when every item in the array lacks a valid value for the parameter.
    Added eight unit tests to tools/weather.test.ts covering: undefined
    data, empty array, undefined parameter, all-undefined values, normal
    min/max selection, skippi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
2026-03-16 fix(client): resolve BUG-08, BUG-09, and BUG-10
    BUG-08 — round() returns undefined for value 0
    The truthiness check `value ? ...` treated 0 as falsy, silently
    dropping legitimate 0°C readings. Changed to `value !== undefined &&
    value !== null` so round(0) correctly returns 0. Added two regression
    tests to helpers.test.ts.
    BUG-09 — Document why extractRehydrationInfo requires an any return type
    Replacing the bare eslint-disable with a detailed comment explaining
    the root cause: an explicit return-type annotation causes TypeScript to
    widen the Definitions generic and breaks all endpoint hook inference.
    This is a structural consequence of the api.ts ↔ store.ts circular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
2026-03-16 feat(client): add loading progress indicator and sessionStorage cache to climate page (FEAT-01)
    - Show "Loading X of Y years..." spinner in WidgetClimate while fetching years sequentially
    - Keep the chart visible (not skeleton) after partial data is available, skeleton only for first load
    - Fix the `loading` prop — now stays true throughout all sequential year fetches, not just the first
    - Cache fully-loaded climate data in sessionStorage so navigating away and back skips re-fetching
    - Add `loadedYears` and `totalYears` props to WidgetClimate component
    - Add `loading-years` i18n key to both en and ru locale files
    - Remove FEAT-01 from ROADMAP.md
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2026-03-16 Fix PHPUnit CI failure and integrate PHP coverage into SonarCloud
    ## Problem
    The API Checks workflow was failing with exit code 1 due to a PHPUnit
    warning: "No filter is configured, code coverage will not be processed".
    **Root cause:** PHPUnit 10+ replaced `<coverage><include>` with a
    top-level `<source>` element for defining which files to measure. The
    old `<coverage includeUncoveredFiles="true"><include>` syntax is no
    longer recognised as a source filter, so PHPUnit had no files to
    instrument and emitted the warning — which GitHub Actions treats as a
    non-zero exit.
    ## Changes
    ### `server/phpunit.xml.dist`
    - Extracted `<include>` and `<exclude>` from `<coverage>` into a new
    top-leve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
2026-03-16 Fix PHPUnit warning: no code coverage driver in api-checks workflow
    The <coverage><report> block in phpunit.xml.dist causes PHPUnit to
    attempt coverage collection even when no --coverage-* flag is passed
    on the CLI. With coverage: none in the workflow (no Xdebug installed),
    this produced a "No code coverage driver available" warning and exit
    code 1.
    Added --no-coverage to the PHPUnit command in api-checks.yml so
    PHPUnit explicitly skips coverage regardless of what phpunit.xml.dist
    declares. Coverage generation remains the sole responsibility of the
    sonarcloud.yml workflow, which installs Xdebug and passes
    --coverage-clover.
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2026-03-17 Add anomaly detection, snowpack & logging
    Introduce meteorological anomaly monitoring and snowpack/flood-risk tooling. Adds AnomalyDetector (Z-score analysis, pressure/precipitation/wind/fog/fire/heat/frost checks, SPI, and helpers), SnowpackCalculator (SWE accumulation/melt degree-day model and rain-on-snow metrics), AnomalyLogModel (persistence for open/closed anomaly episodes and calendar queries), and AnomalyModel (orchestration to compute current flood risk and assemble API response). Also adds a sample server/.env.production configuration. These additions enable automated detection, logging, and flood-risk scoring based on historical daily/hourly aggregates.
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2026-03-17 Add flood-risk widget, utils, styles & tests
    Introduce a new WidgetFloodRisk component with subcomponents (FloodRiskGauge and FloodRiskBars) to render a flood-risk gauge and contribution bars using ECharts. Add utils (resolveCssVar, getRiskLevelColor, clampContribution) to handle CSS variable resolution (SSR-safe) and value clamping. Include styles.module.sass for layout and appearance, and add Jest/React Testing Library tests for the component and utils with appropriate mocks for ECharts, theming and i18n.
2026-03-18 Include forecast_time for inserts; remove cast
    Merge forecast_time into the data for new forecast records in System controller so inserted rows include the forecast_time field. Also remove the 'forecast_time' => 'datetime' entry from ForecastWeatherDataModel::$casts to stop automatic DateTime casting (avoids type/casting issues when storing the timestamp string).
2026-03-18 Add skeleton loading states to widgets
    Introduce skeleton loading UX across multiple widgets and the anomaly page. Components now accept an optional loading?: boolean prop and render Skeleton placeholders from simple-react-ui-kit when loading is true. Updated components: WidgetAnomalyCalendar, WidgetAnomalyCard, WidgetAnomalyHistory, WidgetFloodRisk, WidgetParameterZScore, WidgetSnowpackChart and the anomaly page to pass isLoading -> loading and render skeleton lists for items. Also updated frontend-agent.md with guidelines for skeleton usage, sizing, and page-level patterns. Data props were made optional and safe fallbacks added where needed to avoid runtime errors during loading.
2026-03-18 Rename generic Props interfaces to specific names
    Rename ambiguous Props interfaces to component-specific names (WidgetParameterZScoreProps and WeatherChartProps) and update the React.FC generic types in WidgetParameterZScore.tsx and WeatherChart.tsx. No runtime logic changes; this improves type clarity and helps avoid naming collisions.
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2026-03-18 Add precip chart/stat widgets and refactor UI
    Introduce WidgetPrecipChart and WidgetPrecipStatCard (components, index and styles) and extract calendar helpers (isLeapYear, getCellColor). Refactor WidgetPrecipCalendar to use the new utils, improve skeleton/layout markup and clean up imports. Update precipitation page to use new widgets, replace inline chart/stat code with components, use Button from UI kit and switch to API.isFetching. Adjust streak card styles and minor type formatting changes. Add i18n plural forms for days-count in English and Russian.
2026-03-18 Compute daily precipitation from hourly averages
    Switch daily totals to be computed from raw_weather_data by first averaging precipitation per calendar hour across sources, then summing those hourly averages per day (prevents source duplication). Add _buildFullCalendar() to expand dailyTotals into a complete calendar (missing days filled with 0.0, future days pruned) so stats (dry-day counts and streak detection) are correct. Adjust streak logic to treat any amount > 0 as a wet day (dry = 0) and compute streaks against the full calendar. Update RawWeatherDataModel docblock to note AVG() usage and lack of source references. Add a unit test to ensure trace amounts (0.1 mm) break dry streaks an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
2026-03-18 Localize labels, add precip tooltips, refactor styles
    Use i18n.language for month labels across anomaly calendar, precip calendar and precip chart. Add interactive, positioned tooltip to WidgetPrecipCalendar (with formatted date and total) and replace title hover with mouse handlers. Make WidgetPrecipChart theme-aware (useTheme) and improve tooltip formatter, axis and grid styling. Refactor multiple SASS modules to nested structure and unify component class names (e.g. statCard -> widget, statTitle/value -> title/value) and adjust typographic weights. Remove precipitation.module.sass and inline the year selector styles; remove the locale prop from WidgetPrecipChart. Miscellaneous minor updat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
2026-03-19 Add HTTP timeouts and caching tests
    Set a 30s request timeout for OpenWeather, VisualCrossing and WeatherAPI client calls to avoid hanging requests. Add unit tests for Heatmap and History controllers to verify caching behavior: use cached data without calling the model, ensure CACHE_TTL_SHORT and CACHE_TTL_LONG values, and confirm empty model results are not cached. Tests also seed and clean up cache entries. Files changed: OpenWeatherAPILibrary.php, VisualCrossingAPILibrary.php, WeatherAPILibrary.php, HeatmapControllerTest.php, HistoryControllerTest.php.
2026-03-19 Add climate feature spec and controller caching
    Add requirements/feature_7.md describing the new /climate API, frontend widgets, RTK query types, i18n keys and acceptance criteria. Update server controllers and command: fix GetForecastWeather to use ->format('Y-m-d H:i:s') and simplify insert/update arrays; add caching support and TTL constants to Anomaly (index & history), Heatmap (short/long TTL with key based on type/start/end), History (cache by start/end with conditional TTL), and Precipitation (year-based cache with conditional TTL for current year). Also refactor variable names and cache key construction to avoid repeated queries and save computed responses.
2026-03-19 Add hourly table and switch index to forecast cards
    Move the hourly forecast table into the /forecast page and add WidgetForecastTable there. On the index page, replace the daily forecast table with WidgetForecastCards (import replaced) and adjust props (data -> forecast). Also comment out the hourly forecast API polling on the index page. These changes separate hourly details to the forecast page and use a compact card view on the dashboard.
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2026-03-20 Add SEO patterns and update per-page NextSeo
    Introduce SEO conventions and implement consistent per-page metadata across the Next.js client. Added project_seo_patterns.md and updated MEMORY.md; created pages/_document.tsx and added DefaultSeo in _app.tsx. Updated NextSeo usage on index, sensors, forecast, history, heatmap, climate, anomaly, precipitation and 404 pages to use page-specific titles/descriptions/canonical/openGraph.url, absolute OG image URLs, and twitter.cardType='summary_large_image'. Also set 404 to noindex. Minor footer accessibility/rel fixes and added climate copy to locale files. Updated public/sitemap.xml with lastmod/changefreq/priority adjustments and new entries for p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
2026-03-22 Enable CSP, add throttle, hide sensitive data
    Security hardening and API adjustments: enable Content Security Policy and set restrictive defaults (no inline scripts/styles) in ContentSecurityPolicy; disable DB debug in Database.php; add common sensitive keys to Exceptions::$sensitiveDataInTrace to avoid leaking secrets; register a ThrottleFilter and apply it to the sensors endpoint, import the filter, and document intentional CSRF disablement for this stateless REST API (token auth + CORS allowlist). These changes reduce information exposure and add request-rate protection.
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2026-03-22 Add unit tests for validation & throttling
    Extend multiple unit tests to cover validation, range checks, interval allowlists, and date-range constraints. DailyAveragesModelTest, HourlyAveragesModelTest, and RawWeatherDataModelTest: add SEC-08 interval allowlist tests (and in RawWeatherData add SEC-06 physical range data provider). HistoryControllerTest and HeatmapControllerTest: add tests for future end-date and date ranges exceeding 366 days (SEC-07 / SEC-14). SensorsControllerTest: inject a fresh Throttler in setUp to reset rate-limit state and add a test that verifies a second POST from the same IP returns 429. Comments and imports updated as needed.
2026-03-22 Validate group intervals and tighten field rules
    Introduce ALLOWED_INTERVALS to DailyAveragesModel, HourlyAveragesModel and RawWeatherDataModel and validate the groupInterval in getWeatherHistoryGrouped (throws InvalidArgumentException if not one of '10 MINUTE', '1 HOUR', '1 DAY', check uses strtoupper). Also tighten RawWeatherDataModel validation rules by adding reasonable numeric bounds for temperature, feels_like, pressure, humidity, uv_index, precipitation, clouds, visibility, wind_speed, wind_deg and wind_gust to improve data integrity.
2026-03-22 Enforce max 366-day date range and improve errors
    Heatmap: add validation to reject date ranges longer than 366 days.
    History: update method signature to return array|ResponseInterface; allow dates up to end of tomorrow to account for timezone differences; validate both start and end against the max allowed timestamp; add same 366-day maximum range check; keep existing min-date validation.
    Sensors: improve error logging context and return a generic internal server error message to clients instead of exposing exception details.
2026-03-22 Use local DB host and remove example env
    Update server/.env.production to use a local database: set production hostname to 127.0.0.1, change production database name to 'db', and align development port to 3306 (was 3309). Remove the obsolete example environment file server/env to avoid keeping unused/sample config in the repo.
2026-03-22 Release v3.7.2: update changelog and bump client
    Update CHANGELOG for v3.7.2 and bump client package version to 3.7.2. Highlights include SEO updates, stricter Content Security Policy defaults, secure headers, rate-limiting for POST /sensors, sensor field numeric validation and interval allowlists, 366-day history limits with future-date guard, improved error handling and secret redaction in traces, removal of an unused production dependency, env/server config tweaks, and added security audit roadmaps and unit tests.
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2026-03-23 Add tooltip CSS pattern and .value classes
    Introduce a project guidance file for ECharts tooltip CSS and register it in the frontend agent memory. Define the missing .value class in widget-chart, widget-climate, and widget-heatmap SASS modules (prevents styles.value resolving to undefined in ECharts tooltip HTML). Also add a .section rule to widget-forecast-cards styles. Remove several redundant climate-related localization keys/descriptions from en and ru common.json as part of cleanup.
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2026-03-24 Use sync getItem and defer locale init
    Replace the useLocalStorage hook with a synchronous getItem util and add locale readiness handling to avoid rendering before the correct locale is applied. Introduces client/tools/localstorage.ts (getItem) which reads DEFAULT_STORAGE_KEY and parses stored JSON. In _app.tsx: add isLocaleReady state, determine saved locale on mount, redirect with router.replace when needed, set dayjs locale appropriately, and show a minimal loader/ThemeProvider until locale is confirmed to prevent UI flash.
2026-03-24 Improve DB error handling & update CI4 lock
    Replace print_r-based error logs with json_encode for clearer output, and explicitly capture insertBatch/updateBatch return values (checking === false) to reliably detect failures. Also update composer.lock to bump codeigniter4/framework to v4.7.2 (updated reference and timestamp).
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2026-03-29 Localize month labels using i18n language
    Use i18n from useTranslation and generate month labels with Date.toLocaleString(i18n.language, { month: 'long' }) instead of t(`month-short-*`). This ensures month names are localized to the current language and updates the useMemo dependency to i18n.language so labels recompute when the locale changes.
2026-04-02 Improve caching logic & add API root endpoint
    Add a root API info endpoint and overhaul caching behavior across controllers. Introduce unified cache constants (CACHE_TTL_RECENT, CACHE_TTL_HISTORICAL, CACHE_MIN_RANGE_HOURS, CACHE_RECENT_DAYS_THRESHOLD) and new TTL policy: disable caching for short ranges (<=48 hours) to avoid timezone issues, use a 1-hour TTL for recent data (within last 7 days), and cache older/historical data indefinitely. Apply these changes and corresponding cache key/TTL logic to Heatmap, History and Precipitation, and adjust response flow to bypass the cache for short-range requests.
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2026-04-05 Add isMinMaxEmpty and fix findMin/Max returns
    Introduce isMinMaxEmpty to detect empty MinMaxResult objects. Change findMinValue and findMaxValue to filter out undefined values and return undefined when no valid numbers exist (instead of Infinity/-Infinity). Update tests to cover isMinMaxEmpty and to expect undefined for empty or all-undefined datasets; adjust imports accordingly.
2026-04-05 Show no-data fallback in WidgetSummary and test
    Display the 'no-data' translation when weather values are missing and add a unit test. Replace explicit type cast for weatherId, and update Badge labels to fall back to t('no-data') for windSpeed, precipitation, humidity and pressure (pressure uses convertHpaToMmHg(... ) || t('no-data')). Add a test that renders WidgetSummary with an empty weather object and asserts that the no-data fallback is rendered for the badges.
2026-04-05 Show em-dash for empty min/max and no-data
    Use i18n fallback t('no-data') instead of literal '??' for missing current value. Always render the min/max stats block and show em-dash (—) placeholders when minMax is missing or empty (or when individual value/date is undefined). Import and use isMinMaxEmpty to detect empty minMax. Update tests to expect the 'no-data' label and to assert em-dash placeholders for empty or absent minMax.
2026-04-05 Type tooltip formatters and handle params safely
    Add ECharts tooltip typings and safer parameter handling across several charts (Heatmap, Meteogram, MonthlyNormals, PrecipChart). Replaced any with TopLevelFormatterParams and CallbackDataParams, added AxisCallbackDataParams in Meteogram, and normalized access to item.color/item.name/item.value/seriesName with String casts and null checks. Removes many eslint-disable comments and reduces risk of runtime errors in tooltip formatters by handling array params and missing values explicitly.
2026-04-05 Tighten ECharts tooltip types and prop typings
    Replace unsafe any usage in ECharts tooltip formatters with proper types (TopLevelFormatterParams and CallbackDataParams), add AxisCallbackDataParams alias, normalize params to arrays, and stringify/guard values to avoid runtime undefined issues. Also update WeatherIcon prop typing in WidgetForecastTable to accept number | undefined. Changes applied to WidgetAnomalyBars.tsx, widget Chart components (widget-chart/Chart.tsx and widget-climate/Chart.tsx), and WidgetForecastTable.tsx to improve type safety and tooltip rendering.
2026-04-05 chore(client): upgrade dependencies
    Bump several client dependencies and update yarn.lock accordingly for maintenance. Notable upgrades: next 16.2.1 → 16.2.2, i18next 25.10.4 → 25.10.10, lodash-es 4.17.23 → 4.18.1, react-i18next 16.6.1 → 16.6.6, simple-react-ui-kit 1.7.10 → 1.7.12, @eslint/compat 2.0.3 → 2.0.4, @next/eslint-plugin-next 16.2.1 → 16.2.2, @types/node 24.12.0 → 24.12.2, typescript-eslint packages → 8.58.0, ts-jest → 29.4.9, sass → 1.99.0, ts-api-utils → 2.5.0, eslint-plugin-jest → 29.15.1, and added semver 7.7.4. These are routine dependency refreshes to pick up fixes and compatibility updates; no code behavior changes intended.
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2026-05-11 Refactor controllers: DI, models, and response handling
    Refactor Anomaly, Climate, and Current controllers to improve DI, reuse model instances, and standardise response/error handling. Key changes:
    - Add protected $format='json' and type-hinted model properties; initialise models in constructors (Climate, Current, Anomaly shared daily/hourly models).
    - Reuse DailyAveragesModel/HourlyAveragesModel instances and pass them into AnomalyDetector and AnomalyModel instead of creating new instances.
    - Import DateTime, Exception and Entity classes and standardise entity -> toRawArray conversions.
    - Update Anomaly: _fetchTodayRow accepts a date string and returns an associative array; _buildAnomalyLi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
2026-05-11 Refactor Forecast and Heatmap controllers
    Clean up Forecast and Heatmap controllers: set response format to JSON, initialize models in constructors, and simplify docblocks. Improve error handling and logs (use Exception::getMessage with method context) and tighten validation (strict in_array, unified failValidationErrors). Normalize date handling, rename raw date vars, adjust cache key generation and TTL logic, and bypass caching for short ranges. Overall improvements to readability and reliability of forecast/heatmap endpoints.
2026-05-11 Refactor History, Precipitation, and Sensors
    Clean up and simplify controller implementations: initialize models in constructors and add consistent $format property; improve History controller by clarifying docs, consolidating caching logic, validating params with clearer errors, making _getData private, and returning grouped data early (10min/1h/1d). Update CSV export to use fetched data and an in-memory stream. Precipitation now uses an injected model instance and clearer year-end TTL logic. Sensors now validates token with clearer logs, reuses model/entity instances, normalizes DateTime usage, and improves validation/error handling. Overall changes reduce duplication, improve readability,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
2026-05-12 Replace NextSeo with generateNextSeo; update imports
    Migrate page components to use next-seo's generateNextSeo inside next/head instead of the NextSeo component, and update next-i18next imports to the /pages entrypoints (including serverSideTranslations). Changes applied to history, index, precipitation and sensors pages; existing SEO metadata (title, description, canonical, openGraph, twitter) preserved. No other UI or business logic changes.
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
